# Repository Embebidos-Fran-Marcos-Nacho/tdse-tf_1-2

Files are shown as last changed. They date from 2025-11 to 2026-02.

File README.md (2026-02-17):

# Dimmer + Switch (Ventilador & Luces)  
Control de ventilador y luces de línea (220 V) desde pared y vía Bluetooth

<div align="center">



**UNIVERSIDAD DE BUENOS AIRES**  
**Facultad de Ingeniería**  
**TA134 – Sistemas Embebidos**  
Curso 1 – Grupo 2

</div>

## Autores
- Ignacio Ezequiel Cavicchioli — Legajo 109428  
- Francisco Javier Moya — Legajo 109899  

---

# 1. Selección del proyecto a implementar

## 1.1 Objetivo del proyecto y resultados esperados

Este proyecto implementa un módulo de control de **ventilador** y **luces de línea (220 V)** que permite operar:

- Desde la pared, por medio de un **botón físico** y un **potenciómetro**  
- Desde un dispositivo móvil mediante **Bluetooth (MIT App Inventor)**

Resultados esperados:

- Control de velocidad del ventilador.  
- Encendido/apagado de luces y ventilador.  
- Feedback mediante **LEDs** y **buzzer** para estados y alertas.  
- Permitir **deshabilitar o configurar el BT** mediante un DIP switch.  
- Guardado en memoria del último estado usado.  
- Funcionamiento seguro sobre cargas de 220 V.

---

## 1.2 Proyectos similares

Para establecer un punto de referencia, se identificaron dos soluciones comerciales que resuelven parcialmente el mismo problema que aborda este proyecto. Ambas están disponibles en el mercado, pero presentan diferencias significativas respecto al sistema que se busca implementar.

1. **Ventilador con control remoto IR/RF**  
   Existen en el mercado local ventiladores controlados por control remoto dedicado. 
   Este tipo de control funciona correctamente, pero presenta limitaciones importantes:
   - Solo tiene control remoto, no tiene control fijo. 
   - No ofrece conectividad con el celular.  
   - No guarda configuraciones ni estados previos del ventilador.  
   - Solo tiene 3 velocidades de ventilador. 

2. **Controladores disponibles internacionalmente (Amazon)**  
   En el mercado internacional existen productos más avanzados, capaces de integrar control de luces y ventilador, conectividad Wi-Fi, y aplicaciones móviles.  
   Sin embargo:
   - Tienen costos significativamente más altos o no cuentan con disponibilidad local inmediata. 
   - En general los que usan wi-fi no tienen tecla y representan una amenaza a la seguridad de la red doméstica del usuario.  

   Estos dispositivos representan lo más cercano al objetivo del proyecto, pero no resultan accesibles para implementarlos o utilizarlos en el contexto local.

En resumen, el proyecto actual se inspira en estas dos líneas de productos, combinando:
- la disponibilidad y simpleza de los controles remotos comerciales locales  
- con la funcionalidad avanzada de los módulos inteligentes que existen internacionalmente  

pero proponiendo una solución **propia, accesible y adaptada al entorno de trabajo de la materia.**

---

## 1.3 Selección de proyecto

La elección del proyecto se fundamenta en una combinación de requerimientos de la consigna, viabilidad técnica y practicidad.

En primer lugar, la cátedra establece como objetivo diseñar un sistema embebido con interacción física y comunicación inalámbrica. Dentro de las alternativas disponibles, el uso de **Bluetooth** se alineó naturalmente con el entorno de desarrollo provisto (MIT App Inventor Companion), permitiendo crear una aplicación funcional sin complejidades de red o protocolos avanzados.

### Razones para no usar Wi-Fi
- Presenta mayor complejidad en configuración, seguridad y mantenimiento de la conexión.  
- Requiere infraestructura adicional (router, red doméstica).  
- Demanda más recursos del microcontrolador.  
- Implica un ciclo de desarrollo más largo, poco compatible con los tiempos del proyecto académico.
- Un dispositivo mal diseñado podría volverse una vulnerabilidad en la red. 

Por ello, Bluetooth resultó ser la opción más equilibrada entre simplicidad, robustez y disponibilidad de herramientas.

### Comparación frente a otras alternativas
- **Control manual únicamente:** No cumple con los requisitos de conectividad inalámbrica definidos por la materia.  
- **Controles RF dedicados:** Los módulos de control remoto comercialmente disponibles para plataformas como Arduino son convenientes para el usuario final, pero no ofrecen un entorno de desarrollo ni la flexibilidad pedagógica necesaria.  
- **Soluciones comerciales completas:** No permiten aprendizaje, programación ni adaptación; además, suelen tener costos elevados o disponibilidad limitada.

### Consideración personal / diseño ideal
En un escenario de producto comercial real, probablemente sería más cómodo utilizar un control **RF dedicado**, especialmente para el uso nocturno (por ejemplo, tener un control en la mesa de luz).  
Sin embargo, dadas las restricciones del proyecto académico y los objetivos de aprendizaje, la elección de Bluetooth y una aplicación móvil resulta la opción más adecuada y formativa.

En conclusión, este proyecto se seleccionó porque:
- cumple con los requerimientos de la materia  
- permite un diseño flexible y completamente programable  
- evita la complejidad innecesaria del Wi-Fi  
- se inspira en productos reales tanto locales como internacionales  
- y aporta una solución integrada para luz + ventilador, que no se encuentra fácilmente en el mercado argentino

---

### 1.3.1 Diagrama en bloques

<div align="center">
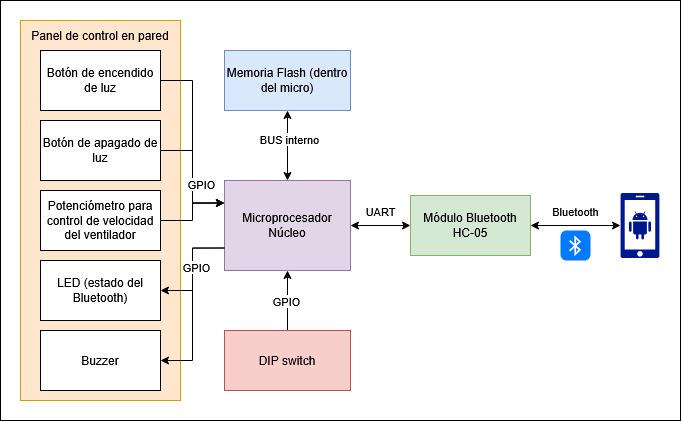
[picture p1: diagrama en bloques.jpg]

</div>

---

# 2. Elicitación de requisitos y casos de uso

## 2.1 Requisitos del proyecto

A continuación se presenta una tabla de requisitos:

### Tabla de requisitos

| Grupo | ID | Descripción |
|---|-----|---|
| Control | 1.1 | El sistema permitirá encender y apagar las **luces** mediante un botón físico. |
|  | 1.2 | El sistema permitirá ajustar la **velocidad del ventilador** mediante un potenciómetro. |
|  | 1.3 | El sistema permitirá controlar el ventilador y las luces vía **Bluetooth**. |
| Bluetooth | 2.1 | El sistema contará con un DIP switch para habilitar o deshabilitar el Bluetooth. |
|  | 2.2 | El DIP switch permitirá seleccionar diferentes **configuraciones o canales** del módulo BT. |
| Indicadores | 3.1 | El sistema contará con **LEDs** que indiquen el estado de conexión del Bluetooth. |
|  | 3.2 | El sistema contará con un **buzzer** para señalizar eventos del Bluetooth. |
| Memoria | 4.1 | El sistema deberá guardar en **memoria flash interna** el último valor de PWM utilizado. |
|  | 4.2 | El sistema deberá restaurar automáticamente el último valor guardado al encender. |
| Seguridad | 5.1 | El sistema deberá operar de forma segura sobre cargas de **220 V**. |
| Aplicación | 6.1 | La aplicación móvil deberá permitir realizar todas las acciones disponibles desde los controles físicos (encendido/apagado de luces y ajuste de velocidad del ventilador). |
|  | 6.2 | El sistema deberá garantizar que el control físico y el control desde la aplicación sean intercambiables: cuando se utilice uno, el otro deberá quedar temporalmente inhabilitado para evitar conflictos de comando. |
---
<!-- |  | 5.2 | El sistema deberá contar con mecanismos de protección ante **sobretemperatura**. | -->

## 2.2 Casos de uso

A continuación se presentan los casos de uso siguiendo el formato del archivo ejemplo.

### Caso de uso 1: Control manual desde la pared

| Elemento | Definición |
|---|---|
| **Disparador** | El usuario presiona el botón físico o ajusta el potenciómetro. |
| **Precondiciones** | El sistema está correctamente alimentado y los módulos están inicializados. |
| **Flujo principal** | El usuario presiona el botón para encender/apagar las luces o gira el potenciómetro para controlar el ventilador. |
---

### Caso de uso 2: Control remoto desde el celular vía Bluetooth

| Elemento | Definición |
|---|---|
| **Disparador** | El usuario abre la aplicación móvil y se conecta al dispositivo mediante Bluetooth. |
| **Precondiciones** | El DIP switch debe habilitar el Bluetooth. El sistema debe estar energizado y en estado operativo. |
| **Flujo principal** | El usuario enciende o apaga las luces y ajusta la velocidad del ventilador desde la aplicación. El sistema recibe los comandos, actualiza el estado interno y modifica las salidas correspondientes. Los indicadores visuales y acústicos reflejan los cambios realizados. |
| **Flujos alternativos** | a) Si el sistema recibe un comando Bluetooth con un **formato inválido**, incompleto o con una estructura distinta a la esperada, el comando se **descarta** y el sistema mantiene el **último estado validado recibido por Bluetooth**.  <br> b) Si durante el funcionamiento se **pierde la conexión Bluetooth**, el sistema conserva el **último estado válido recibido** antes de la desconexión, sin restaurar el modo manual ni cambiar de fuente de control. <br> c) Si el Bluetooth está apagado por DIP switch al intentar conectar, la aplicación no podrá interactuar con el dispositivo. |

### Caso de uso 3: Restauración del último estado guardado

| Elemento | Definición |
|---|---|
| **Disparador** | El sistema se energiza o se reinicia. |
| **Precondiciones** | Debe existir al menos un valor previo guardado en memoria. |
| **Flujo principal** | El sistema lee la memoria flash interna y restaura el último valor de PWM utilizado antes del apagado. El ventilador y/o las luces vuelven al estado correspondiente a ese valor. La aplicación móvil, si se conecta, puede consultar o sincronizar este estado restaurado. |
| **Flujos alternativos** | a) Si la memoria está **vacía**, contiene un valor **inválido**, o los datos resultan **corruptos**, el sistema descarta la lectura y utiliza un **preset de seguridad** en el que tanto las luces como el ventilador permanecen **apagados**. <br> b) Si la memoria resulta **inaccesible** por falla interna, el sistema también entra en el estado seguro con todo apagado, operando únicamente bajo comandos manuales o Bluetooth posteriores. |

---

# 3. Descripción general del sistema

## 3.1 Funcionalidades principales

- Control manual mediante botón y potenciómetro.  
- Control remoto vía Bluetooth.  
- Indicadores LED y buzzer para estados del sistema y del Bluetooth.  
- Memoria interna para restaurar el estado previo.  
- DIP Switch para configurar o deshabilitar el Bluetooth.  
- Operación segura sobre línea de 220 V.

---

# 4. Uso del sistema

## 4.1 Uso manual desde la pared

- Botón físico → encendido/apagado de luces.  
- Potenciómetro → ajuste de velocidad del ventilador.  
- LEDs indican estado del Bluetooth.  

## 4.2 Control desde la app

- Conectarse vía Bluetooth.  
- Encender/apagar luces y ventilador.  
- Ajustar nivel PWM.  
- La app puede mostrar el último valor de PWM restaurado automáticamente.

## 4.3 Telemetría Bluetooth (STM32 -> App)

- El firmware envía un frame binario fijo de **2 bytes** por USART1 (HC-06).
- Formato del frame:
  - Byte 0: `adc_percent` (valor `0..100`).
  - Byte 1: `light_enabled` (`0` = luz apagada, `1` = luz encendida).
- Los bytes se envían en ese orden, sin JSON y sin separadores de texto.
- Para MIT App Inventor, se recomienda leer exactamente 2 bytes por muestra y parsearlos como enteros sin signo de 8 bits.

---

# 5. Configuración (DIP switch)

- **DIP1:** Habilitar o deshabilitar Bluetooth.  
- **DIP2–DIP4:** Configuración del canal o modo del módulo BT.

---

# 6. Cronograma estimado

No se prevé la terminación del TP para diciembre.  
El primer avance se presentará entre enero y febrero de 2026.

---

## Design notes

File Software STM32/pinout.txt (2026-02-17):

PA0   -> Potenciómetro (ADC)

PC0   -> DIP switch 1
PC1   -> DIP switch 2
PB0   -> DIP switch 3
PA4   -> DIP switch 4

PC12  -> Botón 1
PC9   -> Botón 2

PC2   -> ZCS – cruce por cero (EXTI2)

PB3 -> TRIAC 1 (GPIO Output)
PB4 -> TRIAC 2 (GPIO Output)

PA9   -> USART1_TX  → conectar al RX del Bluetooth
PA10  -> USART1_RX  → conectar al TX del Bluetooth

PB13  -> LED

PA8   -> Buzzer (TIM1_CH1, salida por timer)

PC8   -> Señal de prueba/debug 100 Hz (solo modo test)

potenciómetro usa 3.3V
GW040 VCC  -> +5V
GW040 GND  -> GND

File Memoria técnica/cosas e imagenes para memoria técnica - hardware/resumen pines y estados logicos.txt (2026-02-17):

RESUMEN DE PINES Y ESTADOS LOGICOS (STM32F103RB)
=================================================

Entradas DIP
------------
PC0 (DIP1) - Habilitacion Bluetooth
- 0: Bluetooth deshabilitado
- 1: Bluetooth habilitado

PC1 (DIP2) - Habilitacion Buzzer
- 0: buzzer deshabilitado
- 1: buzzer habilitado

PB0 (DIP3) - Habilitacion LED
- 0: LED deshabilitado (forzado apagado)
- 1: LED habilitado

PA4 (DIP4) - Reservado / prueba
- 0: normal
- 1: en APP_TEST_MODE fuerza entrada a estado FAULT

Entradas de usuario/sensores
----------------------------
PC12 (BOT1) - Boton principal (debounced)
- activo en 0 (presionado)
- suelto en 1
- accion: enciende la luz (ON)

PC9 (BUT2) - Boton auxiliar (debounced)
- activo en 0 (presionado)
- suelto en 1
- accion: apaga la luz (OFF)

PC2 (ZCD_INT) - Detector de cruce por cero (EXTI)
- flanco ascendente = evento de cruce por cero

PA0 (POTENTIOMETER) - ADC de potenciómetro
- 0..4095 (0 a 3.3V)

Salidas
-------
PB3 (TRIAC1) - Gate TRIAC (fan)
- 0: gate apagado
- 1: pulso de disparo

PB4 (TRIAC2) - Gate TRIAC (luz)
- 0: gate apagado
- 1: pulso de disparo

PB13 (LED)
- 0: apagado
- 1: encendido

PA8 (BUZZER / TIM1_CH1)
- PWM ~2 kHz en estado FAULT (si DIP2=1)
- 0% duty: sin sonido

Comunicacion
------------
PA9 (USART1_TX) / PA10 (USART1_RX) - Modulo Bluetooth HC-06
- UART de datos BT

PA2 (USART2_TX) / PA3 (USART2_RX) - ST-Link VCP (consola USB a PC)
- UART de logs / serial console

Pin de prueba
-------------
PC8 (TEST_WAVE_100HZ)
- APP_TEST_WAVE_100HZ_PIN=1: cuadrada de 100 Hz
- APP_TEST_WAVE_100HZ_PIN=0: nivel bajo fijo

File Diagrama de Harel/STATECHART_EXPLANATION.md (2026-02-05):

# Documentación Técnica: Statechart de Control (Luz/Ventilador)

## Resumen

Este documento detalla la implementación de la lógica de control para el módulo de **Dimmer + Switch (TA134)**. El sistema está modelado en Itemis CREATE (YAKINDU) utilizando un enfoque estrictamente orientado a eventos (`@EventDriven`) para minimizar el consumo de CPU y latencia.

La arquitectura desacopla la lógica de negocio (máquina de estados) de los drivers de hardware (C/C++) mediante una interfaz abstracta de eventos y operaciones.

---

## 1. Configuración del Modelo de Ejecución

Para reproducir el comportamiento en el target, el statechart utiliza las siguientes directivas:

- **`@EventDriven`**: La máquina reacciona asincrónicamente a interrupciones y eventos de hardware.
- **`@SuperSteps(no)`**: Se deshabilita la semántica de "run-to-completion" infinita para evitar bucles de ejecución bloqueantes.
- **Gestión de Tiempo**: Se utilizan timers internos (`after 1s`) para timeouts de seguridad (Watchdog lógico).

---

## 2. Arquitectura de Estados (Top-Level)

El sistema se orquesta en un único estado raíz "**Blink**" que contiene tres sub-máquinas exclusivas.

### 2.1. Secuencia de Boot (Init_ST)

Estado compuesto secuencial. Actúa como un Self-Test de encendido. Bloquea la operación normal hasta que todos los periféricos reporten estado OK. Los periféricos incluyen los estados iniciales de la memoria flash, el bluetooth, el PWM, etc.  

#### Flujo de Validación:

El sistema espera eventos de confirmación (true) de las siguientes banderas para transicionar:

| Paso | Estado | Señal Esperada (Input) | Acción en Falla |
|---|---|---|---|
| 1 | ST_READ_FLASH | `init_flash_ok` | Salto a Fault_ST |
| 2 | ST_READ_DIP | `init_dip_ok` | Salto a Fault_ST |
| 3 | ST_CHECK_SENSORS | `init_sensors_ok` | Salto a Fault_ST |
| 4 | ST_RESTORE_PWM | `init_pwm_ok` | Salto a Fault_ST |
| 5 | ST_CONFG_BT | `init_bt_ok` | Salto a Normal_ST |

**Nota para Simulación:** Debes forzar estas variables a `true` secuencialmente para salir del boot.

---

### 2.2. Modo Seguro (Fault_ST)

Estado de error recuperable.

**Safety First:** Al entrar (entry), se ejecuta `cut_off_voltage = true` para desenergizar triacs y relés inmediatamente.

**Feedback:** Loop infinito de 1Hz (500ms ON / 500ms OFF) activando LED y Buzzer.

**Watchdog Lógico:** Tras 10 segundos (`after 10s`) sin intervención, el sistema intenta un Soft Reset volviendo a Init_ST.

---

### 2.3. Runtime (Normal_ST)

Aquí reside la lógica principal. Se implementa mediante **Regiones Ortogonales (Paralelismo)** para separar el debounce del control lógico.

#### Región A: Lógica de Control (Main Loop)

Estado simple `ST_IDLE_MANUAL`. Implementa el patrón **Local-First con Notificación**:

- El sistema siempre prioriza la entrada física.
- El Bluetooth es pasivo: solo recibe notificaciones de cambio de estado.

**Transiciones (Self-Transitions):**

1. **Toggle Luz:** Al recibir `EV_SYS_PRESSED` (evento limpio), invierte el estado y dispara `EV_SEND_BT_UPDATE`.
2. **Ajuste PWM:** Al recibir `EV_POTE_CHANGED` (evento de cambio en ADC), actualiza el valor y dispara `EV_SEND_BT_UPDATE`.

#### Región B: Driver de Botón (Software Debounce)

Máquina de estados dedicada para filtrar ruido mecánico.

**Algoritmo:** Contador de histéresis (`tick`).

- **Input:** Eventos crudos `EV_BTN_PRESSED` (interrupción pin change).
- **Output:** Evento limpio `EV_SYS_PRESSED` (solo se dispara cuando `tick` llega a 0).

**Ventaja:** Permite ajustar la sensibilidad del botón sin tocar la lógica de control de la luz.

---

## 3. Definición de Interfaz (API)

Esta es la referencia para el mapeo con el código C (`main.c` / `hardware.c`).

### Inputs (Hardware → Statechart)

| Evento/Variable | Tipo | Descripción |
|---|---|---|
| `ST_INIT_*_OK` | event | Flags de resultado positivo de inicialización de periféricos. |
| `ST_INIT_*_NOT_OK` | event | Flags de resultado negativo de inicialización de periféricos. |
| `EV_BTN_PRESSED` | event | Interrupción de flanco (ruidosa). |
| `EV_POTE_CHANGED` | event | Notificación del ADC (cambio > umbral de histéresis). |
| `EV_BT_CONNECTED` | event | Status del módulo HC-05 (actualmente solo informativo). |

### Outputs (Statechart → Hardware)

| Evento/Operación | Tipo | Acción Requerida en C |
|---|---|---|
| `EV_SYS_PRESSED` | event | Evento interno (generalmente no requiere acción externa salvo debug). |
| `EV_SEND_BT_UPDATE` | out event | Trigger para enviar trama por UART. |
| `cut_off_voltage` | var | Si es `true`, poner pines de potencia en LOW. |
| `toggle_light` | var | Mapear al GPIO del Relé. |
| `pwm_val` | var | Mapear al registro OCR del Timer (PWM). |

---

## 4. Workflow de Simulación (How-To)

Para validar la lógica sin hardware, sigue estos pasos en Itemis:

### Paso 1: Iniciar la Simulación

1. **Run:** Click derecho en el canvas → **Run As** → **Statechart Simulation**.
2. Se verá el estado atrapado en `Init_ST`.

### Paso 2: Secuencia de Boot

1. En la vista **Simulation** (derecha), buscar los eventos:
   - `ST_INIT_*_OK`
   - `ST_INIT_*_NOT_OK`

2. Presionar `ST_INIT_*_OK` una por una y se transicionará por los estados hasta llegar a `Normal_ST`.

### Paso 3: Prueba de Botón (Debounce)

1. En Simulation, hacer clic repetidamente en `EV_BTN_PRESSED`.
2. Observar la región `ST_BTN`: se verá el estado pasar a `FALLING` y el contador `tick` decrementarse.
3. Se necestia de varios clics (simulando ruido/tiempo) para que se dispare finalmente `EV_SYS_PRESSED` y ver cambiar la variable `toggle_light` en la región superior.

### Paso 4: Prueba de Falla

1. Reiniciar la simulación.
2. En medio del init, presionar un `ST_INIT_*_NOT_OK`.
3. Verificar que entre a `Fault_ST` y que las variables `led_on` / `buzzer_on` oscilen.

---

## 5. Diagrama de Flujo de Estados

```
┌─────────────┐
│   ENTRADA   │
└──────┬──────┘
       │
       ▼
┌──────────────────────────────────────┐
│         Init_ST (Secuencial)         │
│  ┌────────────────────────────────┐  │
│  │ Flash → DIP → Sensores →       │  │
│  │ PWM → BT (validaciones)        │  │
│  └────────────────────────────────┘  │
└──────┬───────────────┬────────────────┘
       │ Todo OK       │ Cualquier Fallo
       │               │
       ▼               ▼
┌─────────────┐  ┌─────────────────────┐
│ Normal_ST   │  │  Fault_ST           │
│ ┌─────────┐ │  │  ┌───────────────┐  │
│ │ Control ├─┼──┼──┤ Bucle Alerta  │  │
│ │ & Botón │ │  │  │ (1Hz toggle)  │  │
│ └─────────┘ │  │  └───────────────┘  │
└─────────────┘  │                      │
                 │ (10s timeout)       │
                 └──────────┬───────────┘
                            │
                            └─→ Init_ST (reintentar)
```

---
## Referencias

- **YAKINDU Statechart Tools:** https://www.itemis.com/en/yakindu/statechart-tools/
- **Itemis CREATE:** Entorno integrado para modelado y generación de código.
- **SCT Code Generator:** Convierte modelos a C/C++/Java.

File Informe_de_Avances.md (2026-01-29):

# Dimmer + Switch (Ventilador & Luces)  
Control de ventilador y luces de línea (220 V) desde pared y vía Bluetooth

<div align="center">

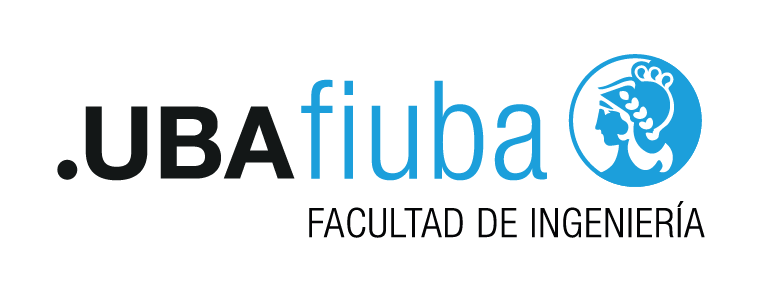
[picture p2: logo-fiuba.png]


**UNIVERSIDAD DE BUENOS AIRES**  
**Facultad de Ingeniería**  
**TA134 – Sistemas Embebidos**  
Curso 1 – Grupo 2

</div>

## Autores
- Ignacio Ezequiel Cavicchioli — Legajo 109428  
- Francisco Javier Moya — Legajo 109899  

**Fecha:** 25/01/2026  
**Cuatrimestre de cursada:** 2do cuatrimestre 2025  

---

## 1. Introducción

El presente documento corresponde al **informe de avance** del proyecto *Dimmer + Switch (Ventilador & Luces)*, desarrollado en el marco de la materia **TALLER DE SISTEMAS EMBEBIDOS (TA134)**.

El objetivo de este informe es detallar el **estado actual de implementación** del sistema respecto a los **requisitos definidos en el README del proyecto**, identificando qué funcionalidades se encuentran implementadas, cuáles están en desarrollo y cuáles no de podrán abordar o deberán ser cambiadas por restricciones de tiempo.

---

## 2. Convenciones de estado

A continuación se detallan las convenciones utilizadas para indicar el estado de cada requisito:

| Estado | Descripción |
|---|---|
| 🟢 | Implementado |
| 🟡 | En proceso de implementación |
| 🔴 | No implementado / descartado |

Comentarios:
Se consideran "En proceso de implementación" aquellas _features_ que estén en el Diagrama de Harel. 

---

## 3. Avance por grupo de requisitos

### 3.1 Control

| ID | Descripción | Estado de implementación - Hardware | Estado de implementación - Software |
|---|---|---|---|
| 1.1 | El sistema permitirá encender y apagar las luces mediante un botón físico. | 🟢 | 🟡 |
| 1.2 | El sistema permitirá ajustar la velocidad del ventilador mediante un potenciómetro. | 🟢 | 🟡 |
| 1.3 | El sistema permitirá controlar el ventilador y las luces vía Bluetooth. | 🟢 | 🔴 |

#### Comentarios:
Por un lado, los ítems 1.1 y 1.2 se encuentran en proceso de desarrollo, y ya están implementados en el Hardware del proyecto. Por otro lado, por limitaciones de tiempo, el ítem 1.3 se deberá cambiar a lo siguiente: 
- 1.3: "El sistema permitirá ver el estado del ventilador y las luces vía Bluetooth."

Se espera que este cambio reduzca la dificultad/tiempo de la implementación de una aplicación en MIT App Inventor. 

---

### 3.2 Bluetooth

| ID | Descripción | Estado de implementación - Hardware | Estado de implementación - Software |
|---|---|---|---|
| 2.1 | El sistema contará con un DIP switch para habilitar o deshabilitar el Bluetooth. | 🟢 | 🟡 |
| 2.2 | El DIP switch permitirá seleccionar configuraciones o canales del módulo Bluetooth. | 🟢 | 🟡 |

#### Comentarios:
Se prevé el uso del dip switch como fue planteado inicialmente. 

---

### 3.3 Indicadores

| ID | Descripción | Estado de implementación - Hardware | Estado de implementación - Software |
|---|---|---|---|
| 3.1 | El sistema contará con LEDs que indiquen el estado del Bluetooth. | 🟢 | 🟡 |
| 3.2 | El sistema contará con un buzzer para señalizar eventos del sistema. | 🟢 |🟡 |

#### Comentarios:
No se prevén cambios en esta sección. 

---

### 3.4 Memoria

| ID | Descripción | Estado de implementación - Hardware | Estado de implementación - Software |
|---|---|---|---|
| 4.1 | El sistema deberá guardar en memoria flash el último valor de PWM utilizado. | 🟢 | 🟡 |
| 4.2 | El sistema deberá restaurar automáticamente el último valor guardado al encender. | 🟢 | 🟡 |

#### Comentarios:
El microprocesador ya dispone de su propia memoria flash, por lo que solo resta completar la implementación en software. 

---

### 3.5 Seguridad eléctrica

| ID | Descripción | Estado de implementación - Hardware | Estado de implementación - Software |
|---|---|---|---|
| 5.1 | El sistema deberá operar de forma segura sobre cargas de 220 VAC. | 🟡 | N/A |

#### Comentarios:
Este ítem está en proceso de evaluación. 

---

### 3.6 Aplicación móvil

| ID | Descripción | Estado de implementación - Hardware | Estado de implementación - Software |
|---|---|---|---|
| 6.1 | La aplicación permitirá realizar todas las acciones disponibles desde los controles físicos.| N/A | 🔴 |
| 6.2 | El sistema deberá evitar conflictos entre control físico y control Bluetooth.| N/A | 🔴 |

#### Comentarios:

Dados los cambios realizados sobre el ítem 1.3, se proponen las siguientes modificaciones:
- 6.1: "La aplicación dará información sobre los estados disponibles, que incluyen la velocidad del ventilador, estado de luces, etc.".
- 6.2: "El sistema deberá evitar conflictos entre el control físico y la comunicación Bluetooth.". Esto abarca conflictos de _timings_. 

---

## 4. Resumen

A la fecha de este informe, el proyecto se encuentra en una **etapa intermedia de desarrollo**, con los siguientes avances generales:

- Definición completa del alcance y requisitos del sistema.  
- Selección de arquitectura general y módulos principales.  
- Hardware en proceso de evaluación. Esto incluye 2 placas, una de controles y otra de triacs (220 VAC).  

Actualmente se están terminando de diagramar los Diagramas de Harel. Una vez terminados y aprobados por el cuerpo docente, se procedería a desarrollar el Software propiamente dicho. 

---

## 5. Observaciones importantes

Ambos estudiantes, Francisco e Ignacio, nos encontramos realizando pasantías desde el cuatrimestre pasado, las cuales insumen una porción significativa del tiempo semanal y requieren un margen razonable de descanso, especialmente considerando que el año previo fue dedicado íntegramente al estudio y trabajo.

A ello se suma el inicio del período de evaluaciones de febrero/marzo, durante el cual debemos rendir finales de otras asignaturas y cumplir con la entrega de trabajos pendientes. En particular, Francisco debe rendir dos exámenes finales, mientras que Ignacio debe presentar una monografía y desarrollar el trabajo práctico profesional, aprovechando el receso del período lectivo.

Nos encontramos avanzando de manera sostenida con el trabajo; sin embargo, dadas las circunstancias mencionadas, no es posible sostener una dedicación intensiva de forma continua, considerando que ya venimos trabajando a un ritmo elevado desde el cuatrimestre anterior. En este contexto, resulta además irregular que la materia no cuente con el período de 15 fechas de finales que sí poseen el resto de las asignaturas (y que han tenido alumnos de esta misma materia cuatrimestres pasados), lo cual comprime aún más los tiempos disponibles y limita la posibilidad de una planificación equilibrada del esfuerzo.

Queremos aclarar que nos resulta incómodo tener que plantear esta situación, y que lo hacemos con el mayor respeto hacia el cuerpo docente y hacia el trabajo que realizan. Sin embargo, consideramos importante acercar esta observación de manera constructiva, ya que entendemos que la organización actual impacta de forma significativa en nuestros tiempos y podría resultar también injusta para futuros alumnos de la materia. Nuestro objetivo es únicamente poner en conocimiento esta dificultad, con la intención de que pueda ser tenida en cuenta en instancias posteriores.

---

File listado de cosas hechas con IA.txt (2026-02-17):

Ignacio: 
1. Le pasamos una memoria técnica de las de ejemplo y le pedimos que extraiga el esqueleto de secciones y subsecciones para poder empezar a completar nuestro documento.
2. Lo ya discutido sobre el readMe
3. En el hardware se usó como asesor de buenas prácticas y para elección de componentes, siendo el uso de triacs algo nuevo. No ayudó demaasiaado con los snubbers, todavía le cuesta eso 
4. Informe de avances genérico en base a los de ejemplo, luego se ajustó a nuestros avances y proyecto.

Francisco:
1. Se utilizó Gemini 3.0 como soporte técnico para el manejo de Itemis Create y para optimizar la eficiencia de los flujos del diagrama.
2. Se empleó Claude para generar la estructura base del archivo STATECHART_EXPLANATION.md, la cual fue revisada y corregida manualmente por nosotros.
4. Informe de avences genérico en base a los de ejemplo, luego se ajustó a nuestros avances y proyecto. 

Común:
1. Memoria técnica - usandoe l modo agente del repositorio se armó la memoria técnica que cumpla con todos los requerimientos. 
2. código del stm32
3. Se armó con IA (Codex) la descripción del Pull Request para mergear la branch actual con main.
4. Se usó IA para apoyar prácticamente toda la programación del software STM32 (estructura, módulos y ajustes finales), con validación y corrección manual del equipo.
5. Estimación de costo de IA para este trabajo: bajo (aprox. USD 0 a USD 10 en total, según plan/herramienta usada).

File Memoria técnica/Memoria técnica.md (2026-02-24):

<div align="center">



**UNIVERSIDAD DE BUENOS AIRES**  
**Facultad de Ingeniería**  
**TA134 – Sistemas Embebidos**  
Curso 1 – Grupo 2

# Dimmer + Switch (Ventilador & Luces)  
Control de ventilador y luces de línea (220 V) desde pared y vía Bluetooth

## Autores
Ignacio Ezequiel Cavicchioli — Legajo 109428  
Francisco Javier Moya — Legajo 109899  

**Fecha:** 25/01/2026  
**Cuatrimestre de cursada:** 2do cuatrimestre 2025  

*Trabajo realizado entre diciembre 2025 y febrero 2026.*
</div>

---

## Resumen

Se desarrolló un sistema embebido para control de luz y ventilador de red (220 VAC), con:
- Control local por pulsadores y potenciómetro.
- Telemetría por Bluetooth con módulo HC-06.
- Sincronización por cruce por cero.
- Almacenamiento persistente en flash interna del STM32.

El hardware se implementó en dos placas (shield de control y placa de potencia/dimmer), evitando protoboard y cableado Dupont para la integración final. La única excepción es el uso de leds en paralelo con los bulbos de luz requeridos en las pruebas de potencia; la tensión no es suficiente como para encenderlos, por lo que se usaron leds en paralelo como indicadores. 
El firmware se implementó en una NUCLEO-F103RB con arquitectura modular de tareas y máquina de estados para modos de inicialización, operación normal y falla segura.

Esta memoria documenta los requisitos, el diseño de hardware y firmware, los ensayos realizados y el estado final de cumplimiento. 

---

## Registro de versiones

*Historial de revisiones del documento.*

La Tabla 0.1 resume el historial de revisiones y entregas de esta memoria.

| Revisión | Cambios realizados | Fecha |
| :---: | --- | :---: |
| 1.0 | Reescritura integral de la memoria, alineada a pautas de entrega final | 17/02/2026 |
| 1.1 | Completar con mediciones de consumo, WCET y factor de uso CPU | 17/02/2026 |
| 1.2 | Completar con permalinks definitivos de imágenes y link de video | 17/02/2026 |
| 1.2 | Entrega N°1 | 17/02/2026 |
| 1.3 | Correcciones según devolución de primer entrega| 19/02/2026 |
| 1.4 | Entrega N°2 | 19/02/2026 |
| 1.5 | Correcciones según devolución de segunda entrega | 20/02/2026 |

<em>Tabla 0.1 — Registro de versiones del documento.</em><br><br>

---

# Índice General

- [Capítulo 1: Introducción general](#capítulo-1-introducción-general)
  - [1.1 Análisis de necesidad y objetivo](#11-análisis-de-necesidad-y-objetivo)
  - [1.2 Productos comparables](#12-productos-comparables)
  - [1.3 Justificación del enfoque técnico](#13-justificación-del-enfoque-técnico)
  - [1.4 Alcance y limitaciones](#14-alcance-y-limitaciones)
- [Capítulo 2: Introducción específica](#capítulo-2-introducción-específica)
  - [2.1 Requisitos](#21-requisitos)
  - [2.2 Casos de uso](#22-casos-de-uso)
    - [2.2.1 Control local de luz](#221-control-local-de-luz)
    - [2.2.2 Ajuste local de ventilador](#222-ajuste-local-de-ventilador)
    - [2.2.3 Telemetría Bluetooth hacia app](#223-telemetría-bluetooth-hacia-app)
    - [2.2.4 Recuperación tras falla](#224-recuperación-tras-falla)
  - [2.3 Descripción de módulos principales](#23-descripción-de-módulos-principales)
    - [2.3.1 Módulo de control (NUCLEO-F103RB)](#231-módulo-de-control-nucleo-f103rb)
    - [2.3.2 Módulo de potencia (dimmer)](#232-módulo-de-potencia-dimmer)
    - [2.3.3 Módulo de detección de cruce por cero (ZCD)](#233-módulo-de-detección-de-cruce-por-cero-zcd)
    - [2.3.4 Módulo Bluetooth (HC-06)](#234-módulo-bluetooth-hc-06)
    - [2.3.5 Aplicación móvil (MIT App Inventor)](#235-aplicación-móvil-mit-app-inventor)
- [Capítulo 3: Diseño e implementación](#capítulo-3-diseño-e-implementación)
  - [3.1 Arquitectura general](#31-arquitectura-general)
  - [3.2 Diseño de hardware](#32-diseño-de-hardware)
    - [3.2.1 Criterio de interconexión y montaje](#321-criterio-de-interconexión-y-montaje)
    - [3.2.2 Etapa de conversión de niveles](#322-etapa-de-conversión-de-niveles)
    - [3.2.3 Etapa de TRIACs](#323-etapa-de-triacs)
    - [3.2.4 Etapa ZCD (detección de cruce por cero)](#324-etapa-zcd-detección-de-cruce-por-cero)
    - [3.2.5 Etapa de potencia y protecciones](#325-etapa-de-potencia-y-protecciones)
    - [3.2.6 Fabricación de placas](#326-fabricación-de-placas)
    - [3.2.7 Pinout del sistema (STM32F103RB)](#327-pinout-del-sistema-stm32f103rb)
    - [3.2.8 Cableado e imágenes del montaje](#328-cableado-e-imágenes-del-montaje)
  - [3.3 Diseño de firmware](#33-diseño-de-firmware)
    - [3.3.1 Arquitectura de ejecución](#331-arquitectura-de-ejecución)
    - [3.3.2 Máquina de estados del sistema](#332-máquina-de-estados-del-sistema)
    - [3.3.3 Entradas y acondicionamiento lógico](#333-entradas-y-acondicionamiento-lógico)
    - [3.3.4 Control de TRIAC y sincronización AC](#334-control-de-triac-y-sincronización-ac)
    - [3.3.5 Persistencia en flash](#335-persistencia-en-flash)
    - [3.3.6 Bluetooth HC-06](#336-bluetooth-hc-06)
    - [3.3.7 Aplicación móvil](#337-aplicación-móvil)
- [Capítulo 4: Ensayos y resultados](#capítulo-4-ensayos-y-resultados)
  - [4.1 Pruebas funcionales de hardware](#41-pruebas-funcionales-de-hardware)
  - [4.2 Pruebas funcionales de firmware](#42-pruebas-funcionales-de-firmware)
  - [4.3 Pruebas de integración](#43-pruebas-de-integración)
  - [4.4 Medición y análisis de consumo](#44-medición-y-análisis-de-consumo)
  - [4.5 Console and Build Analyzer](#45-console-and-build-analyzer)
  - [4.6 Medición y análisis de WCET por tarea](#46-medición-y-análisis-de-wcet-por-tarea)
  - [4.7 Cálculo del factor de uso de CPU (U)](#47-cálculo-del-factor-de-uso-de-cpu-u)
  - [4.8 Gestión de bajo consumo y justificación](#48-gestión-de-bajo-consumo-y-justificación)
  - [4.9 Cumplimiento de requisitos](#49-cumplimiento-de-requisitos)
  - [4.10 Comparación con sistemas similares](#410-comparación-con-sistemas-similares)
  - [4.11 Documentación del desarrollo realizado](#411-documentación-del-desarrollo-realizado)
- [Capítulo 5: Conclusiones](#capítulo-5-conclusiones)
  - [5.1 Resultados obtenidos](#51-resultados-obtenidos)
  - [5.2 Lecciones aprendidas](#52-lecciones-aprendidas)
  - [5.3 Próximos pasos](#53-próximos-pasos)
- [Capítulo 6: Uso de herramientas de IA](#capítulo-6-uso-de-herramientas-de-ia)
  - [6.1 Uso individual y conjunto](#61-uso-individual-y-conjunto)
- [Capítulo 7: Bibliografía y referencias](#capítulo-7-bibliografía-y-referencias)

---

# Capítulo 1: Introducción general

## 1.1 Análisis de necesidad y objetivo

El proyecto busca resolver una necesidad concreta de control de cargas de 220 VAC (luz y ventilador) desde una interfaz de pared, agregando telemetría inalámbrica sin depender de la red Wi-Fi doméstica.

Objetivos principales:
- Implementar un prototipo funcional y seguro de control de luz/ventilador.
- Usar una arquitectura modular en STM32.
- Tener persistencia de estado en la memoria flash.

## 1.2 Productos comparables

Se analizaron dos tipos de soluciones comerciales disponibles en la Argentina:

1. **Ventilador con control remoto IR/RF**  
   Existen en el mercado local ventiladores controlados por control remoto dedicado. 
   Este tipo de control funciona correctamente, pero presenta limitaciones importantes:
   - Solo tiene control remoto, no tiene control fijo. 
   - No ofrece conectividad con el celular.  
   - No guarda configuraciones ni estados previos del ventilador.  
   - El producto encontrado solo tiene 3 velocidades de ventilador (low, med, high). 

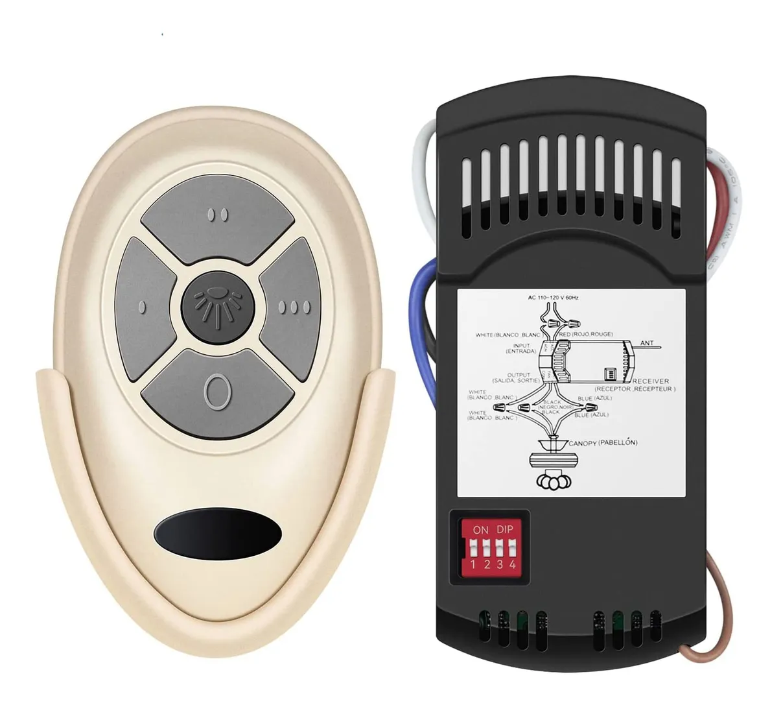
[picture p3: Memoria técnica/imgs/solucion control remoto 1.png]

<em>Figura 1.1 — Ventilador con control remoto IR/RF (referencia comercial).</em><br><br>

En la Figura 1.1 se observa el kit típico: un control remoto dedicado con soporte de pared y un módulo receptor que se instala en la caja de techo. Esta solución (encontrada en [Kit Corebay Fan-3 – Mercado Libre](https://www.mercadolibre.com.ar/kit-de-control-remoto-para-ventilador-de-techo-corebay-fan-3/p/MLA2061924708)) resuelve el control a distancia, pero no integra telemetría hacia el celular ni una interfaz fija de pared. Si se pierde el control remoto, o se olvida  en otro ambiente, el usuario tiene que buscarlo para poder controlar el ventilador y luz. 

2. **Controladores disponibles internacionalmente
)**  
   En el mercado internacional existen productos más avanzados, capaces de integrar control de luces y ventilador, conectividad Wi-Fi, y aplicaciones móviles.  
   Sin embargo:
   - Tienen costos significativamente más altos o no cuentan con disponibilidad local inmediata. 
   - En general los que usan Wi-Fi no tienen tecla y representan una amenaza a la seguridad de la red doméstica del usuario (si no está bien configurada).  

La Figura 1.2 muestra un producto más completo: combina control local (teclas de pared) con control remoto y/o aplicación móvil, normalmente mediante conectividad Wi‑Fi. Si bien aporta más funciones, su integración típica depende de la red Wi-Fi doméstica, excepto en el caso del control remoto, que nos parece el mejor. El producto se puede encontrar en: [Kit universal – Amazon](https://www.amazon.com/-/es/Control-universal-ventilador-interruptor-atenuador/dp/B0D95Y3Z11).<br>

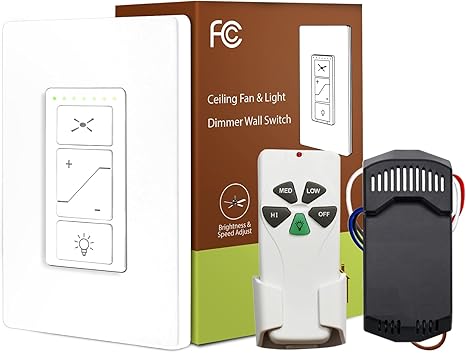
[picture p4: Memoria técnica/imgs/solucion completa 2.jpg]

<em>Figura 1.2 — Controlador integrado con teclas de pared y conectividad (referencia internacional).</em><br><br>

Para este proyecto se optó por utilizar una interfaz local combinada con un módulo Bluetooth clásico HC-06. Esta solución híbrida prioriza la simplicidad de integración, combinando la comodidad del control de pared con la telemetría inalámbrica por medio de bluetooth. La siguiente sección brinda más detalles sobre estas decisiones de diseño. 

## 1.3 Justificación del enfoque técnico

Se eligió Bluetooth clásico (HC-06) por:
- Menor complejidad de despliegue que Wi-Fi.
- Facilidad de integración con la app realizada en MIT App Inventor.
- Disponibilidad de herramientas de depuración por UART.

Se mantuvo un alcance acotado para cumplir entrega:
- La app móvil recibe telemetría binaria de 2 bytes.
- El control principal de actuadores se mantiene en interfaz local.

En una futura versión, el producto debería permitir el control por medio de la conexión inalámbrica, equiparandolo a la solución comercial mostrada más completa. 

## 1.4 Alcance y limitaciones

Alcance implementado:
- Encendido/apagado de luz por botones físicos.
- Ajuste de velocidad del ventilador por potenciómetro.
- Envío de telemetría por HC-06.
- Estado de falla segura y persistencia básica en flash.

Fuera de alcance actual:
- Control remoto completo de actuadores desde app. 
- Las pruebas de integración de potencia se realizaron con 24 VAC (banco), no con 220 VAC.
- La validación final sobre red de 220 VAC queda planificada como etapa posterior a la aprobación académica del trabajo, para reducir el riesgo durante la entrega.

Este tema se vuelve a detallar en la sección "4.9 Cumplimiento de requisitos", en la que se explica cada ítem y la razón de no haberse implementado, si corresponde. 

---

# Capítulo 2: Introducción específica

Esta sección contiene los requisitos originales y los modificados en el informe de avances, además de los casos de uso. 

## 2.1 Requisitos
En la Tabla 2.1 se listan los requisitos originalmente definidos al inicio del proyecto (versión base, incluida también en el [documento principal del repositorio](https://github.com/Embebidos-Fran-Marcos-Nacho/tdse-tf_1-2/blob/4b6e89fc72c10d777ce4164eac52042739fd6bfa/README.md)). Durante la elaboración del informe de avances (primera semana de febrero de 2026), el alcance se ajustó para asegurar una integración completa a tiempo para la entrega; dichos cambios se pueden ver en la Tabla 2.2, y se resumen a cambios en el control local y telemetría, reduciendo el alcance de funciones no críticas para la entrega. Particularmente, los requisitos alcanzados por las modificaciones son los 1.3, 6.1 y 6.2. 

Más adelante, en la sección "4.9 Cumplimiento de requisitos", se detalla si se cumplieron o no, y se da la razón en caso de no haberse implementado.

| Grupo | ID | Descripción |
|---|-----|---|
| Control | 1.1 | El sistema permitirá encender y apagar las luces mediante un botón físico. |
|  | 1.2 | El sistema permitirá ajustar la velocidad del ventilador mediante un potenciómetro. |
|  | 1.3 | El sistema permitirá controlar el ventilador y las luces vía Bluetooth. |
| Bluetooth | 2.1 | El sistema contará con un DIP switch para habilitar o deshabilitar el Bluetooth. |
|  | 2.2 | El DIP switch permitirá seleccionar diferentes configuraciones o canales del módulo BT. |
| Indicadores | 3.1 | El sistema contará con LEDs que indiquen el estado de conexión del Bluetooth. |
|  | 3.2 | El sistema contará con un buzzer para señalizar eventos del Bluetooth. |
| Memoria | 4.1 | El sistema deberá guardar en memoria flash interna el último valor de PWM utilizado. |
|  | 4.2 | El sistema deberá restaurar automáticamente el último valor guardado al encender. |
| Seguridad | 5.1 | El sistema deberá operar de forma segura sobre cargas de 220 V |
| Aplicación | 6.1 | La aplicación móvil deberá permitir realizar todas las acciones disponibles desde los controles físicos (encendido/apagado de luces y ajuste de velocidad del ventilador). |
|  | 6.2 | El sistema deberá garantizar que el control físico y el control desde la aplicación sean intercambiables: cuando se utilice uno, el otro deberá quedar temporalmente inhabilitado para evitar conflictos de comando. |

<em>Tabla 2.1 — Requisitos iniciales del proyecto (versión original).</em><br><br>

| Grupo | ID | Descripción |
| --- | --- | --- |
| Control | 1.1 | El sistema permitirá encender y apagar las luces mediante un botón físico. |
|  | 1.2 | El sistema permitirá ajustar la velocidad del ventilador mediante un potenciómetro. |
|  | 1.3 | El sistema permitirá ver el estado del ventilador y las luces vía Bluetooth. |
| Bluetooth | 2.1 | El sistema contará con un DIP switch para habilitar o deshabilitar el Bluetooth. |
|  | 2.2 | El DIP switch permitirá seleccionar configuraciones o canales del módulo Bluetooth. |
| Indicadores | 3.1 | El sistema contará con LEDs que indiquen el estado del Bluetooth. |
|  | 3.2 | El sistema contará con un buzzer para señalizar eventos del sistema. |
| Memoria | 4.1 | El sistema deberá guardar en memoria flash el último valor de PWM utilizado. |
|  | 4.2 | El sistema deberá restaurar automáticamente el último valor guardado al encender. |
| Seguridad eléctrica | 5.1 | El sistema deberá operar de forma segura sobre cargas de 220 VAC. |
| Aplicación móvil | 6.1 | La aplicación dará información sobre los estados disponibles, que incluyen la velocidad del ventilador y el estado de luces. |
|  | 6.2 | El sistema deberá evitar conflictos entre el control físico y la comunicación Bluetooth, incluyendo conflictos de timings. |

<em>Tabla 2.2 — Requisitos ajustados en el informe de avances (alcance reducido por tiempos).</em><br><br>

## 2.2 Casos de uso

Esta sección detalla los varios casos de uso previstos para el sistema creado. 

### 2.2.1 Control local de luz

La Tabla 2.3 describe el caso de uso de control local de la luz mediante botones físicos.

| Elemento | Definición |
| --- | --- |
| Disparador | Pulsación de botón ON (`PC12`) o OFF (`PC9`). |
| Precondiciones | Sistema en modo normal, hardware operativo. |
| Flujo básico | Debounce de botón -> evento -> actualización de estado de luz -> actualización de salida TRIAC -> solicitud de guardado en flash -> telemetría BT de cambio. |
| Alternativas | Si falla persistencia y modo estricto activo: transición a `FAULT`. |

<em>Tabla 2.3 — Caso de uso: control local de luz.</em><br><br>

### 2.2.2 Ajuste local de ventilador

La Tabla 2.4 describe el caso de uso de ajuste local del ventilador mediante el potenciómetro.

| Elemento | Definición |
| --- | --- |
| Disparador | Cambio en potenciómetro (`PA0`). |
| Precondiciones | ADC operativo, sistema en modo normal. |
| Flujo básico | Muestreo ADC -> mapeo a porcentaje -> cálculo de `fan_delay_us` -> actualización de temporización de disparo TRIAC. |
| Alternativas | Si potenciómetro fuera de rango calibrado: saturación a límites definidos. |

<em>Tabla 2.4 — Caso de uso: ajuste local de ventilador.</em><br><br>

### 2.2.3 Telemetría Bluetooth hacia app

La Tabla 2.5 detallada a continuación describe el caso de uso de telemetría Bluetooth, utilizada para informar estado hacia la aplicación móvil.

| Elemento | Definición |
| --- | --- |
| Disparador | Cambio de estado de luz o de porcentaje del potenciómetro. |
| Precondiciones | BT habilitado por DIP1, módulo HC-06 conectado. |
| Flujo básico | Firmware arma trama binaria de 2 bytes y transmite por USART1 para que la app informe el estado del sistema. |
| Alternativas | Si BT deshabilitado, no se transmite. |

<em>Tabla 2.5 — Caso de uso: telemetría Bluetooth hacia app.</em><br><br>

### 2.2.4 Recuperación tras falla

La Tabla 2.6 de abajo describe el caso de uso de recuperación ante falla, incluyendo el modo `FAULT` y su salida controlada.

| Elemento | Definición |
| --- | --- |
| Disparador | Error de inicialización o forzado de `FAULT` por DIP4 (`PA4`). |
| Precondiciones | Sistema energizado. |
| Flujo básico | Corte de salidas de potencia, alarma visual/sonora según DIP, reintento de inicialización luego de timeout. |
| Alternativas | Si DIP4 vuelve a 0, salida de `FAULT` y retorno a `NORMAL`. |

<em>Tabla 2.6 — Caso de uso: recuperación tras falla.</em><br><br>

Nota de trazabilidad de alcance:
Los casos de uso y la app se modificaron respecto de los del "README" ([link al documento](https://github.com/Embebidos-Fran-Marcos-Nacho/tdse-tf_1-2/blob/4b6e89fc72c10d777ce4164eac52042739fd6bfa/README.md) en base a los alcances/requisitos alterados en el informe de avances.

## 2.3 Descripción de módulos principales

En las siguientes subsecciones se detallan los múltiples módulos del sistema. 

### 2.3.1 Módulo de control (NUCLEO-F103RB)
- Ejecuta scheduler cooperativo con tick de 1 ms.
- Corre tres tareas: `task_adc`, `task_system`, `task_pwm`.

### 2.3.2 Módulo de potencia (dimmer)
- Dos canales de disparo TRIAC (luz y ventilador).
- Optoacople de disparo y red de protección.

### 2.3.3 Módulo de detección de cruce por cero (ZCD)
- Entrada AC aislada y acondicionada a señal digital.
- Entrada de interrupción por `PC2` (EXTI).

### 2.3.4 Módulo Bluetooth (HC-06)
- Interfaz UART transparente en `PA9/PA10`.
- Configuración AT realizada con interfaz auxiliar USB-UART (Arduino).

### 2.3.5 Aplicación móvil (MIT App Inventor)
- Lectura de trama binaria de 2 bytes.
- Visualización del porcentaje y estado de luz.

---

# Capítulo 3: Diseño e implementación

## 3.1 Arquitectura general

El sistema se organiza en dos dominios:
- Dominio lógico de 3,3 V (STM32 + entradas + comunicaciones).
- Dominio de potencia AC (TRIAC + ZCD + protecciones).

En la Figura 3.1 se presenta el diagrama en bloques general, donde se identifica la separación entre el dominio de baja tensión (3,3 V) y el dominio de potencia en AC, junto con los principales enlaces de interconexión (ZCD, drivers de TRIAC y comunicación Bluetooth).


<em>Figura 3.1 — Diagrama en bloques general.</em><br><br>

## 3.2 Diseño de hardware

Esta sección detalla la solución de Hardware diseñada en sus varias facetas, desde los esquemáticos hasta la verificación por mediciones. 

### 3.2.1 Criterio de interconexión y montaje

Se trabajó con placas y conexiones soldadas para la integración funcional final (sin protoboard ni cables Dupont en el montaje objetivo), en línea con las pautas de entrega.

Se usaron dos placas:
- Placa shield para interfaz y conexión con NUCLEO.
- Placa dimmer para potencia, ZCD y protecciones.

### 3.2.2 Etapa de Conversión de niveles

La Figura 3.2 muestra el conversor de niveles utilizado para adaptar señales entre la NUCLEO-F103RB (3,3 V) y la placa diseñada (5 V), evitando sobrevoltajes en entradas digitales. La imagen fue tomada del esquemático de la placa.

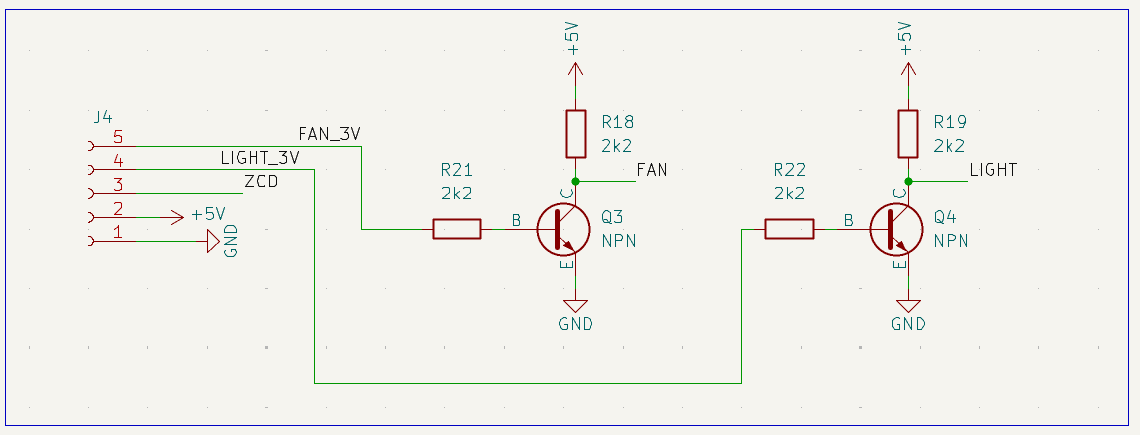
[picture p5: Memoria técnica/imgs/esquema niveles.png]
 
<em>Figura 3.2 — Esquemático del conversor de niveles.</em><br><br>

### 3.2.3 Etapa de TRIACs

La Figura 3.3 presenta el driver de disparo de TRIAC basado en un TRIAC optoacoplado MOC3023, elegido para aislar el dominio lógico y permitir el control de cargas de 220 VAC con disparos sincronizados. El diseño fue tomado de las notas de aplicación que se encuentran en este mismo repositorio en la sección de hardware.  La imagen fue tomada del esquemático de la placa.

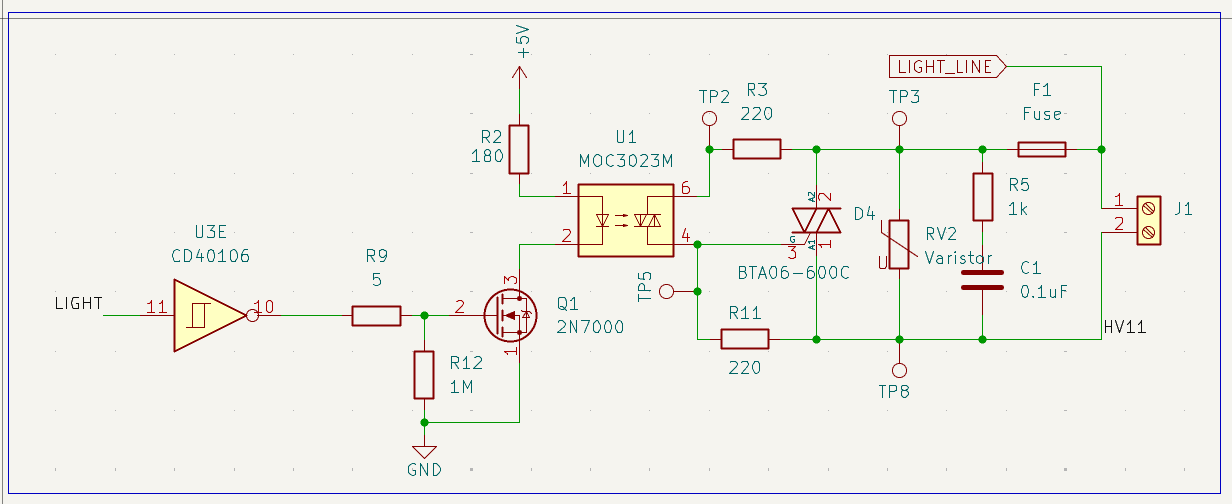
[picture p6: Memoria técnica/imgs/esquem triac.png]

<em>Figura 3.3 — Esquemático de driver de TRIAC.</em><br><br>

### 3.2.4 Etapa ZCD (detección de cruce por cero)

La sección de ZCD fue validada progresivamente en banco antes de integrar potencia. Se observó que:
- La salida detectada requiere compensación temporal aproximada de 500 $\mu s$ para ubicar el cruce real.
- Las simulaciones resultaron consistentes con la tendencia medida.

En la Figura 3.4 se observa el circuito del detector de cruce por cero (ZCD), cuya salida se utiliza como referencia temporal para disparar los TRIACs con un retardo controlado. La foto fue tomada del esquemático de la placa.

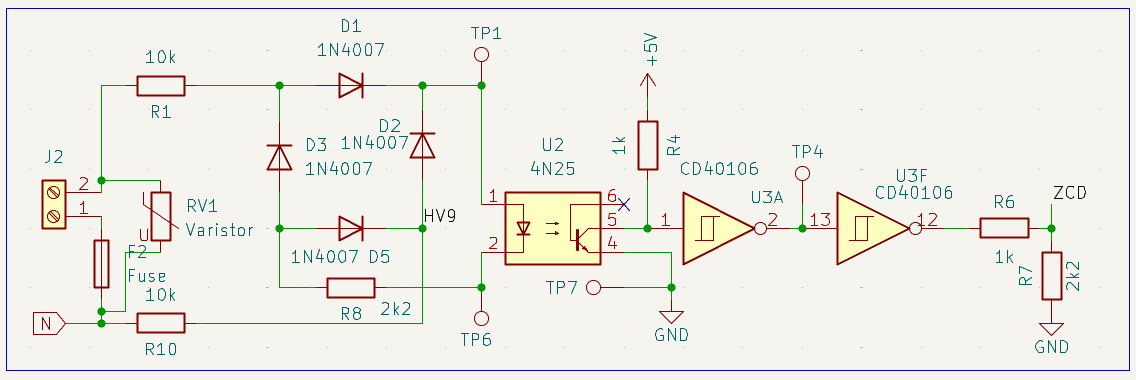
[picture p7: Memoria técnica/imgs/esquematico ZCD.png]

<em>Figura 3.4 — Esquemático del ZCD.</em><br><br>

La Figura 3.5 documenta el banco de pruebas inicial del ZCD, usado para validar el acondicionamiento y la forma de onda antes de integrar la etapa de potencia.

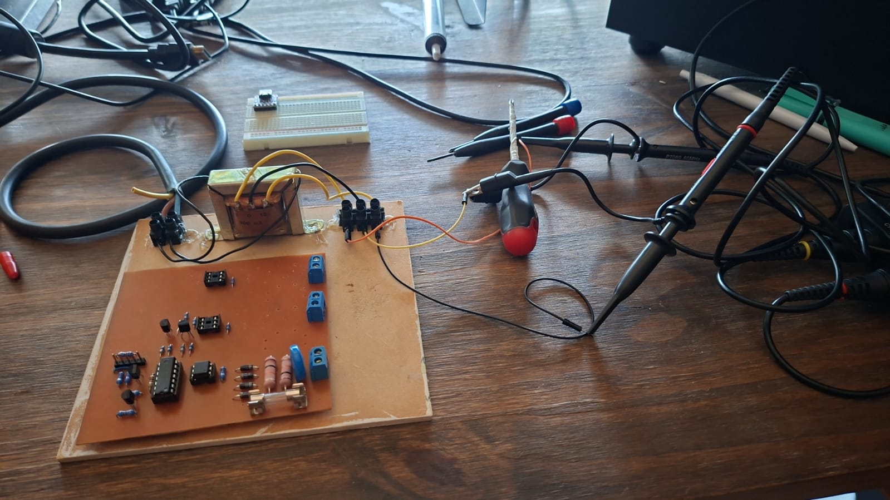
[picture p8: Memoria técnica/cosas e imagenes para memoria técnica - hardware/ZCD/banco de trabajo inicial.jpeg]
 
<em>Figura 3.5 — Banco inicial de pruebas ZCD.</em><br><br>

La Figura 3.6 muestra la señal de salida del ZCD medida con osciloscopio; se verifica que se genera un pulso por cada cruce por cero, resultando en una frecuencia de 100 Hz para red de 50 Hz. También se aprecia el espaciamiento entre pulsos medido con cursores del osciloscopio, que permite estimar la estabilidad temporal del detector.

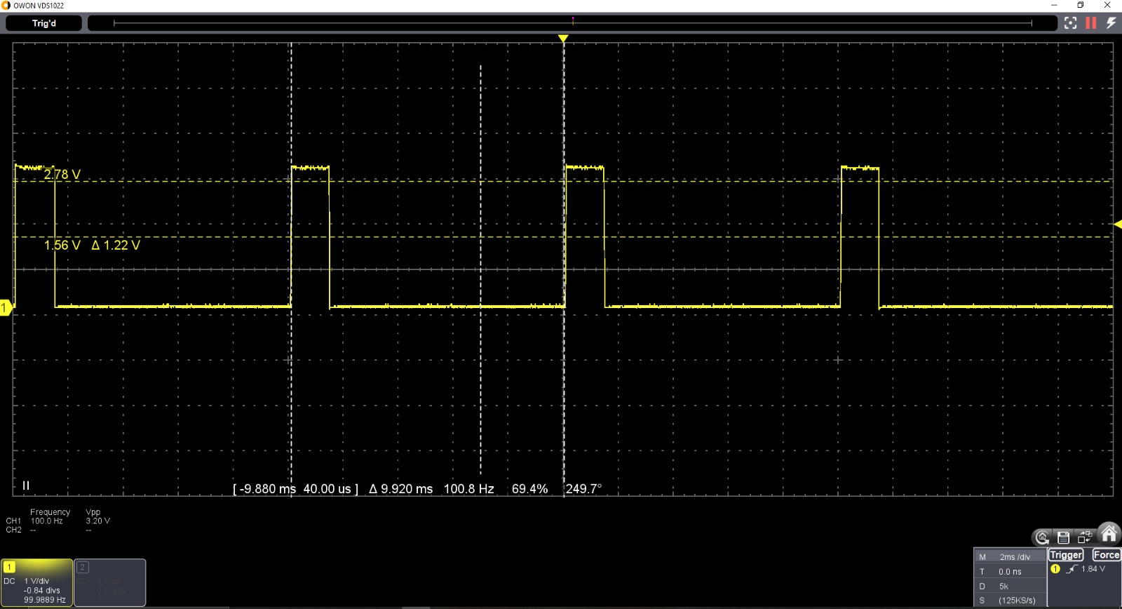
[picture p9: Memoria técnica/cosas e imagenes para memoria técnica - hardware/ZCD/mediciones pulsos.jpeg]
 
<em>Figura 3.6 — Mediciones de pulsos ZCD (osciloscopio).</em><br><br>

En la Figura 3.7 se mide el ancho de pulso del ZCD, que sirve para hacerse una idea de la simetría del disparo entre cruces por cero consecutivos. En este caso se observa buena simetría entre pulsos, 

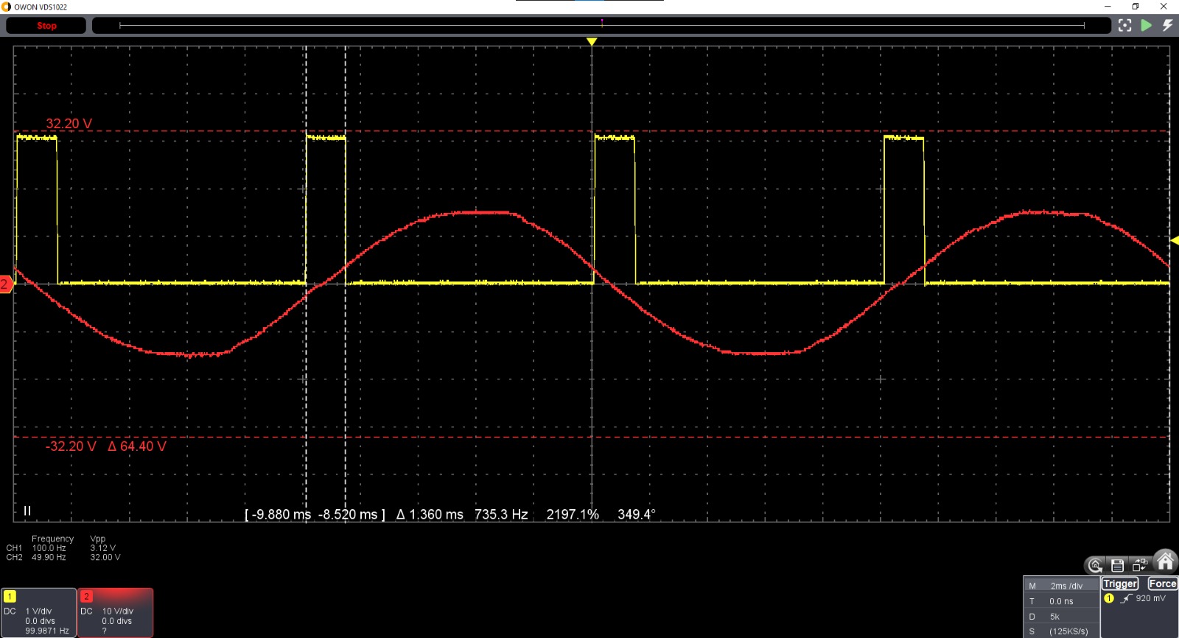
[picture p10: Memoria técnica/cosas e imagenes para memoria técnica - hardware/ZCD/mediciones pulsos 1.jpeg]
 
<em>Figura 3.7 — Medición de ancho de pulso del ZCD.</em><br><br>

La Figura 3.8 evidencia el adelantamiento del pulso respecto del cruce por cero real para la semionda negativa, permitiendo estimar el retardo fijo de compensación.

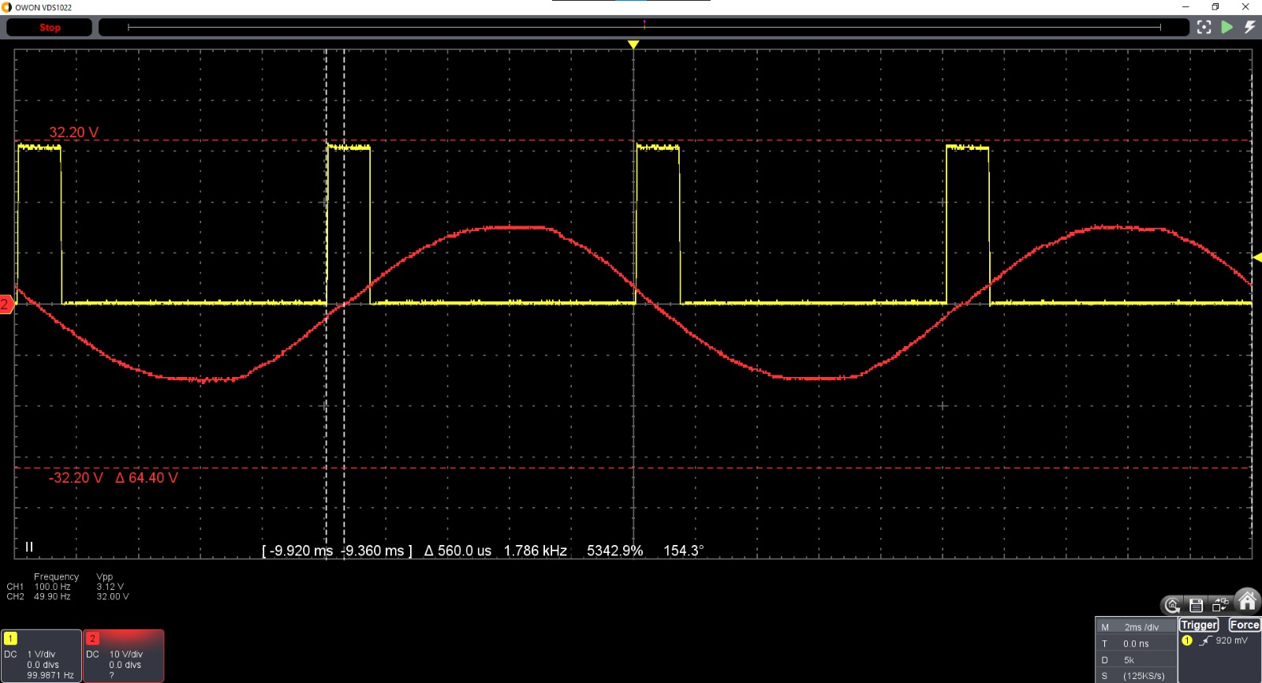
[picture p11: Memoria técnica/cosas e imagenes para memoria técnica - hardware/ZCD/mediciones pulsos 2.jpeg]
 
<em>Figura 3.8 — Disparo previo al cruce real (senoidal negativa).</em><br><br>

La Figura 3.9 muestra el mismo fenómeno que la imagen 3.8 pero para la semionda positiva; ambas mediciones se utilizaron para fijar una compensación temporal conservadora para el disparo de los Triacs. En el código esto se ve reflejado en un tiempo invariante que siempre debe esperar antes de disparar. 

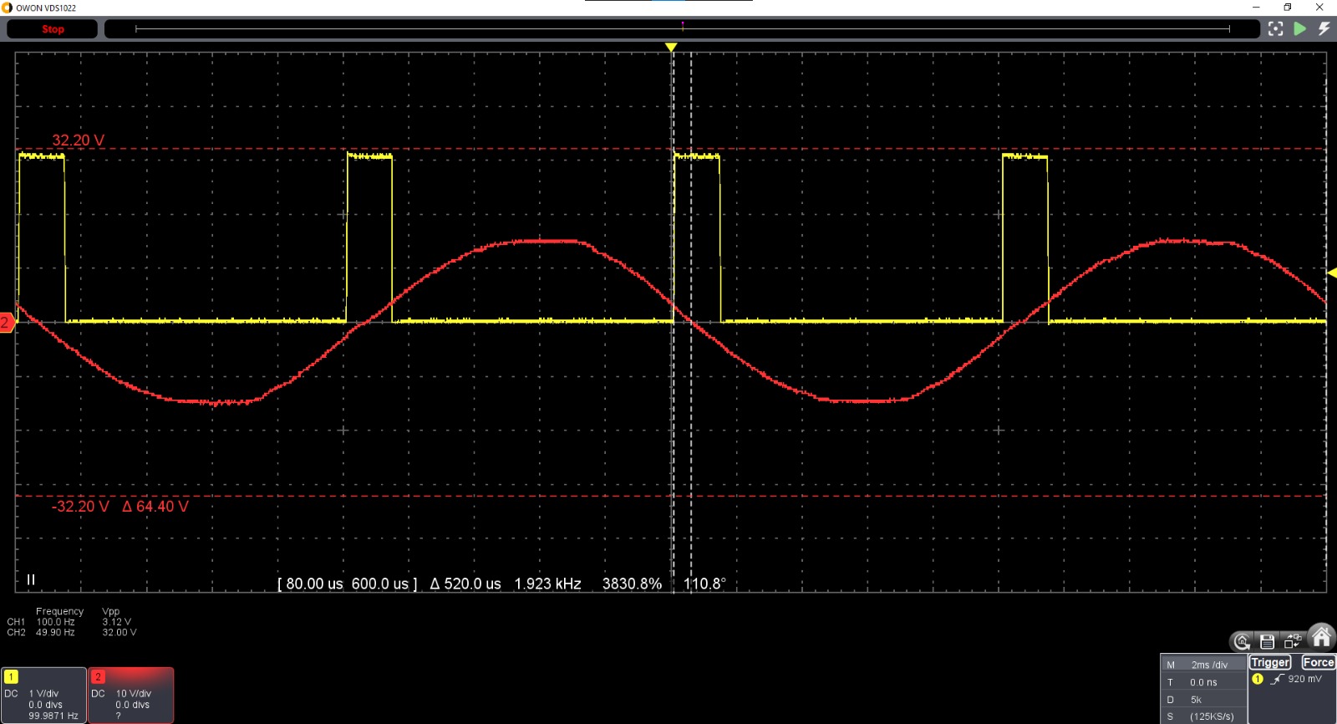
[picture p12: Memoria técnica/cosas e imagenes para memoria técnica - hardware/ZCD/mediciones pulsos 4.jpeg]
 
<em>Figura 3.9 — Disparo previo al cruce real (senoidal positiva).</em><br><br>

### 3.2.5 Etapa de potencia y protecciones

El esquemático principal (Hardware/placa dimmer/dimmer.kicad_sch) muestra los componentes que realizan el manejo de la potencia y su interconexión, además de incluir los elementos de protección básicos, como fusibles, varistores y snubbers RC. Cada uno de los 2 canales de potencia de la placa incluye:

- Un TRIAC de potencia (`BTA06-600C`) elegido por su corriente de disparo y corriente de canal máxima muy superior a 1 A. 
- Optoacoplador de disparo (`MOC3023M`), que aisla galvánicamente la lógica de 5 V de la parte de potencia.
- Elementos de protección (varistor, fusible, red RC/snubber opcional - puede no soldarse).

Ambos canales tienen la capacidad de hacer _dimming_ de su respectiva carga, aunque en este caso solo se usó para una. 

Notas de fabricación:
- Las pruebas se hicieron en 24 VAC. Esto conllevó una ligera y reversible modificación del circuito de ZCD. 

La Figura 3.10 muestra la señal a la salida del 4N25 (emisor común/negador) durante ensayo, confirmando niveles y forma de onda compatibles con el acondicionamiento digital.

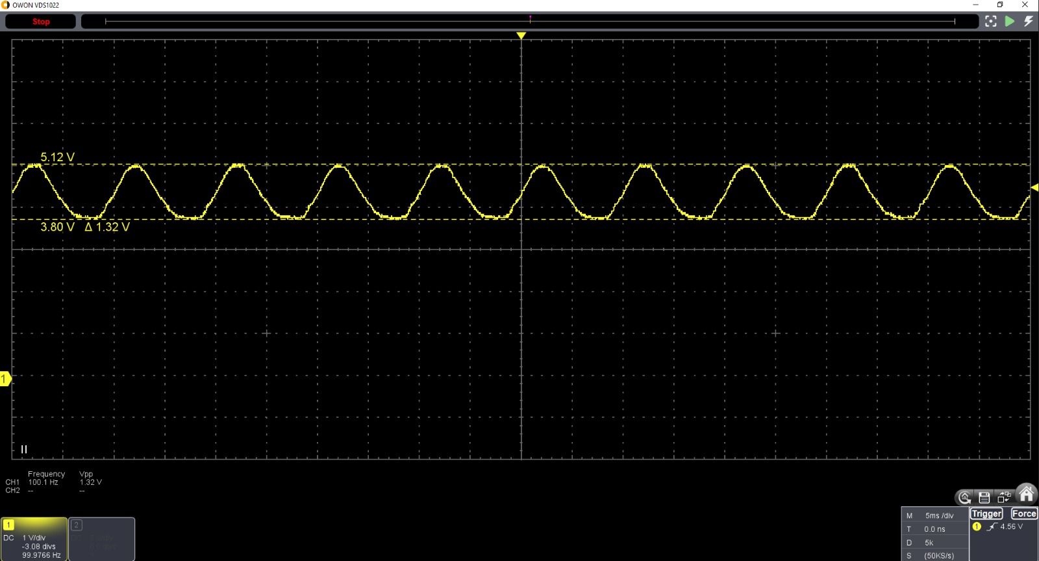
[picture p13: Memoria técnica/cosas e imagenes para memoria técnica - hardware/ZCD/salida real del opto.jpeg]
 
<em>Figura 3.10 — Ensayo de salida de optoacoplador.</em><br><br>

La Figura 3.11 presenta la simulación de la entrada/salida del ZCD y la etapa de opto, utilizada como referencia para contrastar con las mediciones. En este caso las simulaciones son acordes a fenómenos medidos en las figuras 3.7 a 3.9. 

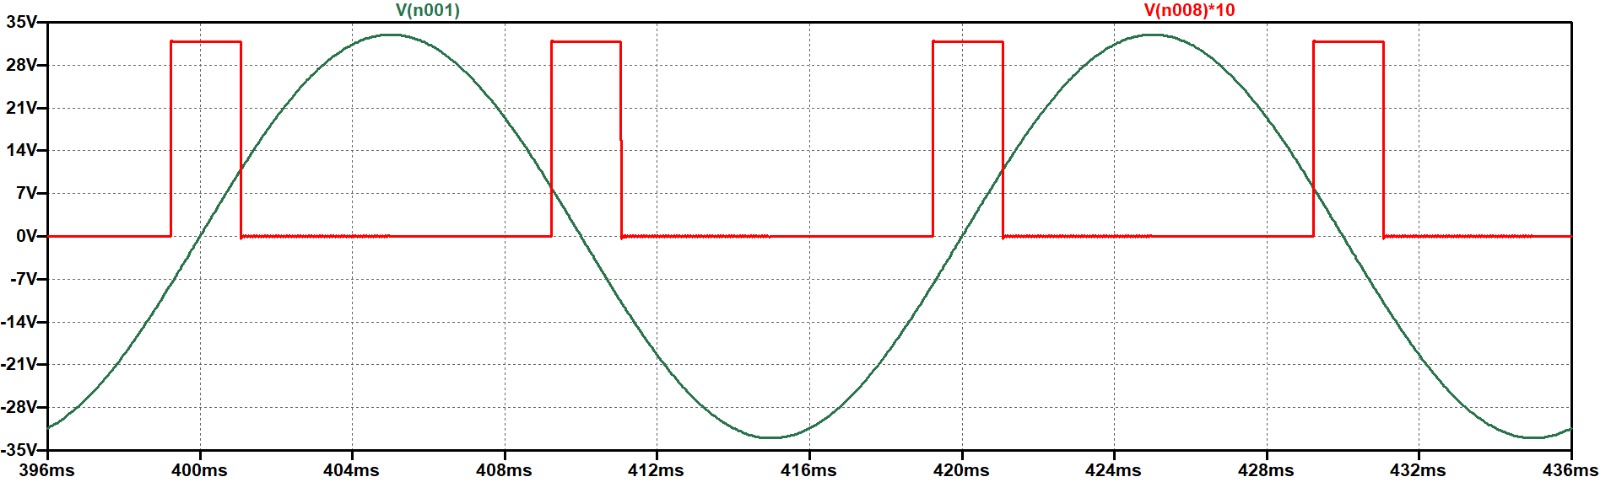
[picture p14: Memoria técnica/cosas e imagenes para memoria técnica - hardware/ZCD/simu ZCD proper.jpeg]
 
<em>Figura 3.11 — Simulación de ZCD y salida de opto.</em><br><br>

En la Figura 3.12 se observa la salida simulada del 4N25. Aunque difiere de la señal real, alcanza los umbrales de funcionamiento por el clico de histéresis de los Schmitt triggers, y el diseño resultó funcional.

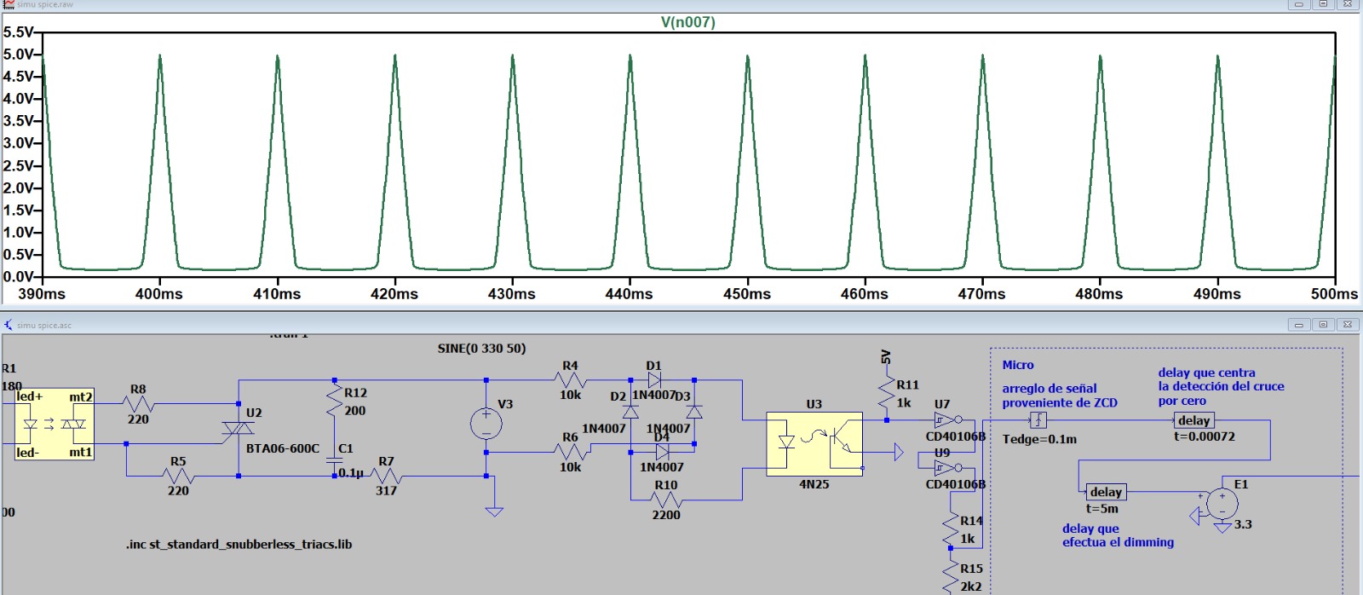
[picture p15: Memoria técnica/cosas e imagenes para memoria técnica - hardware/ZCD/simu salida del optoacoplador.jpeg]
 
<em>Figura 3.12 — Salida simulada del 4N25.</em><br><br>

### 3.2.6 Fabricación de placas

Se documentó el proceso de fabricación con transferencia y ataque químico:
1. Primero se imprimió el diseño sobre un papel PnP Blue.
2. Luego se transfirió por medio de calor. 
3. Se hicieron las correcciones manuales de transferencia.
4. Por último, se realizó un control de continuidad previo a energizar. Esto permite evitar un cortocircuito o arreglar una pista faltante. 

Lecciones aprendidas para la próxima iteración:
- Revisar diámetros de agujeros para componentes de potencia (varistores y componentes grandes): los componentes de _leads_ de mayor diámetro quedaron con _pads_ demasiado chicos. Esto no es un problema en un prototipo, donde el agujero se agranda con un torno de mano, pero es inaceptable en un producto final. 
- Simplificar topología de ZCD: se puede cambiar por un detector de 1 solo diodo, que actúe cada ciclo y no por semiciclo. El segundo disparo se puede resover por software estimando el período de la señal con un filtro de media móvil (o complementario). 
- Evaluar integración de control de dimming en una etapa dedicada: en un futuro la idea es que la solución comercial tenga su propio microcontrolador en la placa, y que solo requiera 220 VAC para funcionar.<br><br>

La Figura 3.13 muestra el papel de transferencia PnP Blue con el diseño impreso, paso previo al copiado del patrón a la placa cobreada.

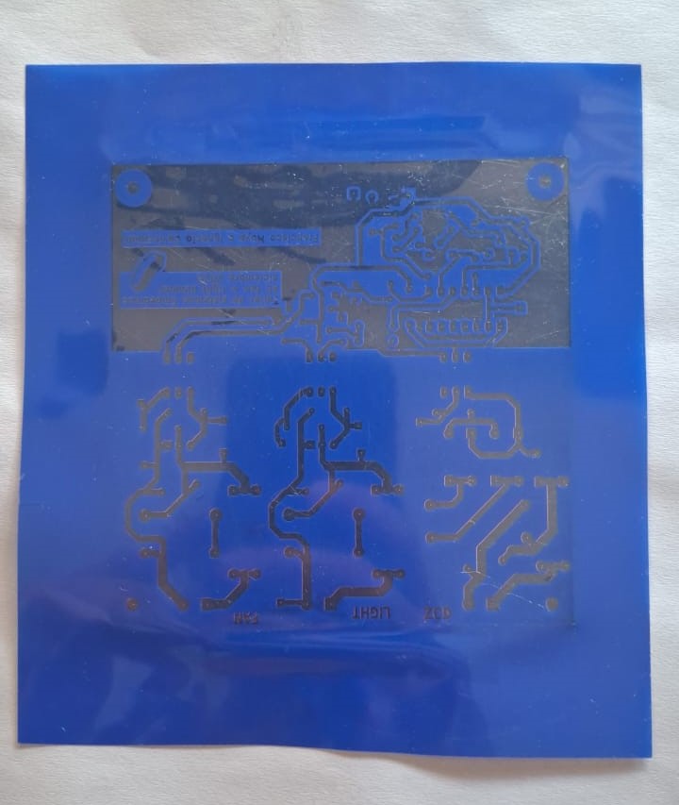
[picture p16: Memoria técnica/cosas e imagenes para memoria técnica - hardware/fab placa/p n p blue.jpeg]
 
<em>Figura 3.13 — Papel de transferencia con diseño impreso.</em><br><br>

La Figura 3.14 registra la primera transferencia sobre cobre, donde se identificaron defectos a corregir antes del ataque químico.

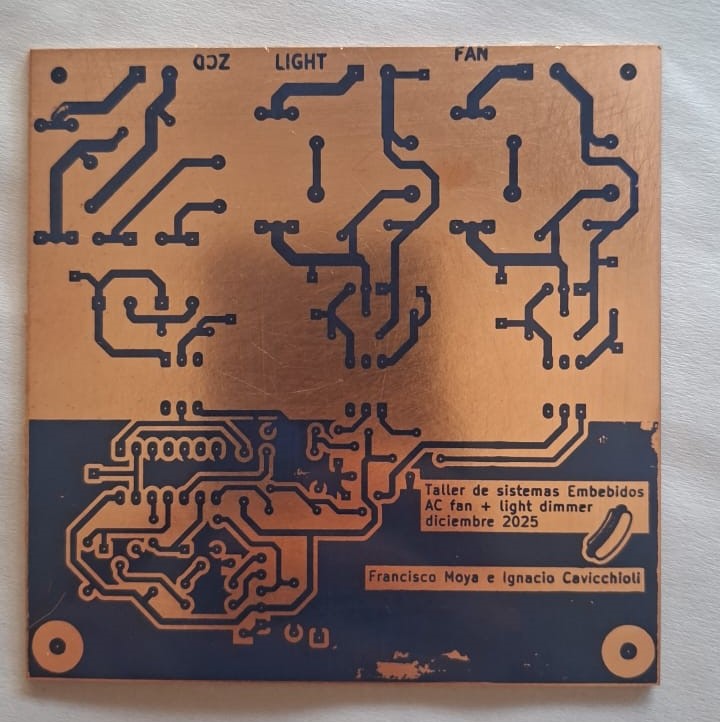
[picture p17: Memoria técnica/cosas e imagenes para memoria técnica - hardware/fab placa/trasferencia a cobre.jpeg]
 
<em>Figura 3.14 — Transferencia previa a correcciones.</em><br><br>

La Figura 3.15 muestra la transferencia luego de correcciones manuales, mejorando continuidad y separación de pistas.

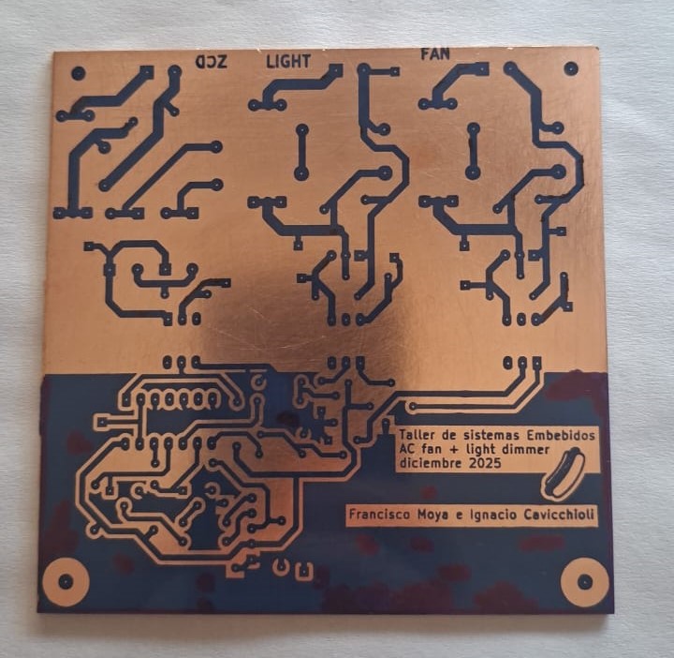
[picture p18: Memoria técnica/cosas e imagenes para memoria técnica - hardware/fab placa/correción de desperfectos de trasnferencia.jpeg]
 
<em>Figura 3.15 — Transferencia corregida.</em><br><br>

La Figura 3.16 presenta la placa fabricada tras el ataque y limpieza, lista para perforado, soldado y pruebas de continuidad.

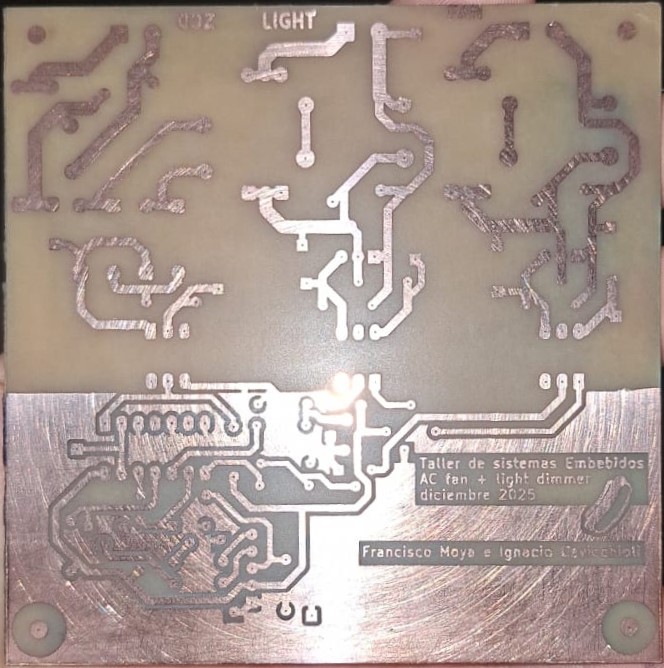
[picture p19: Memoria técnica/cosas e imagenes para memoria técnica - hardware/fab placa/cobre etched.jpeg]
 
<em>Figura 3.16 — Placa fabricada.</em><br><br>

El soldado de la placa se dió en etapas, lo que permitió asegurarse de que cada etapa funcione previo a soldar la siguiente. En nuestro caso todo funcionó a la primera, excepto por una resistencia mal soldada que se corregió fácilmente. La solución final se alimentó con un transformador de 220 VAC a 24 VAC de 48 Watts. 

### 3.2.7 Pinout del sistema (STM32F103RB)

La Tabla 3.1 lista el pinout relevante del sistema para entradas, salidas, DIP switches y comunicaciones. El _shield_ fabricado para este proyecto respeta todas estas conexiones, y además están reflejadas en el el header del main del firmware. 

| Pin | Función |
| --- | --- |
| `PA0` | Potenciómetro (ADC) |
| `PC0` | DIP1: habilitación Bluetooth |
| `PC1` | DIP2: habilitación buzzer |
| `PB0` | DIP3: habilitación LED |
| `PA4` | DIP4: forzado de estado `FAULT` |
| `PC12` | Botón ON de luz |
| `PC9` | Botón OFF de luz |
| `PC2` | ZCD (a circuito de detección de cruces por cero) (EXTI) |
| `PB3` | TRIAC canal ventilador |
| `PB4` | TRIAC canal luz |
| `PB13` | LED |
| `PA8` | Buzzer (`TIM1_CH1`) |
| `PA9/PA10` | USART1 (HC-06) |
| `PA2/PA3` | USART2 (consola ST-Link VCP) |
| `PC8` | Onda de prueba 100 Hz (modo test) |

<em>Tabla 3.1 — Pinout relevante del sistema (STM32F103RB).</em><br><br>

### 3.2.8 Cableado e imágenes del montaje

En esta parte del documento se detalla el montaje y conexionado de las placas. 

La Figura 3.17 muestra el cableado final del prototipo en banco; se destaca el uso de conexiones soldadas y el montaje sin protoboard en la integración objetivo. La excepción es el uso de LEDs como indicadores luminosos, conectados en paralelo a las lámparas. 

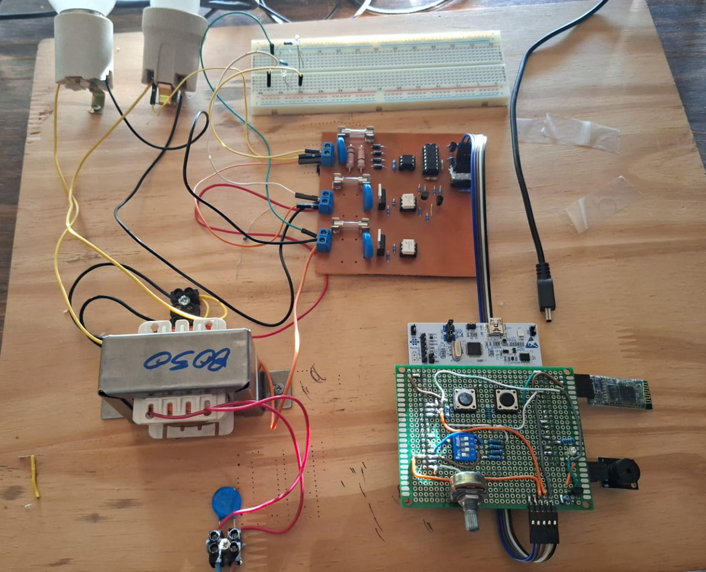
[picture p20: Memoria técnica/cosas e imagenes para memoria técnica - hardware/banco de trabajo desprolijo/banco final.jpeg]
 
<em>Figura 3.17 — Cableado final del prototipo.</em><br><br>

La Figura 3.18 resume el conexionado simplificado entre placas, útil como referencia de integración (señales de control, alimentación y retornos).

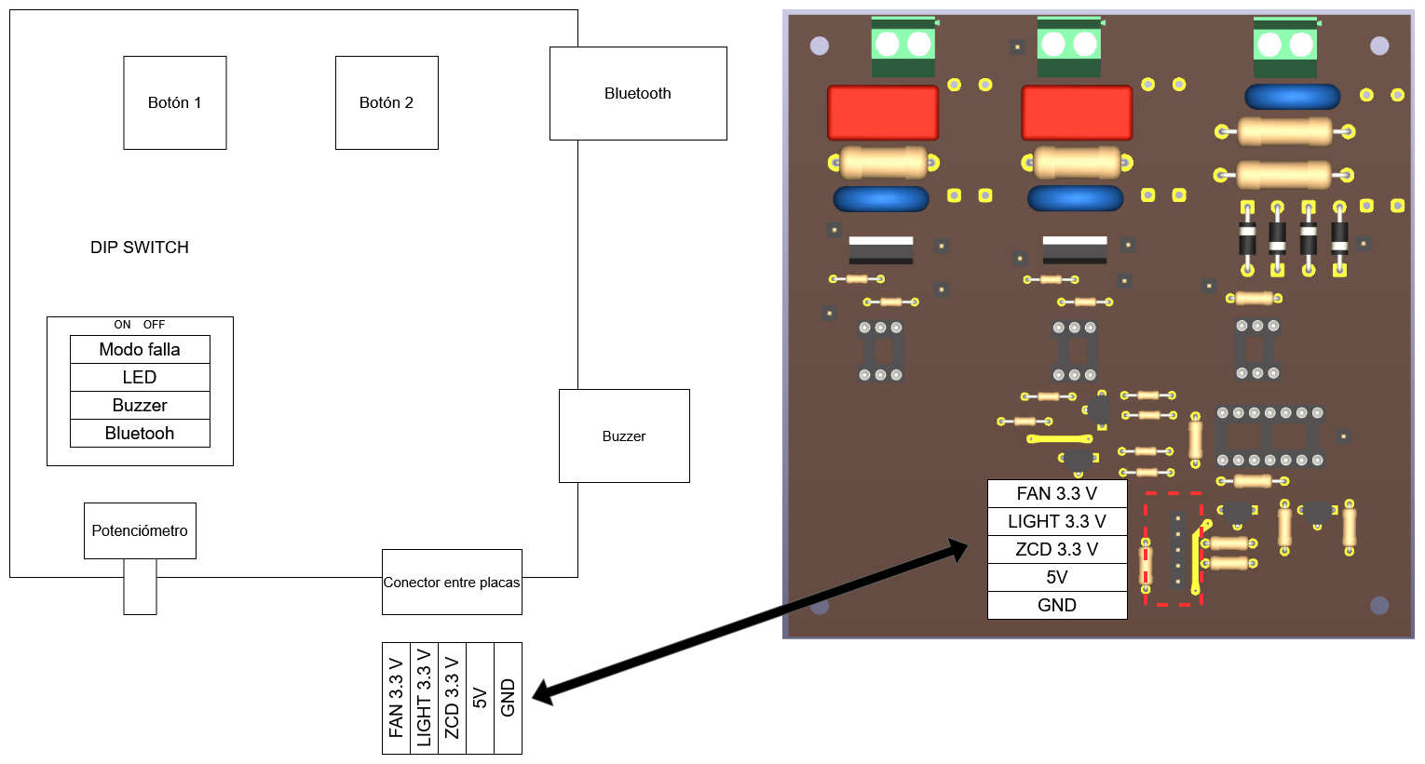
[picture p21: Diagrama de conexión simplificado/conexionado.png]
 
<em>Figura 3.18 — Diagrama de conexión entre placas simplificado.</em><br><br>

En la Figura 3.19 se observa el shield del NUCLEO-F103RB y su conexionado, donde se distinguen entradas (DIP, botones, ADC) y salidas hacia potencia.

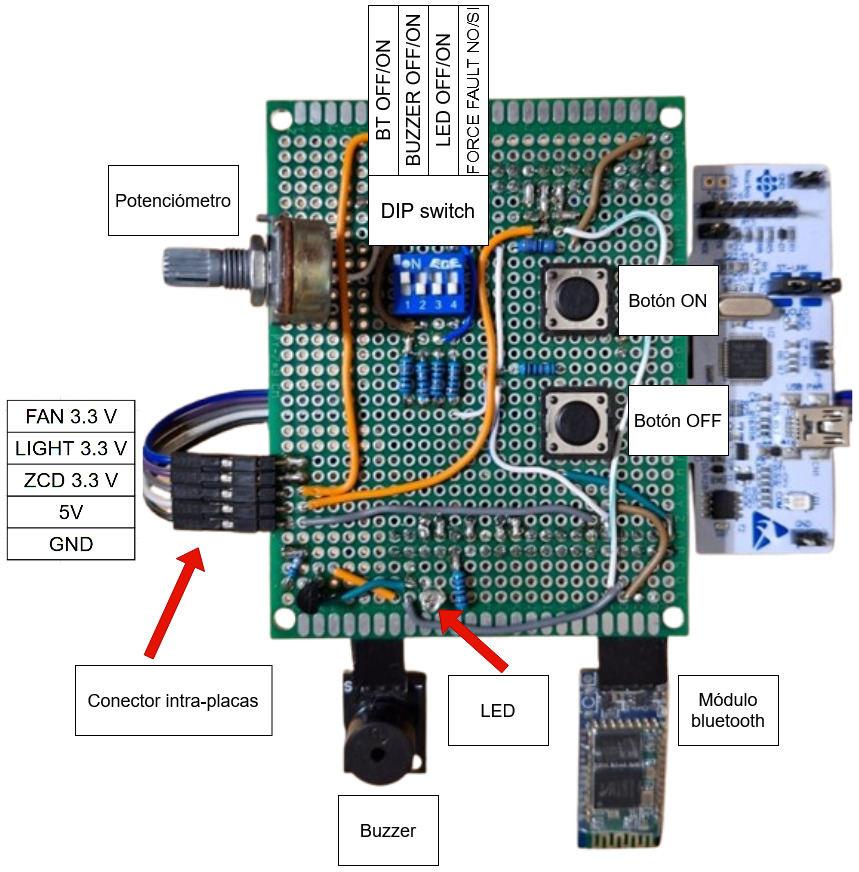
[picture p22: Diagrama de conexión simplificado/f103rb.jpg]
 
<em>Figura 3.19 — Overview de placa shield y conexionado.</em><br><br>

La Figura 3.20 muestra el conexionado de la placa de TRIACs y las cargas, con especial atención a la separación entre el dominio de 220 VAC y el de control.

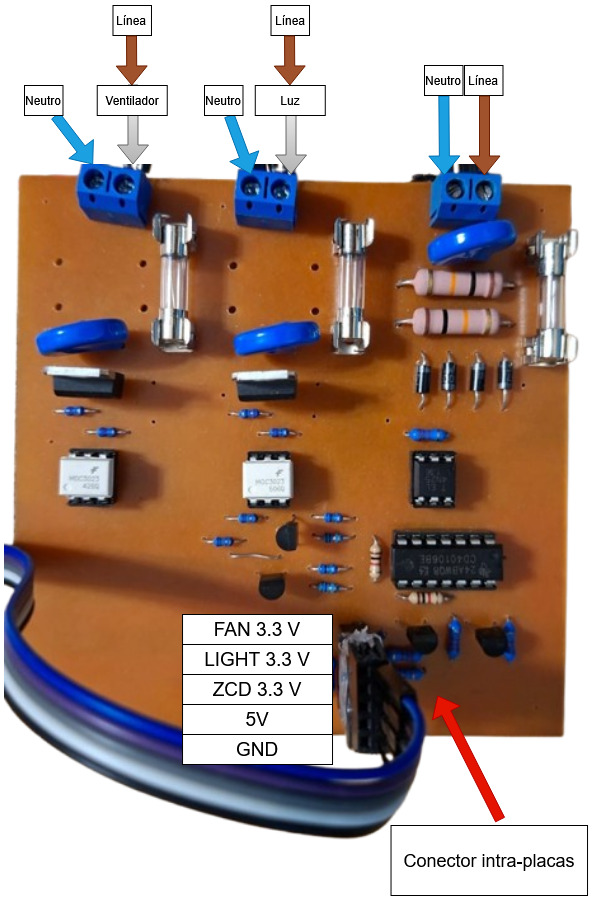
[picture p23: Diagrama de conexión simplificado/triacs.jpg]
 
<em>Figura 3.20 — Conexionado de placa de TRIACs.</em><br><br>

## 3.3 Diseño de firmware

### 3.3.1 Arquitectura de ejecución

El firmware implementa un esquema *bare-metal* con super-loop y tick de 1 ms (`HAL_SYSTICK_Callback`), recorriendo en orden fijo:
1. `task_adc_update`
2. `task_system_update`
3. `task_pwm_update`

Cada tarea se ejecuta en cada tick y su tiempo se mide con contador de ciclos (`DWT->CYCCNT`) para cálculo de WCET.

### 3.3.2 Máquina de estados del sistema

`task_system.c` implementa la máquina de estado global:
- `ST_INIT_READ_FLASH`
- `ST_INIT_READ_DIP`
- `ST_INIT_CHECK_SENSORS`
- `ST_INIT_RESTORE_PWM`
- `ST_INIT_CONFIG_BT`
- `ST_NORMAL`
- `ST_FAULT`

En `FAULT`:
- se corta potencia (`cut_off_voltage=true`).
- se activa patrón de alarma.
- se reintenta inicialización por timeout.

La Figura 3.21 presenta el statechart general del sistema; define el flujo de inicialización, operación normal y transición a falla segura.

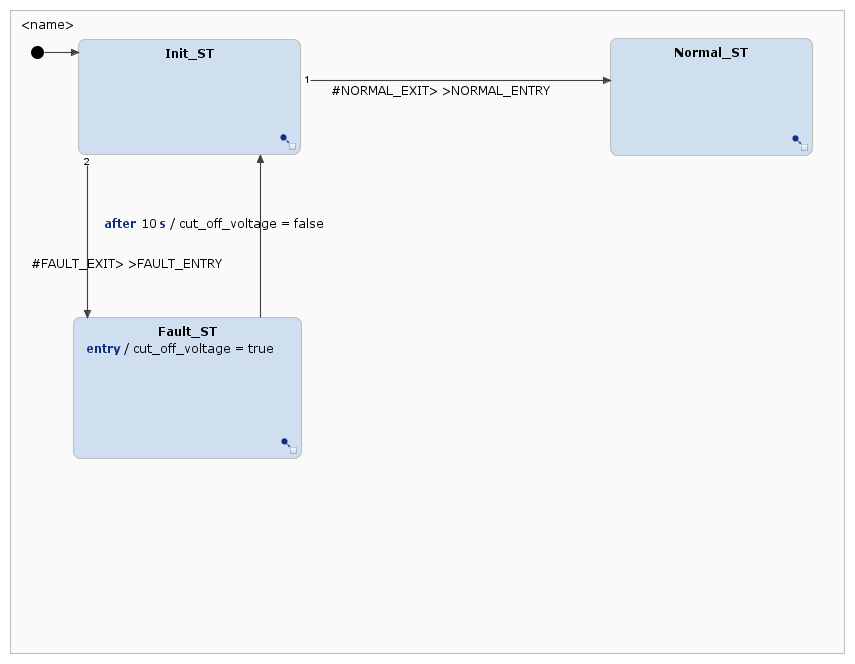
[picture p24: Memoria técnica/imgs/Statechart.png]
 

<em>Figura 3.21 — Statechart general (Harel/Itemis).</em><br><br>

En la Figura 3.22 se detallan los subestados de inicialización, donde se leen DIP, se verifican condiciones y se restaura configuración persistida.
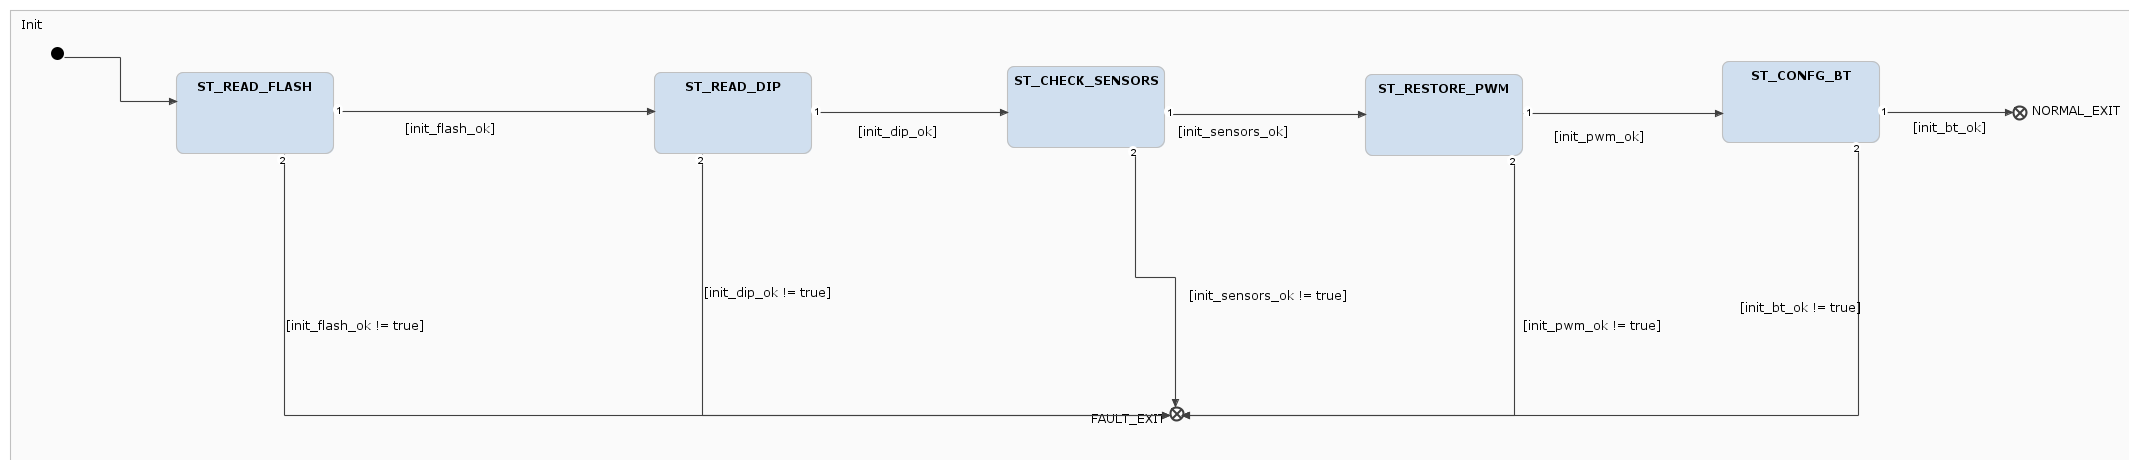
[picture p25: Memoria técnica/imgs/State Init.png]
> 
<em>Figura 3.22 — Subestados de inicialización.</em><br><br>

La Figura 3.23 muestra el estado normal, responsable de atender eventos de usuario, control de TRIAC y telemetría BT.
> 
<em>Figura 3.23 — Estado normal.</em><br><br>

La Figura 3.24 describe el estado de falla, en el que se corta potencia y se señaliza la condición mientras se gestiona recuperación.
> 
<em>Figura 3.24 — Estado de falla.</em><br><br>

La Figura 3.25 muestra la FSM de debounce utilizada para los botones, evitando rebotes y generando eventos limpios hacia la lógica del sistema.
> 
<em>Figura 3.25 — FSM de debounce de botón.</em><br><br>

### 3.3.3 Entradas y acondicionamiento lógico

- Debounce por máquina de estados para botones ON/OFF.
- Muestreo ADC periódico (`ADC_PERIOD_MS = 50 ms`).
- Escalado del potenciómetro usando límites de calibración manual:
  - mínimo: 696 cuentas.
  - máximo: 3194 cuentas.
- Filtro por deadband para evento de potenciómetro (`APP_ADC_PERCENT_EVENT_DEADBAND = 2%`) para evitar oscilaciones por ruido (ej. 99% <-> 100%).
Esto último asegura una excursión correcta que considera las caidas de tensión en la placa de control. 

### 3.3.4 Control de TRIAC y sincronización AC

`task_pwm.c` usa `TIM2` para programar ventanas ON/OFF por semiciclo:
- retardo fijo de referencia: `APP_TRIAC_FIXED_WAIT_US = 700 $\mu s$`.
- ancho de pulso de gate: `APP_TRIAC_PULSE_US = 1000 $\mu s$`.
- retardo variable del ventilador por porcentaje (`fan_delay_us`).

El evento de cruce por cero llega por EXTI en `PC2`.

### 3.3.5 Persistencia en flash

Se utiliza una página dedicada de flash interna (`0x0801FC00`) para:
- palabra mágica.
- versión de layout.
- estado de luz.
- calibración ADC min/max.

Si el guardado crítico falla (según configuración estricta), la FSM puede entrar en `FAULT`.

### 3.3.6 Bluetooth HC-06

Configuración:
- nombre: `Dimmer_BL`.
- PIN: `1111`.
- comandos AT enviados sin CR/LF y con retardos adecuados (desde un Arduino, previo a armado).

Funcionamiento en firmware:
- UART por `USART1`.
- telemetría binaria (sin JSON).
- 2 bytes por frame:
  - byte 0: `adc_percent` (0..100).
  - byte 1: `light_enabled` (0/1).
- Envío periódico por tiempo (no por cambio), configurable con `APP_BT_TELEMETRY_PERIOD_MS` (actualmente `50 ms`). Esto ayudó mucho a mejorar los WCET debido a que el uso de la consola parece tomar mucho tiempo.

### 3.3.7 Aplicación móvil

La app fue desarrollada en MIT App Inventor. Se documentan interfaz y bloques de procesamiento de bytes.

La Figura 3.26 muestra la pantalla principal de la app, donde se visualiza la velocidad del ventilador en un formato de procentaje según el ADC, y el estado de luz recibido por telemetría.

> 
<em>Figura 3.26 — Pantalla principal app.</em><br><br>

La Figura 3.27 presenta los bloques de inicialización de la app, incluyendo configuración de Bluetooth y preparación de variables.

> 
<em>Figura 3.27 — Bloques MIT App Inventor (parte 1).</em><br><br>

La Figura 3.28 muestra la lógica de decodificación/actualización de los 2 bytes de telemetría y el refresco de UI.

> 
<em>Figura 3.28 — Bloques MIT App Inventor (parte 2).</em><br><br>

La Figura 3.29 detalla la lógica de selección del dispositivo Bluetooth, utilizada para vincularse al HC-06.

> 
<em>Figura 3.29 — Bloques MIT App Inventor (parte 3).</em><br><br>

---

# Capítulo 4: Ensayos y resultados

Esta sección presenta todos los ensayos requeridos como parte del proyecto, incluyendo el uso de CPU, WCET, etc. 

## 4.1 Pruebas funcionales de hardware

La Tabla 4.1 resume los ensayos funcionales de hardware realizados y su estado de validación.

| Ensayo | Resultado | Estado |
| --- | --- | :---: |
| Integridad de placas (continuidad) | Validación previa a energización | ✅ |
| ZCD en banco | Detección de eventos y correlación con simulación | ✅ |
| Integración con 24 VAC | Prueba inicial de etapa integrada | ✅ |
| Observar integridad de dimming en 24 VAC (osciloscopio) | Se verificó por medio de osciloscopio | ✅ |

<em>Tabla 4.1 — Ensayos funcionales de hardware.</em><br><br>

## 4.2 Pruebas funcionales de firmware

La Tabla 4.2 resume los ensayos funcionales de firmware realizados y su estado de validación.

| Ensayo | Resultado | Estado |
| --- | --- | :---: |
| Debounce botones ON/OFF | Eventos limpios sobre FSM | ✅ |
| Muestreo ADC + mapeo | Escalado operativo 0..100% | ✅ |
| FSM de sistema (`INIT/NORMAL/FAULT`) | Transiciones válidas en logs | ✅ |
| Persistencia flash | Lectura/escritura de estado y calibración | ✅ |
| Telemetría BT (2 bytes) | Trama enviada en forma periódica (`APP_BT_TELEMETRY_PERIOD_MS`) | ✅ |

<em>Tabla 4.2 — Ensayos funcionales de firmware.</em><br><br>

## 4.3 Pruebas de integración

Se validó la interacción completa:
- entradas físicas.
- control de potencia.
- telemetría hacia app.

**Video de integración en funcionamiento**  

[Link al video
](https://youtu.be/iv2bGrqrMtU)<br>

## 4.4 Medición y análisis de consumo

Metodología aplicada:
- Medición de consumo total en la entrada de `5 V` del sistema (NUCLEO + shield).
- Alimentación desde fuente externa conectada a pines `5 V` y `GND`.
- Medición de corriente con multímetro en serie sobre la línea de `5 V`.
- Medición de tensión en bornes de entrada para estimar potencia (`P = V * I`).

Procedimiento realizado:
1. Desconectar USB/ST-Link para evitar doble alimentación.
2. Conectar fuente externa a `5 V` y `GND`.
3. Ajustar la fuente para garantizar `5 V` en el pin `5 V` de la placa (compensando las caídas de tensión en los cables).
4. Intercalar amperímetro en serie en la línea de `5 V`.
5. Medir tensión de entrada en paralelo sobre `5 V-GND`.
6. Registrar datos en los modos:
   - normal sin módulo Bluetooth conectado.
   - normal con módulo Bluetooth conectado pero desactivado.
   - normal con Bluetooth activo enviando datos.
   - fault con alarma activa (buzzer + LED).
7. Debido a que el consumo oscila rápidamente en el tiempo, se tomó como referencia el valor pico observado en cada modo.

Alcance de la medición:
- Esta medición representa el consumo total a `5 V` del conjunto montado.
- El riel de `3,3 V` queda incluido indirectamente, ya que se genera desde `5 V` mediante el regulador de la placa. Además, registrar el consumo de 3,3 V solo no tiene sentido para un sistema que requiere de 5 V para funcionar normalmente. 

La Tabla 4.3 resume los valores pico de corriente y potencia medidos en distintos modos de operación del sistema.

| Modo | $I_{pico}$ @ 5 V [mA] | $P_{pico}$ @ 5 V [W] | Observaciones |
| --- | ---: | ---: | --- |
| Normal sin módulo BT (desconectado) | 64 | 0.320 | Escenario de menor consumo; representa una forma válida de uso sin telemetría Bluetooth. |
| Normal con módulo BT conectado y desactivado | 104 | 0.520 | Aumento de consumo por presencia/alimentación del módulo Bluetooth. |
| Normal con BT activo enviando datos | 107 | 0.535 | Incremento leve respecto al modo BT desactivado. |
| Fault (buzzer + LED activos) | 145 | 0.725 | Peor caso medido en operación. |

<em>Tabla 4.3 — Consumo total medido a 5 V (valores pico).</em><br><br>

Análisis:
- La potencia se calculó como `P = V * I`, usando `V = 5 V` y corriente pico medida en cada modo.
- El peor caso medido fue `145 mA` a `5 V`, equivalente a `0.725 W`.
- El sistema se mantiene por debajo de `1 W`, por lo que puede alimentarse sin inconvenientes con fuentes comerciales 220VAC->5 V de baja potencia (o incluso las integradas para PCBs).
- La diferencia entre el HC-06 desactivado y transmitiendo (`104 mA` -> `107 mA`) es baja, consistente con carga adicional moderada por comunicación. Suponemos que el consumo no es menor al no transmitir porque está haciendo broadcast de su existencia constantemente. 

## 4.5 Console and Build Analyzer

La Figura 4.1 muestra el reporte de uso de memoria del build; se observa un uso bajo de RAM y FLASH (≈10,31% y ≈16,11%), dejando margen para futuras extensiones.

> 
<em>Figura 4.1 — Console and Build Analyzer.</em><br><br>

## 4.6 Medición y análisis de WCET por tarea

El firmware instrumenta WCET por tarea en `app.c` usando `DWT->CYCCNT` y un modo de perfilado limpio (`[PROF]`) activado temporalmente durante ensayo:
- `WCETw` = WCET en ventana (steady-state, últimos 1000 ciclos)
- `WCETb` = WCET acumulado desde boot
- `Cavg` = tiempo promedio de ejecución

Metodología realizada:
1. Flashear build `Software STM32/main` en NUCLEO-F103RB.
2. Abrir consola serial (USART2, 115200 baud).
3. Ejecutar con trazas de test desactivadas (`APP_TEST_MODE = 0`) y perfil limpio activo durante la medición.
4. Dejar correr el sistema en estado idle (sin pulsaciones ni cambios ADC).
5. Registrar múltiples ventanas `[PROF]` (n~1010 por ventana).

Es decir, se usó el mismo programa pero con un modo de estimación del WCET. 

Formato de log utilizado y significado de parámetros:
- `n`: cantidad de ciclos de scheduler medidos en la ventana.
- `ov`: cantidad de overruns (ciclos cuyo runtime total supera 1 ms).
- `qmax`: máximo backlog observado en la cola de ticks (`g_app_tick_cnt`) durante la ventana.
- `Cavg={adc,sys,pwm}`: tiempo promedio por tarea en la ventana ($\mu s$).
- `WCETw={adc,sys,pwm}`: peor tiempo por tarea dentro de la ventana ($\mu s$).
- `CPU={avg,peak}`: utilización total promedio y pico del scheduler en la ventana (%).
- `U={avg,wcet}`: factor de uso promedio y por peor caso reportado para la ventana.

Criterio de consolidación de resultados:
- Se tomaron 15 líneas consecutivas `[PROF]`.
- Para `Cavg típico` se reportó el rango estable observado.
- Para `WCETw máx observado` se tomó el máximo absoluto entre las 15 ventanas.
- Para `U` se reportó rango observado por ventana y cota conservadora adicional.

Es muy importante destacar que el uso de la consola eleva masivamente los WCET, por lo que se minimizó en las evaluaciones. 

**Resultados medidos (estado idle/estable, 15 ventanas):**

La Tabla 4.4 resume los resultados consolidados de tiempo de ejecución por tarea (promedio y peor caso en ventana).

| Tarea | Período asumido [$\mu s$] | Cavg típico [$\mu s$] | WCETw máx observado [$\mu s$] |
| --- | ---: | ---: | ---: |
| `task_adc_update` | 1000 | 64..66 | 268 |
| `task_system_update` | 1000 | 26 | 125 |
| `task_pwm_update` | 1000 | 46..48 | 292 |

<em>Tabla 4.4 — Resultados de WCET por tarea (ventanas en idle/estable).</em><br><br>

**Observaciones:**
- No se observaron overruns (`ov=0`) en ninguna ventana.
- `qmax=10` se mantuvo estable en todas las ventanas registradas.
- Uso de CPU: `CPU avg` entre `13,6%` y `14,0%`; `CPU peak` entre `35,6%` y `38,0%`.

## 4.7 Cálculo del factor de uso de CPU (U)

Para evaluar la carga temporal del sistema se calculó el factor de utilización de CPU utilizando la expresión clásica de sistemas en tiempo real:

$$U = \sum_{i=1}^{n} \frac{C_i}{T_i}$$

donde (C_i) representa el WCET de la tarea (i), medido a partir de ventanas de ejecución en régimen estacionario, y (T_i) su período de activación.

La Tabla 4.5 resume los valores utilizados para el cálculo:

| Tarea | (C_i) (WCET) [µs] | (T_i) [µs] | (C_i/T_i) |
| --- | ---: | ---: | ---: |
| `task_adc_update` | 268 | 1000 | 0.268 |
| `task_system_update` | 125 | 1000 | 0.125 |
| `task_pwm_update` | 292 | 1000 | 0.292 |
| **Total (U) (WCET-based, conservador)** | – | – | **0,685** |

<em>Tabla 4.5 — Parámetros utilizados para el cálculo de U (cota conservadora).</em><br><br>

El valor total obtenido, ($U = 0.685$), corresponde a una cota conservadora, ya que se construyó combinando los máximos tiempos de ejecución observados para cada tarea en ventanas temporales distintas y no a partir de una ocurrencia simultánea real de dichos máximos.

En contraste, las mediciones experimentales mostraron valores de utilización sensiblemente menores: la utilización basada en ventanas ($U_{wcet}$) se mantuvo entre $46,5$ % y $66,1$ %, mientras que la utilización promedio ($U_{avg}$) se ubicó en torno al 14 % en régimen permanente. En el caso particular del STM32F103RB, estos resultados indican un comportamiento temporal estable, con un margen de CPU suficiente para absorber variaciones transitorias de ejecución sin comprometer el cumplimiento de los períodos de las tareas, validando así la factibilidad temporal del diseño.

## 4.8 Gestión de bajo consumo y justificación

En esta iteración del TP no se implementó una estrategia dedicada de bajo consumo a nivel firmware (por ejemplo, entrada explícita a modos `Sleep/Stop` ni escalado dinámico de frecuencia), ya que el objetivo principal fue priorizar robustez funcional, seguridad eléctrica y cierre de integración.

No obstante, se evaluó el impacto energético real del sistema y los resultados muestran que el consumo del conjunto está dominado principalmente por el hardware periférico y la plataforma de prototipado:
- El salto de consumo al conectar el módulo Bluetooth es significativo (`64 mA` -> `104 mA`), aun sin transmitir.
- La diferencia entre Bluetooth desactivado y transmitiendo es menor (`104 mA` -> `107 mA`).
- En falla, el mayor consumo se explica por actuadores/indicadores (`buzzer + LED`), no por carga computacional del CPU.

Esto es consistente con el factor de uso medido (`Uavg` alrededor de `14%` y cota conservadora `Uwcet = 0,685`): la carga temporal del microcontrolador no aparece como cuello de botella energético principal en el prototipo actual.

En una versión orientada a producto (placa dedicada, sin sobrecarga de NUCLEO y periféricos de laboratorio), sí corresponde aplicar optimización sistemática de consumo:

- Reducir frecuencia de reloj del MCU al mínimo compatible con temporización y control de TRIAC.
- Incorporar política de idle de bajo consumo (entrada a `Sleep` entre eventos periódicos/interrupts).
- Migrar de HC-06 (Bluetooth clásico) a BLE para telemetría de bajo consumo.
- Revisar arquitectura de hardware auxiliar (drivers, conversores, etapas de acondicionamiento y protecciones) para eliminar consumo no esencial.

Conclusión: para el alcance académico de esta entrega, el consumo observado está mayormente determinado por decisiones de hardware e instrumentación de prototipo. La optimización fina de bajo consumo queda planificada como mejora de próxima revisión de diseño.

## 4.9 Cumplimiento de requisitos

La Tabla 4.6 resume el cumplimiento final de los requisitos (versión ajustada del informe de avances), discriminando el aporte de hardware y firmware.

| ID | Requisito (versión final) | Hardware | Software | Estado final |
| --- | --- | :---: | :---: | :---: |
| 1.1 | El sistema permitirá encender y apagar las luces mediante un botón físico. | 🟢 | 🟢 | ✅ |
| 1.2 | El sistema permitirá ajustar la velocidad del ventilador mediante un potenciómetro. | 🟢 | 🟢 | ✅ |
| 1.3 | El sistema permitirá ver el estado del ventilador y las luces vía Bluetooth. | 🟢 | 🟢 | ✅ |
| 2.1 | El sistema contará con un DIP switch para habilitar o deshabilitar el Bluetooth. | 🟢 | 🟢 | ✅ |
| 2.2 | El DIP switch permitirá seleccionar configuraciones o canales del módulo Bluetooth. | 🟢 | 🔴 | 🔴 |
| 3.1 | El sistema contará con LEDs que indiquen el estado del Bluetooth. | 🟢 | 🟢 | ✅ |
| 3.2 | El sistema contará con un buzzer para señalizar eventos del sistema. | 🟢 | 🟢 | ✅ |
| 4.1 | El sistema deberá guardar en memoria flash el último valor de PWM utilizado. | 🟢 | 🟢 | ✅ |
| 4.2 | El sistema deberá restaurar automáticamente el último valor guardado al encender. | 🟢 | 🟢 | ✅ |
| 5.1 | El sistema deberá operar de forma segura sobre cargas de 220 VAC. | 🟡 | N/A | 🟡 |
| 6.1 | La aplicación dará información sobre los estados disponibles, que incluyen la velocidad del ventilador y el estado de luces. | N/A | 🟢 | ✅ |
| 6.2 | El sistema deberá evitar conflictos entre el control físico y la comunicación Bluetooth, incluyendo conflictos de timings. | N/A | 🟢 | ✅ |

<em>Tabla 4.6 — Cumplimiento final de requisitos (versión final).</em><br><br>

Leyenda:
- 🟢 implementado
- 🟡 parcialmente cumplido / con alcance acotado en prototipo
- 🔴 no implementado / descartado
- ✅ cumplido

Los requisitos cumplidos no requieren de mayor explicación, por lo que nos centramos en los que no se llegaron a cumplir:
- Requisito 2.2 (canales/configuración Bluetooth): En la implementación final no se desarrolló la selección de canales/configuraciones por DIP para Bluetooth. Se descartó por no ser necesario para el funcionamiento objetivo del sistema (telemetría de estado).

- Requisito 5.1 (220 VAC): La validación final sobre red de 220 VAC queda planificada para la etapa posterior a la aprobación académica del trabajo. Esta decisión se toma para reducir el riesgo de daño de la placa durante la instancia de entrega y evaluación.

## 4.10 Comparación con sistemas similares

La Tabla 4.7 presenta una comparación sintética de esta solución frente a alternativas típicas (control básico IR/RF y soluciones comerciales Wi‑Fi).

| Característica | Control IR/RF básico | Solución Wi-Fi comercial | Este proyecto |
| --- | :---: | :---: | :---: |
| Interfaz local de pared | No | Generalmente no | Sí |
| App móvil | No | Sí | Sí (telemetría) |
| Personalización firmware | No | No | Sí |
| Persistencia local | Variable | Sí | Sí |
| Costo de prototipo académico | N/A | Alto | Medio |

<em>Tabla 4.7 — Comparación con sistemas similares.</em><br><br>

## 4.11 Documentación del desarrollo realizado

Material técnico disponible en repositorio:
- Código fuente STM32 (`Software STM32/main`).
- Esquemáticos y PCB (`Hardware/placa dimmer`, `Hardware/placa shield`).
- Diagramas de estado (`Diagrama de Harel`).
- App móvil (`app celular`).
- Memoria técnica y contenido gráfico (`Memoria técnica`).

---

# Capítulo 5: Conclusiones

## 5.1 Resultados obtenidos

Se obtuvo un prototipo funcional que integra:
- Control local de luz y ventilador.
- Sincronización con cruce por cero para disparo de TRIAC.
- Telemetría por Bluetooth HC-06.
- Persistencia en flash y manejo de falla segura.

También se estableció una base sólida de documentación técnica para cierre de entrega final.

El proyecto permitió conocer los Triacs como componentes de control de potencia, además de permitir ahondar en lo que es el desarrollo de sistemas embebidos a pequeña escala. 

## 5.2 Lecciones aprendidas

- El circuito de ZCD actual funciona, pero resulta más complejo de lo necesario para una próxima iteración.
- La compensación temporal del cruce por cero (aprox. 500 $\mu s$) es crítica para estabilidad del dimming.
- La fabricación de PCB artesanal aceleró iteraciones, pero exige mayor cuidado mecánico en footprints de componentes de potencia.
- La telemetría binaria de 2 bytes simplificó integración y depuración con app móvil.

## 5.3 Próximos pasos

Los próximos pasos podrían ser:
- Evaluar una revisión de hardware con ZCD simplificado.
- Mejor mecánica de placa para componentes de potencia (los agujeros).
- Posible control de dimming en microcontrolador dedicado (tal vez un ESP32 o ESP8266) y fuente en la misma placa. 

---

# Capítulo 6: Uso de herramientas de IA

Se documenta el uso de IA según requerimiento docente y archivo `listado de cosas hechas con IA.txt`.

## 6.1 Uso individual y conjunto

- Ignacio:
  - asistencia para extraer estructura de memoria técnica.
  - apoyo en revisión de README y documentación.
  - apoyo en criterios de hardware y selección de componentes.

- Francisco:
  - soporte para flujo de Itemis Create y diagramas de estado.
  - generación de estructura inicial de documentación técnica de statechart (luego revisada manualmente).

- Uso común del equipo:
  - apoyo en redacción y ajuste de memoria técnica.
  - apoyo extensivo en programación STM32 (estructura, módulos y ajustes).
  - apoyo para redacción de descripciones de PR.
  - apoyo en la redacción y corrección de typos en la memoria técnica.

---

# Capítulo 7: Bibliografía y referencias

1. STMicroelectronics, *UM1724 - STM32 Nucleo-64 boards user manual*.  
2. STMicroelectronics, *MB1136 - Electrical Schematic - STM32 Nucleo-64 boards*.  
3. STMicroelectronics, *STM32F103RB Datasheet*.  
4. ON Semiconductor, *MOC3023M Datasheet*.  
5. STMicroelectronics, *BTA06-600C Datasheet / notas de aplicación TRIAC*.  
6. Repositorio del proyecto: `https://github.com/Embebidos-Fran-Marcos-Nacho/tdse-tf_1-2`.

Referencias internas del repositorio:
- `README.md`
- `Informe_de_Avances.md`
- `Seguimiento.md`
- `Diagrama de Harel/STATECHART_EXPLANATION.md`
- `Memoria técnica/cosas e imagenes para memoria técnica - hardware/*`
- `listado de cosas hechas con IA.txt`

---

**Fin de la Memoria Técnica**  
Autores: Ignacio Ezequiel Cavicchioli, Francisco Javier Moya  
Fecha de edición: 19 de febrero de 2026

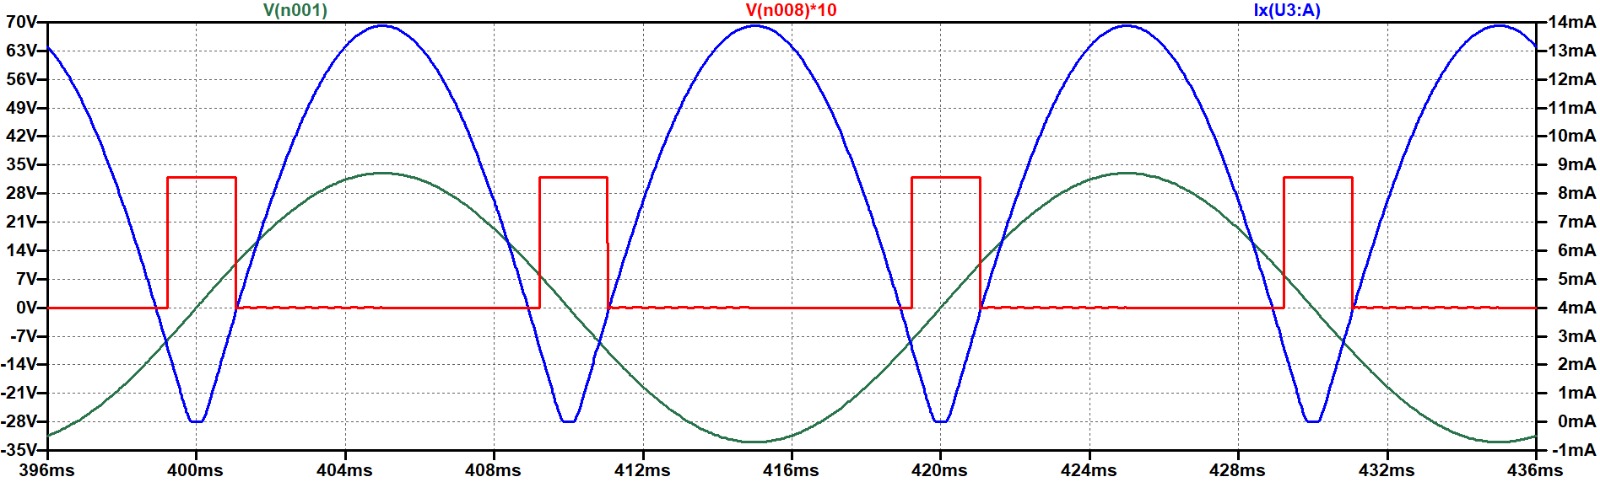
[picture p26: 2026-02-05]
Memoria técnica/cosas e imagenes para memoria técnica - hardware/ZCD/simu completa de salida, tension y correiente por diodo .jpeg

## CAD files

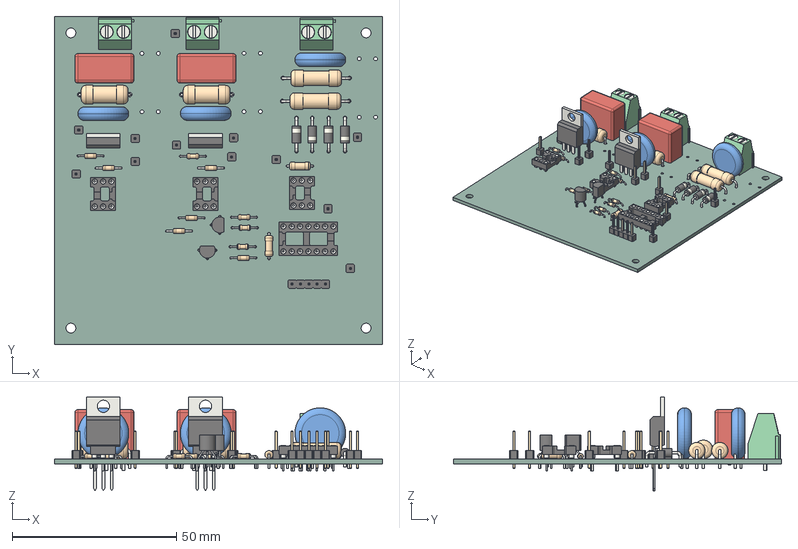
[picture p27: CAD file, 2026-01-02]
3D/assembly/placa alta tension.step
100.0 x 100.0 x 28.5 mm
RV_Disc_D15.5mm_W4.2mm_P7.5mm x 3
PinHeader_1x01_P2.54mm_Vertical x 12
R_Axial_DIN0204_L3.6mm_D1.6mm_P7.62mm_Horizontal x 10
PinHeader_1x05_P2.54mm_Vertical
TerminalBlock_Phoenix_MKDS-1,5-2-5.08_1x02_P5.08mm_Horizontal x 3
R_Axial_DIN0516_L15.5mm_D5.0mm_P20.32mm_Horizontal x 2
TO-220-3_Vertical x 2
TO-92_Wide x 2
R_Axial_DIN0207_L6.3mm_D2.5mm_P7.62mm_Horizontal x 2
DIP-6_W7.62mm_Socket x 3
D_DO-41_SOD81_P10.16mm_Horizontal x 4
R_Axial_DIN0614_L14.3mm_D5.7mm_P15.24mm_Horizontal x 2
C_Rect_L18.0mm_W9.0mm_P15.00mm_FKS3_FKP3 x 2
DIP-14_W7.62mm_Socket
placa alta tension_PCB

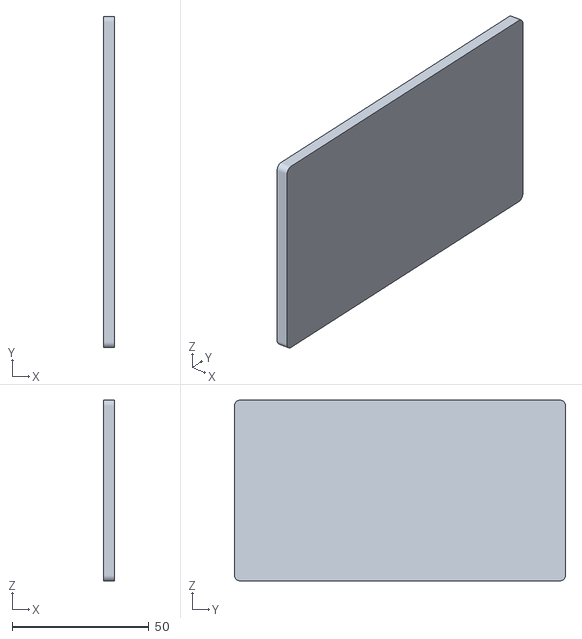
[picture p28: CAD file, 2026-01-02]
3D/back.stl
4.00 x 121.1 x 66.1

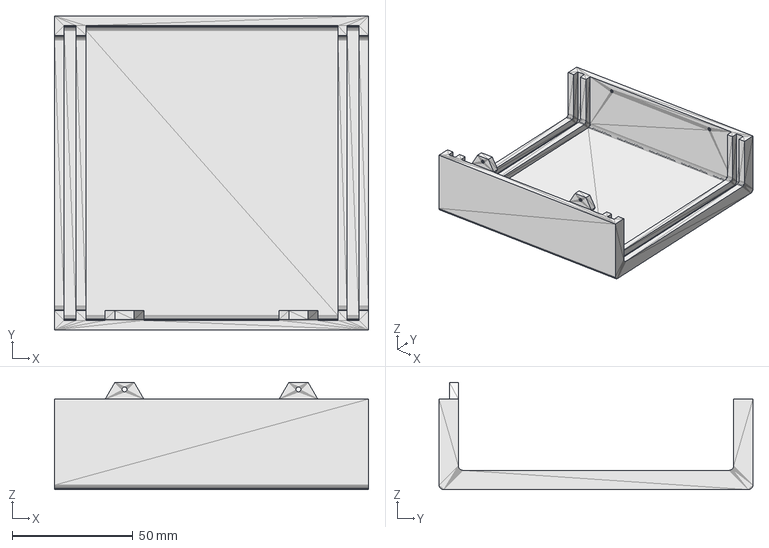
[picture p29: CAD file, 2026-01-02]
3D/assembly/top_bott.step
130.0 x 130.0 x 44.4 mm

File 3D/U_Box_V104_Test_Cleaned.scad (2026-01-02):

/*//////////////////////////////////////////////////////////////////
              -    FB Aka Heartman/Hearty 2016     -                   
              -   http://heartygfx.blogspot.com    -                  
              -       OpenScad Parametric Box      -                     
              -         CC BY-NC 3.0 License       -                      
////////////////////////////////////////////////////////////////////                                                                                                             
12/02/2016 - Fixed minor bug 
28/02/2016 - Added holes ventilation option                    
09/03/2016 - Added PCB feet support, fixed the shell artefact on export mode. 

*/////////////////////////// - Info - //////////////////////////////

// All coordinates are starting as integrated circuit pins.
// From the top view :

//   CoordD           <---       CoordC
//                                 ^
//                                 ^
//                                 ^
//   CoordA           --->       CoordB


////////////////////////////////////////////////////////////////////


////////// - Paramètres de la boite - Box parameters - /////////////

/* [Box dimensions] */
// - Longueur - Length  
  Length        = 130;       
// - Largeur - Width
  Width         = 130;                     
// - Hauteur - Height  
  Height        = 75;  
// - Epaisseur - Wall thickness  
  Thick         = 4;//[2:5]  
  
/* [Box options] */
// - Diamètre Coin arrondi - Filet diameter  
  Filet         = 2;//[0.1:12] 
// - lissage de l'arrondi - Filet smoothness  
  Resolution    = 50;//[1:100] 
// - Tolérance - Tolerance (Panel/rails gap)
  m             = 0.9;
// Pieds PCB - PCB feet (x4) 
  PCBFeet       = 0;// [0:No, 1:Yes]
// - Decorations to ventilation holes
  Vent          = 0;// [0:No, 1:Yes]
// - Decoration-Holes width (in mm)
  Vent_width    = 0;   


  
/* [PCB_Feet] */
//All dimensions are from the center foot axis

// - Coin bas gauche - Low left corner X position
PCBPosX         = 5;
// - Coin bas gauche - Low left corner Y position
PCBPosY         = 5;
// - Longueur PCB - PCB Length
PCBLength       = 100;
// - Largeur PCB - PCB Width
PCBWidth        = 100;
// - Heuteur pied - Feet height
FootHeight      = 10;
// - Diamètre pied - Foot diameter
FootDia         = 8;
// - Diamètre trou - Hole diameter
FootHole        = 3;  
  

/* [STL element to export] */
//Coque haut - Top shell
TShell          = 1;// [0:No, 1:Yes]
//Coque bas- Bottom shell
BShell          = 1;// [0:No, 1:Yes]
//Panneau avant - Front panel
FPanL           = 1;// [0:No, 1:Yes]
//Panneau arrière - Back panel  
BPanL           = 1;// [0:No, 1:Yes]


  
/* [Hidden] */
// - Couleur coque - Shell color  
Couleur1        = "Orange";       
// - Couleur panneaux - Panels color    
Couleur2        = "OrangeRed";    
// Thick X 2 - making decorations thicker if it is a vent to make sure they go through shell
Dec_Thick       = Vent ? Thick*2 : Thick; 
// - Depth decoration
Dec_size        = Vent ? Thick*2 : 0.8;





/////////// - Boitier générique bord arrondis - Generic rounded box - //////////

module RoundBox($a=Length, $b=Width, $c=Height){// Cube bords arrondis
                    $fn=Resolution;            
                    translate([0,Filet,Filet]){  
                    minkowski (){                                              
                        cube ([$a-(Length/2),$b-(2*Filet),$c-(2*Filet)], center = false);
                        rotate([0,90,0]){    
                        cylinder(r=Filet,h=Length/2, center = false);
                            } 
                        }
                    }
                }// End of RoundBox Module

      
////////////////////////////////// - Module Coque/Shell - //////////////////////////////////         

module Coque(){//Coque - Shell  
    Thick = Thick*2;  
    difference(){    
        difference(){//sides decoration
            union(){    
                     difference() {//soustraction de la forme centrale - Substraction Fileted box
                      
                        difference(){//soustraction cube median - Median cube slicer
                            union() {//union               
                            difference(){//Coque    
                                RoundBox();
                                translate([Thick/2,Thick/2,Thick/2]){     
                                        RoundBox($a=Length-Thick, $b=Width-Thick, $c=Height-Thick);
                                        }
                                        }//Fin diff Coque                            
                                difference(){//largeur Rails        
                                     translate([Thick+m,Thick/2,Thick/2]){// Rails
                                          RoundBox($a=Length-((2*Thick)+(2*m)), $b=Width-Thick, $c=Height-(Thick*2));
                                                          }//fin Rails
                                     translate([((Thick+m/2)*1.55),Thick/2,Thick/2+0.1]){ // +0.1 added to avoid the artefact
                                          RoundBox($a=Length-((Thick*3)+2*m), $b=Width-Thick, $c=Height-Thick);
                                                    }           
                                                }//Fin largeur Rails
                                    }//Fin union                                   
                               translate([-Thick,-Thick,Height/2]){// Cube à soustraire
                                    cube ([Length+100, Width+100, Height], center=false);
                                            }                                            
                                      }//fin soustraction cube median - End Median cube slicer
                               translate([-Thick/2,Thick,Thick]){// Forme de soustraction centrale 
                                    RoundBox($a=Length+Thick, $b=Width-Thick*2, $c=Height-Thick);       
                                    }                          
                                }                                          


                difference(){// wall fixation box legs
                    union(){
                        translate([3*Thick +5,Thick,Height/2]){
                            rotate([90,0,0]){
                                    $fn=6;
                                    cylinder(d=16,Thick/2);
                                    }   
                            }
                            
                       translate([Length-((3*Thick)+5),Thick,Height/2]){
                            rotate([90,0,0]){
                                    $fn=6;
                                    cylinder(d=16,Thick/2);
                                    }   
                            }

                        }
                            translate([4,Thick+Filet,Height/2-57]){   
                             rotate([45,0,0]){
                                   cube([Length,40,40]);    
                                  }
                           }
                           translate([0,-(Thick*1.46),Height/2]){
                                cube([Length,Thick*2,10]);
                           }
                    } //Fin fixation box legs
            }

        union(){// outbox sides decorations
            
            for(i=[0:Thick:Length/4]){

                // Ventilation holes part code submitted by Ettie - Thanks ;) 
                    translate([10+i,-Dec_Thick+Dec_size,1]){
                    cube([Vent_width,Dec_Thick,Height/4]);
                    }
                    translate([(Length-10) - i,-Dec_Thick+Dec_size,1]){
                    cube([Vent_width,Dec_Thick,Height/4]);
                    }
                    translate([(Length-10) - i,Width-Dec_size,1]){
                    cube([Vent_width,Dec_Thick,Height/4]);
                    }
                    translate([10+i,Width-Dec_size,1]){
                    cube([Vent_width,Dec_Thick,Height/4]);
                    }
  
                
                    }// fin de for
               // }
                }//fin union decoration
            }//fin difference decoration
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

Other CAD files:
3D/bottom.stl
3D/assembly/back.step
3D - deprecated/assembly/back.step
3D - deprecated/bottom.stl
3D - deprecated/assembly/OldVersions/back.0004.ipt
3D - deprecated/assembly/OldVersions/bott.0004.ipt
3D - deprecated/assembly/OldVersions/topt.0008.ipt
3D - deprecated/assembly/back.ipt
3D - deprecated/assembly/bott.ipt
3D - deprecated/assembly/front.ipt
3D - deprecated/assembly/top_bott.ipt
3D - deprecated/assembly/topt.ipt
3D/assembly/back.ipt
3D/assembly/bott.ipt
3D/assembly/front.ipt
3D/assembly/top_bott.ipt
3D/assembly/topt.ipt

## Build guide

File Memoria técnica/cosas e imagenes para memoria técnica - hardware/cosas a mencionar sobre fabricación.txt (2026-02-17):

- para fabricar se usó el pnp blue que está bueno, con cloruro férrico de acido. 
- el circuito de ZCD es más complejo de lo necesario. con un rectificador normal podes hacer la estadística de la frecuencia para triggear siempre bien en el 2do semiciclo (que no lo recibis como interrupción)
- si lo haces como está ahora la macana es que tenes que tener una idea del timing para ver realmente cuando está el zero. 
- en nuestro caso tenemos que esperar 500us desde el flanco ascendente para estar sobre el verdadero cruce por cero.
- las simulaciones dieron muy parecidas
- como se usó 24 VAC las resistencais de 10K se cortocirtuitaron por debajo de la placa con unas resistencias de 0 ohms. 
- 1ero se probó el ZCD, luego se soldadron los de triacs y se probó todo con 24VAC
- proxima versión podría tener el usb C uart module removible (solo los pines) con un micro tipo attiny en la misma placa para directamente hacer todo dimming ahí, luego solo se habla con la placa con una tensión analógica o algo así
- proxima versión debe tener los agujeros de diametro correcto para los varistores y componentes más grades, todo mal excepto para las resistencias chicas de 1/4 o 1/2 de watt. 
- prox versión solo 1 triac y 1 zcd o por separado, algo más económico, seguramente 1 optoacomplador mas simple que de triac y el triac de potencia, se debe investigar. 
- tuve que configurar el modulo bluetooth con comandos at desde consola
- la placa se probo que no haya cortos a manopla con continuidad de tester.

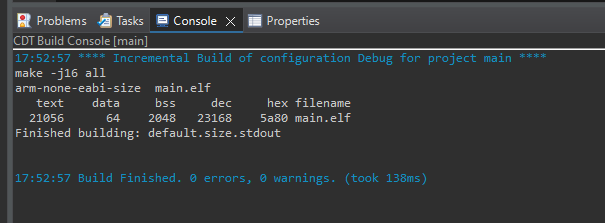
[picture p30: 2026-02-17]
Memoria técnica/imgs/build console.png

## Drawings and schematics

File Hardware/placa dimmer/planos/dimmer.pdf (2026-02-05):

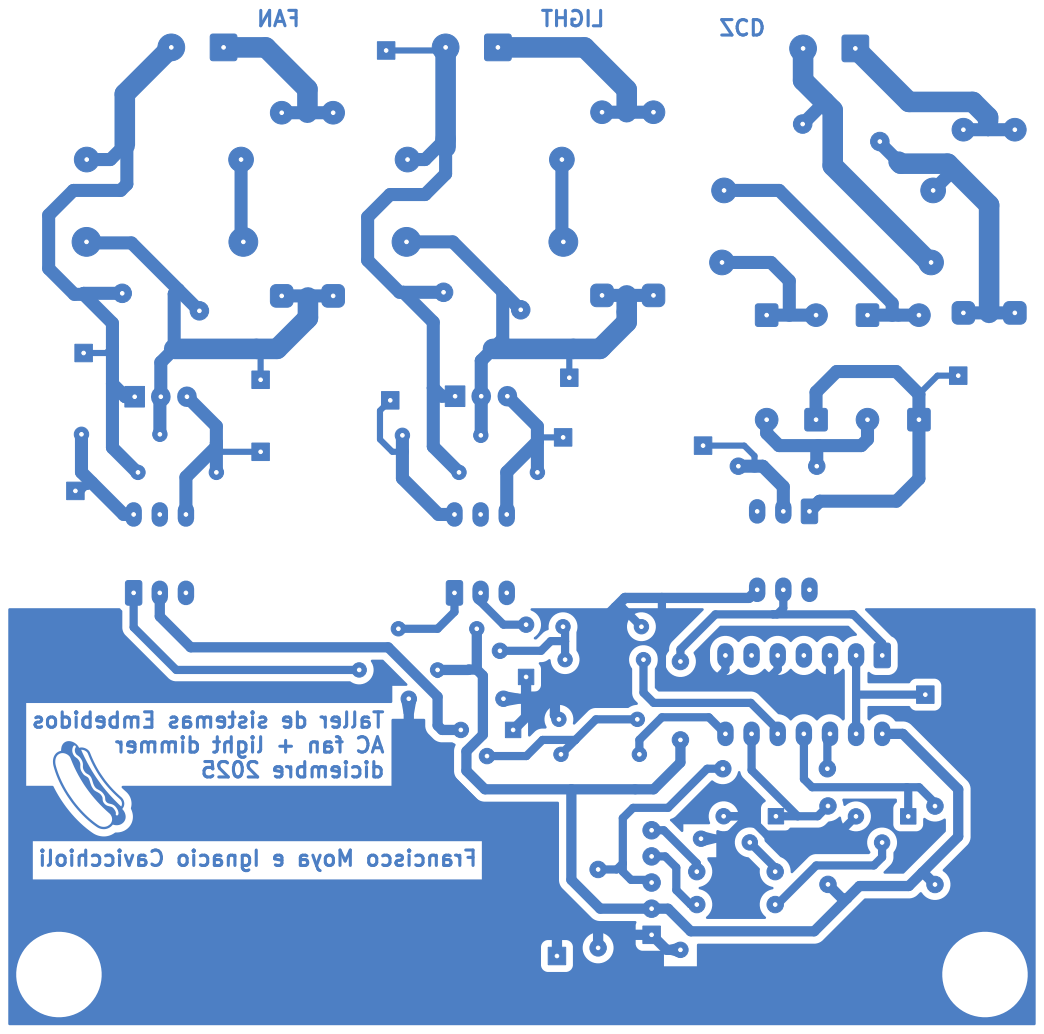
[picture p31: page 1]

Embebidos sistemas de Taller dimmer light + fan AC

Cavicchioli Ignacio e Moya Francisco

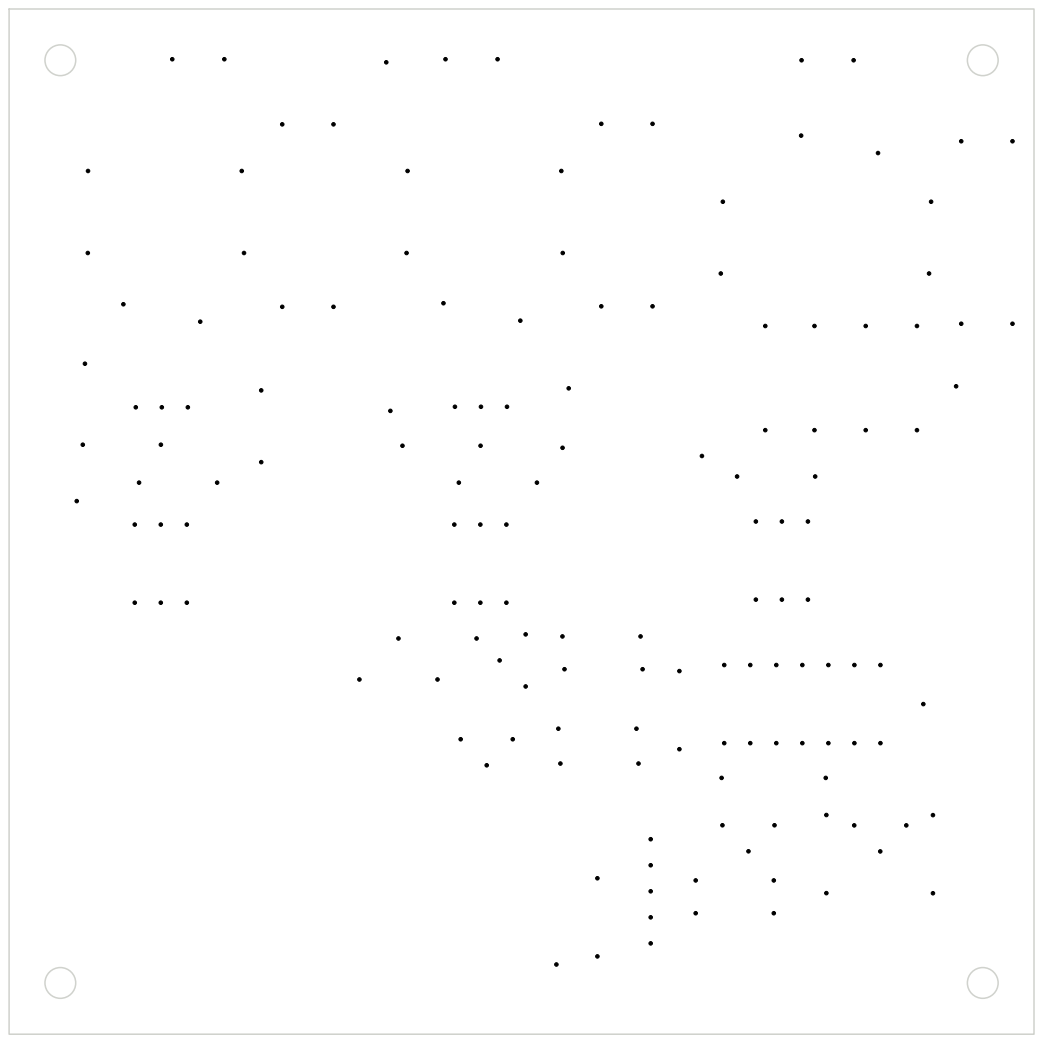
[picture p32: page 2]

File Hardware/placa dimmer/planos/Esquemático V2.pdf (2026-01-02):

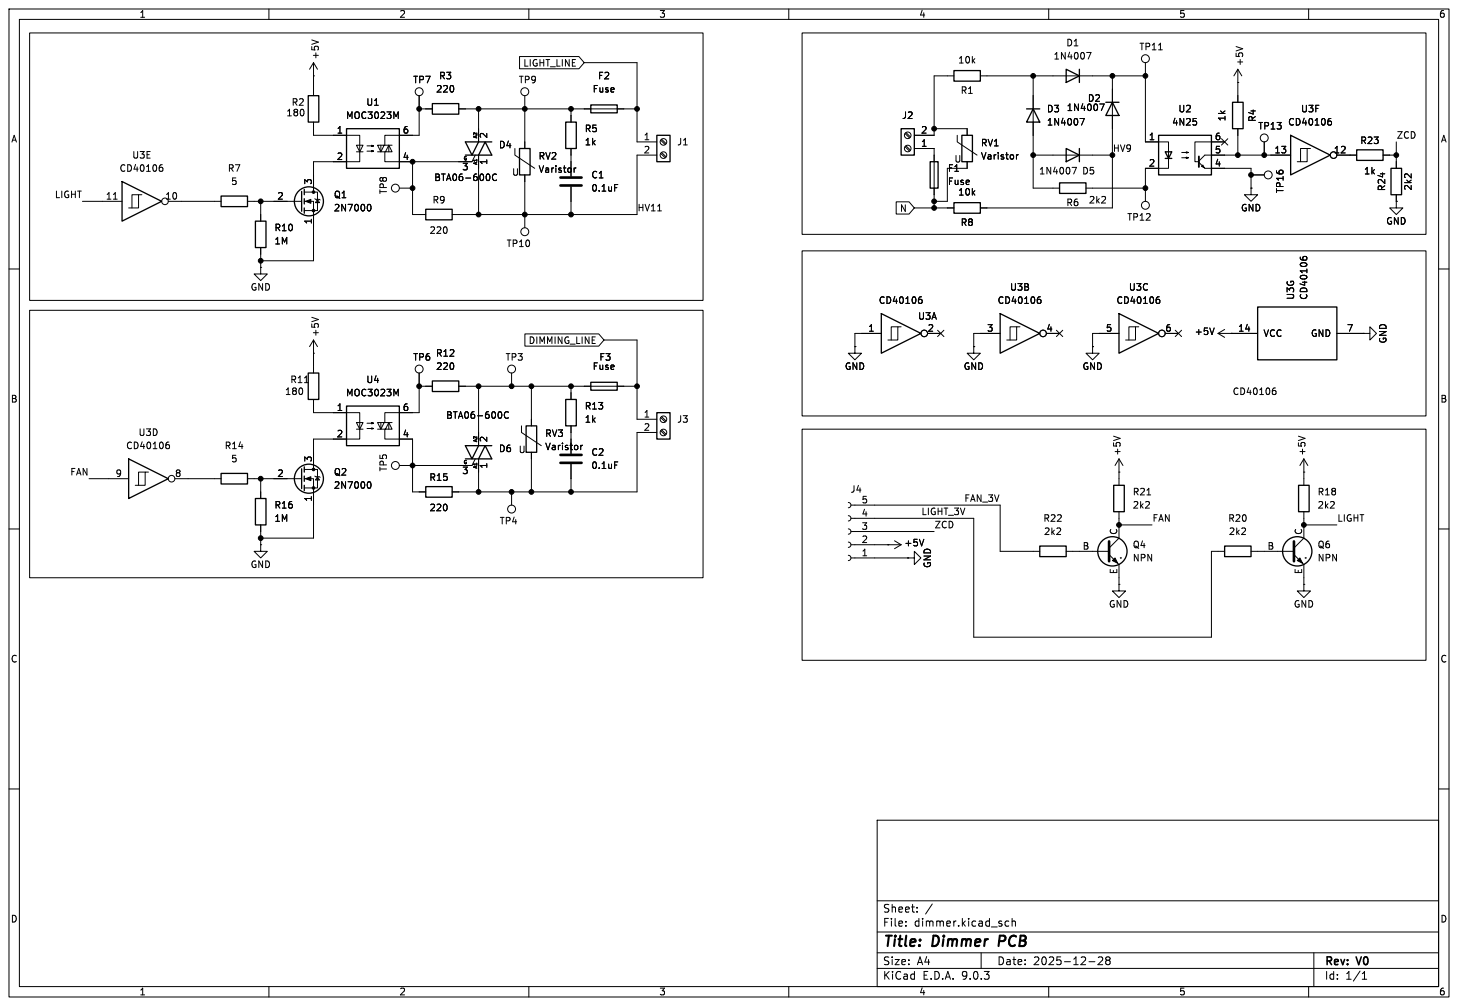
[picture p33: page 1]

File: dimmer.kicad_sch Sheet: /
Id: 1/1 Title: Dimmer PCB

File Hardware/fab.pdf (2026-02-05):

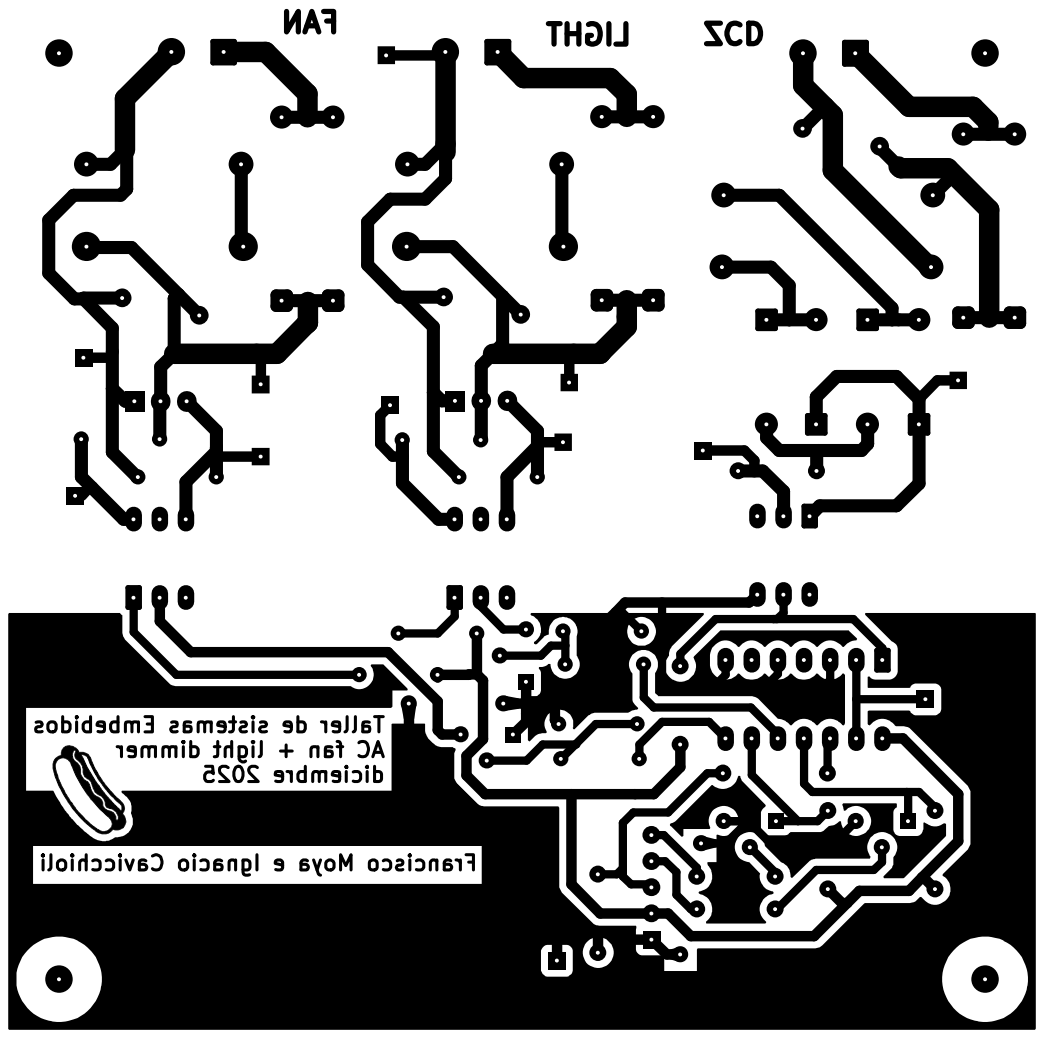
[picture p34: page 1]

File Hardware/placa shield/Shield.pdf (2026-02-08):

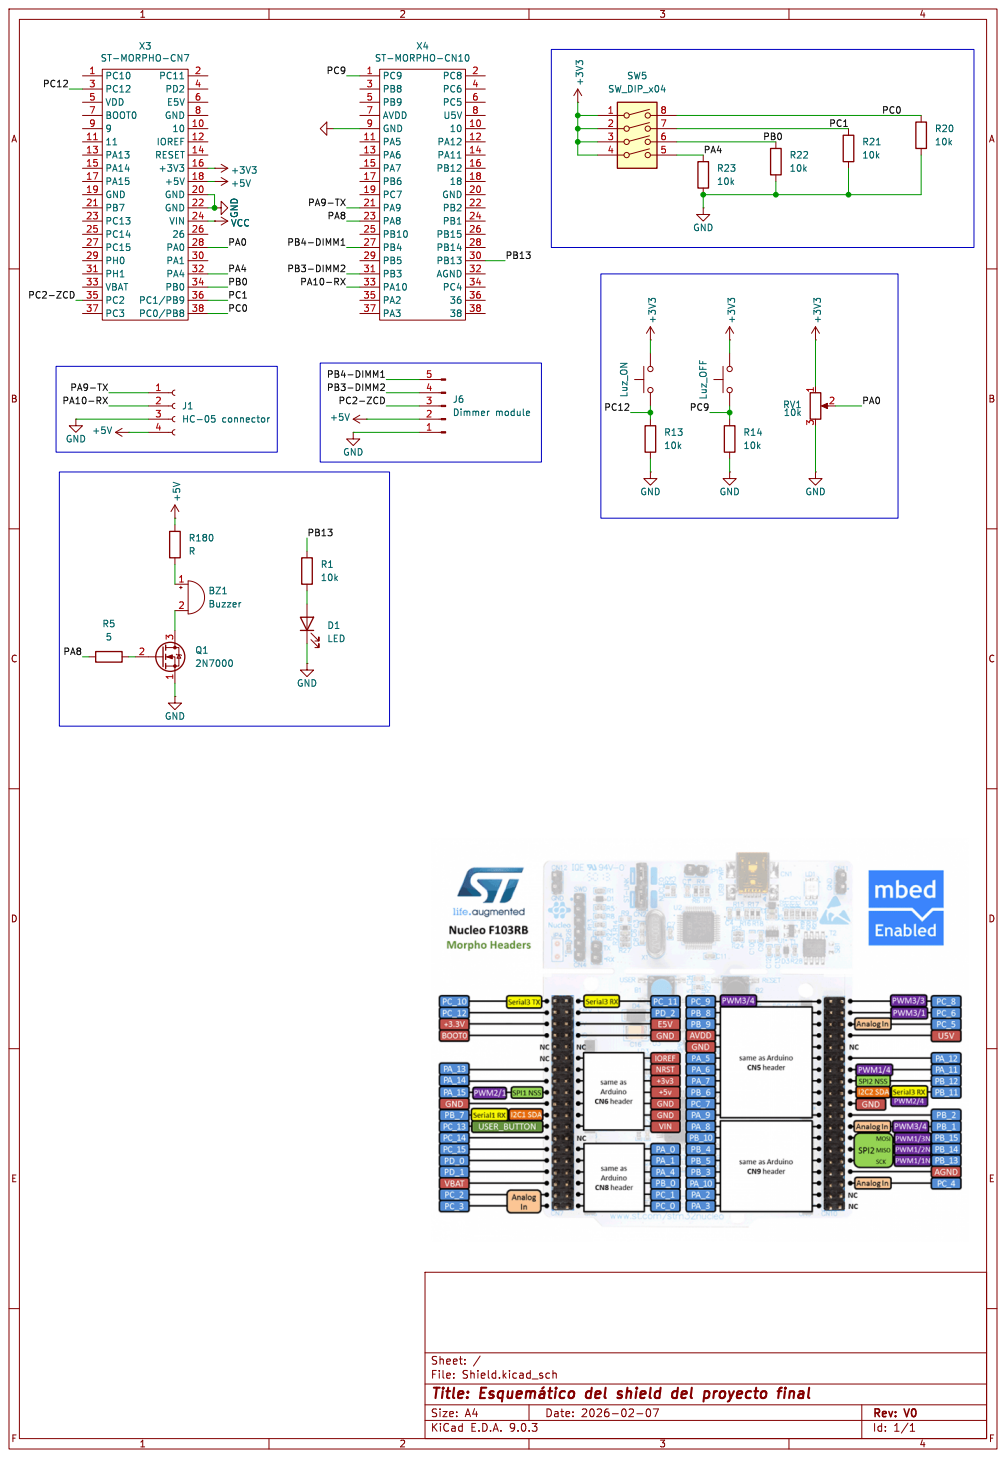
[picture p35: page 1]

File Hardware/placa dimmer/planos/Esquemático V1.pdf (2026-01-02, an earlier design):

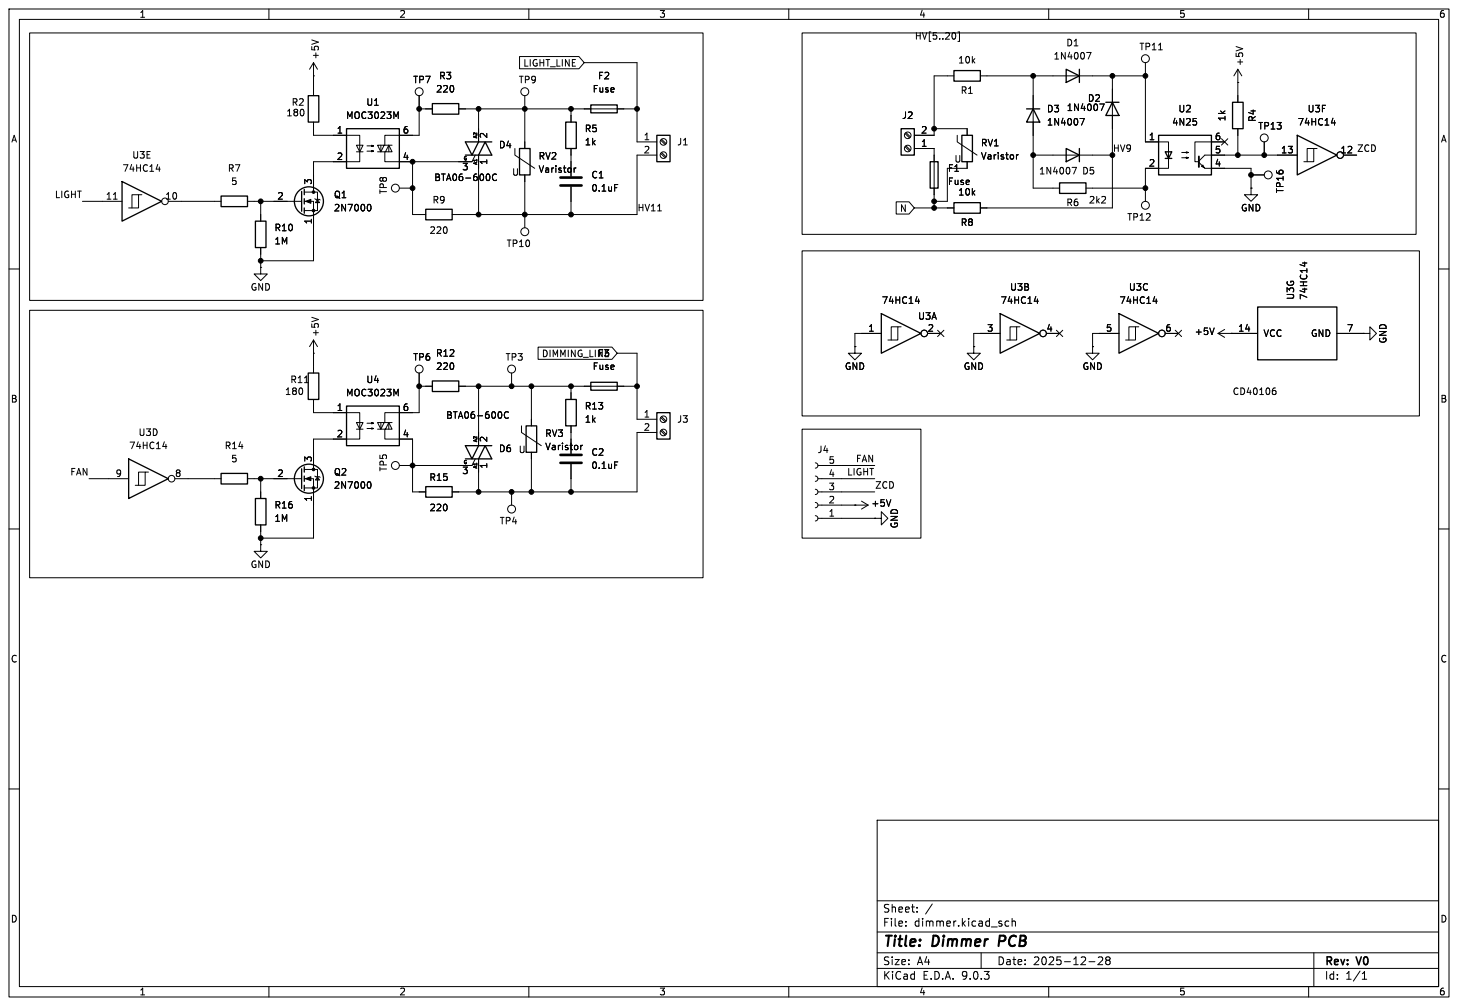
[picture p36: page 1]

File: dimmer.kicad_sch Sheet: /
Id: 1/1 Title: Dimmer PCB

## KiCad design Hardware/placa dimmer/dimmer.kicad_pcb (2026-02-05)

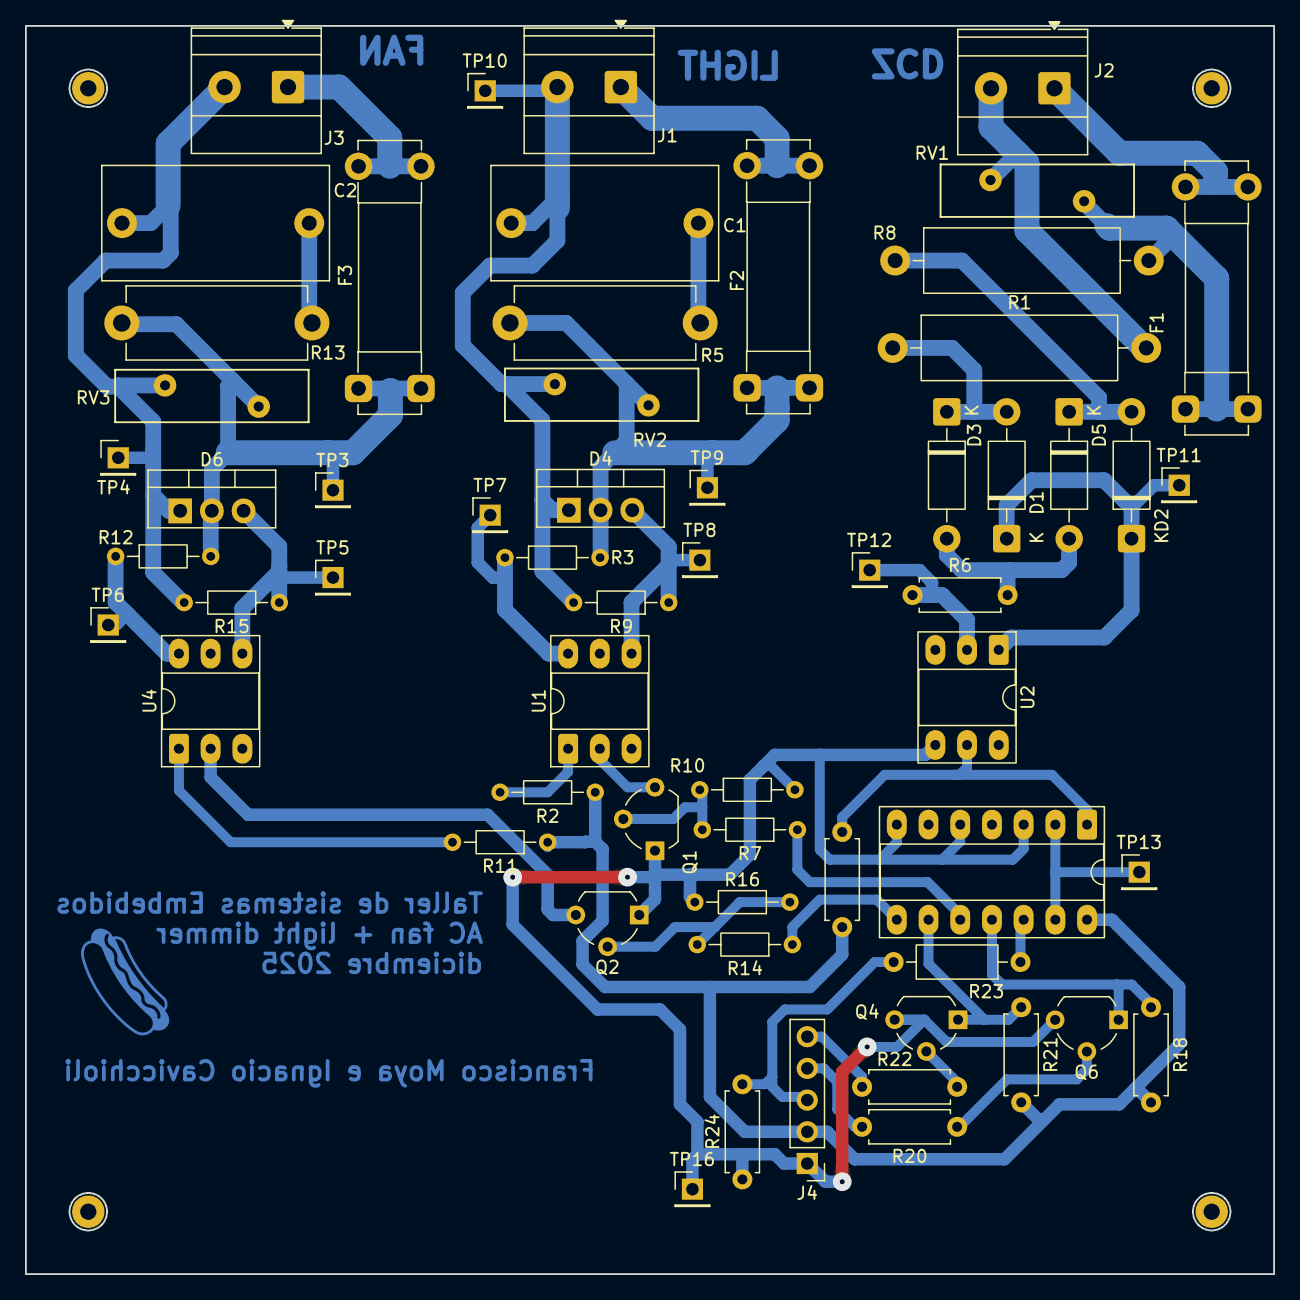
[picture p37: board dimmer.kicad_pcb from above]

Board: 2 copper layers, 100.0 x 100.0 mm, 60 parts (0 on the bottom side), 40 nets.

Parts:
C1, C2: 0.1uF; C_Rect_L18.0mm_W9.0mm_P15.00mm_FKS3_FKP3
D1, D2, D3, D5: 1N4007; D_DO-41_SOD81_P10.16mm_Horizontal
D4, D6: BTA06-600C; TO-220-3_Vertical
F1, F2, F3: Fuse; Fuseholder_Clip-5x20mm_Bel_FC-203-22_Lateral_P17.80x5.00mm_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
J1, J2, J3: Screw_Terminal_01x02; TerminalBlock_Phoenix_MKDS-1,5-2-5.08_1x02_P5.08mm_Horizont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
J4: Conn_01x05_Socket; PinHeader_1x05_P2.54mm_Vertical
Q1, Q2: 2N7000; TO-92_Wide
Q4, Q6: NPN; TO-92_Wide
R1, R8: 10k; R_Axial_DIN0516_L15.5mm_D5.0mm_P20.32mm_Horizontal
R2, R11: 180; R_Axial_DIN0204_L3.6mm_D1.6mm_P7.62mm_Horizontal
R3, R9, R12, R15: 220; R_Axial_DIN0204_L3.6mm_D1.6mm_P7.62mm_Horizontal
R4: 1k; R_Axial_DIN0207_L6.3mm_D2.5mm_P7.62mm_Horizontal
R5, R13: 1k; R_Axial_DIN0614_L14.3mm_D5.7mm_P15.24mm_Horizontal
R6, R18, R20, R21, R22, R24: 2k2; R_Axial_DIN0207_L6.3mm_D2.5mm_P7.62mm_Horizontal
R7, R14: 5; R_Axial_DIN0204_L3.6mm_D1.6mm_P7.62mm_Horizontal
R10, R16: 1M; R_Axial_DIN0204_L3.6mm_D1.6mm_P7.62mm_Horizontal
R23: 1k; R_Axial_DIN0207_L6.3mm_D2.5mm_P10.16mm_Horizontal
RV1, RV2, RV3: Varistor; RV_Disc_D15.5mm_W4.2mm_P7.5mm
TP3, TP4, TP5, TP6, TP7, TP8, TP9, TP10, TP11, TP12, TP13, TP16: TestPoint; PinHeader_1x01_P2.54mm_Vertical
U1, U4: MOC3023M; DIP-6_W7.62mm_Socket_LongPads
U2: 4N25; DIP-6_W7.62mm_Socket_LongPads
U3: CD40106; DIP-14_W7.62mm_Socket_LongPads

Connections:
+5V: J4.2, R2.1, R4.1, R11.1, R18.2, R21.2, U3.14 (VCC)
/FAN: Q4.1 (C), R21.1, U3.9
/FAN_3V: J4.5, R22.2
/HV9: D2.2 (A), D5.1 (K), R8.1
/HV11: C1.2, D4.1 (A1), J1.2, R9.2, RV2.2, TP10.1
/LIGHT: Q6.1 (C), R18.1, U3.11
/LIGHT_3V: J4.4, R20.2
/ZCD: J4.3, R23.2, R24.2
DIMMING_LINE: F3.2, J3.1
GND: J4.1, Q1.1 (S), Q2.1 (S), Q4.3 (E), Q6.3 (E), R10.2, R16.2, R24.1, TP16.1, U2.4, U3.3, U3.5, U3.7 (GND)
LIGHT_LINE: F2.2, J1.1
N: F1.1, R8.2, RV1.2
unnamed: C1.1, R5.1
unnamed: C2.1, R13.1
unnamed: D1.2 (A), D3.1 (K), R1.1
unnamed: D1.1 (K), D2.1 (K), TP11.1, U2.1
unnamed: D3.2 (A), D5.2 (A), R6.2
unnamed: D4.2 (A2), F2.1, R3.2, R5.2, RV2.1, TP9.1
unnamed: D4.3 (G), R9.1, TP8.1, U1.4
unnamed: C2.2, D6.1 (A1), J3.2, R15.2, RV3.2, TP4.1
unnamed: D6.2 (A2), F3.1, R12.2, R13.2, RV3.1, TP3.1
unnamed: D6.3 (G), R15.1, TP5.1, U4.4
unnamed: F1.2, J2.1
unnamed: J2.2, R1.2, RV1.1
unnamed: Q1.3 (D), U1.2
unnamed: Q1.2 (G), R7.2, R10.1
unnamed: Q2.3 (D), U4.2
unnamed: Q2.2 (G), R14.2, R16.1
unnamed: Q4.2 (B), R22.1
unnamed: Q6.2 (B), R20.1
unnamed: R2.2, U1.1
unnamed: R3.1, TP7.1, U1.6
unnamed: R4.2, U2.5, U3.1
unnamed: R6.1, TP12.1, U2.2
unnamed: R7.1, U3.10
unnamed: R11.2, U4.1
unnamed: R12.1, TP6.1, U4.6
unnamed: R14.1, U3.8
unnamed: R23.1, U3.12
unnamed: TP13.1, U3.2, U3.13

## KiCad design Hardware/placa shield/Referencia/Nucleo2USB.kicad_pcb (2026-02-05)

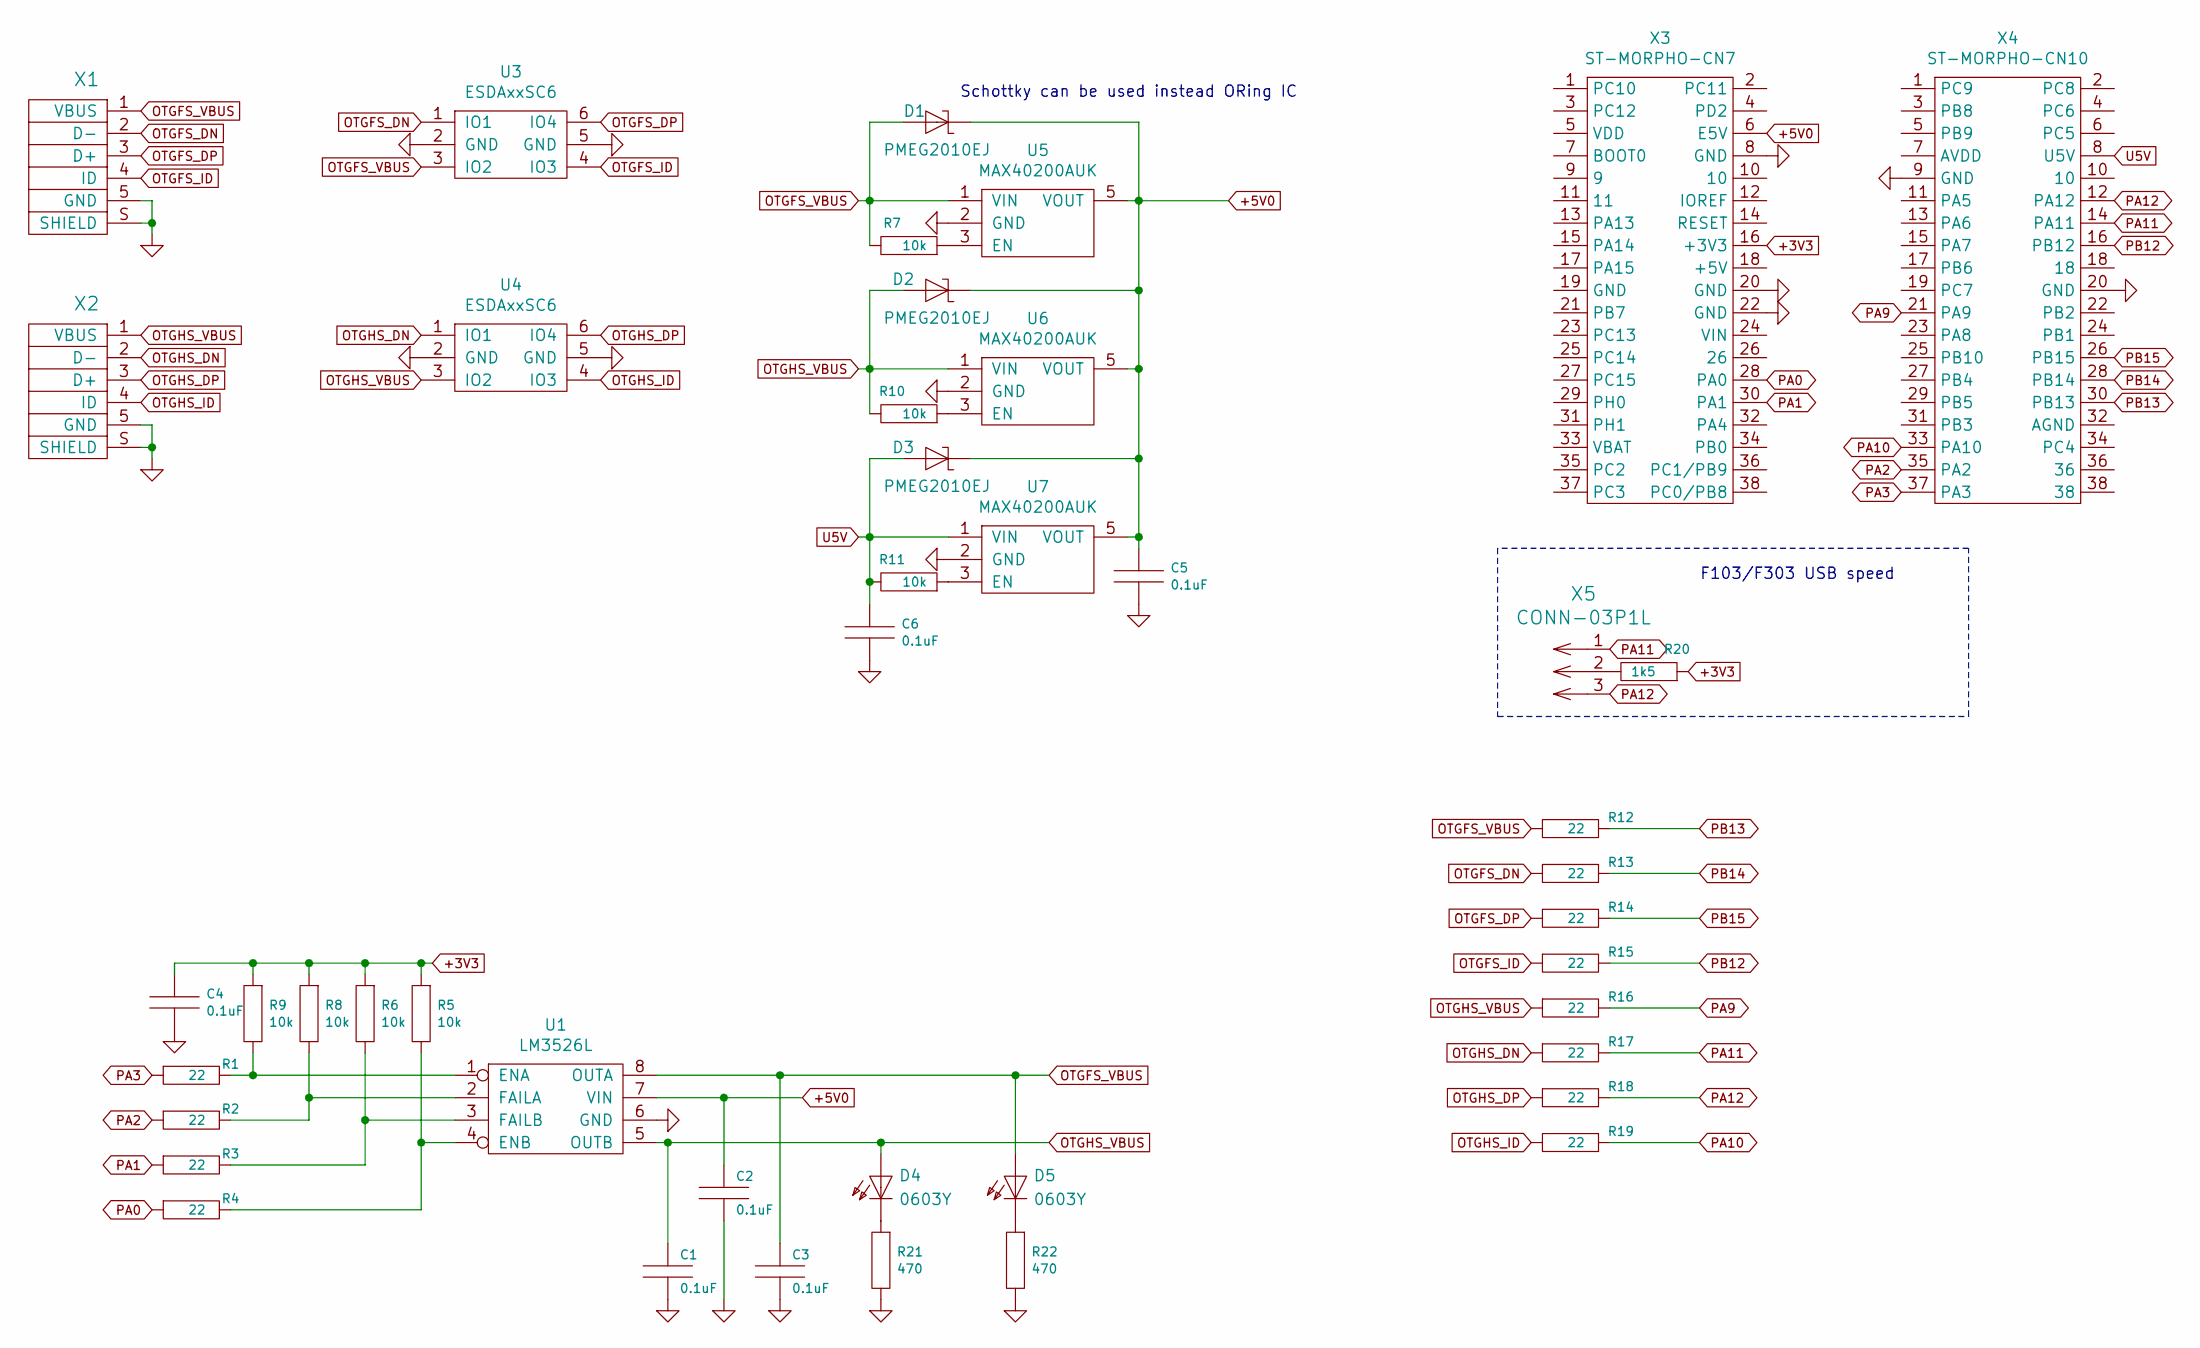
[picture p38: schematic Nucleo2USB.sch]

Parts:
C1, C2, C3, C4, C5, C6: 0.1uF; SMD-0603C
D1, D2, D3: PMEG2010EJ; SOD-123F
D4, D5: 0603Y; LED-0603
R1, R2, R3, R4, R12, R13, R14, R15, R16, R17, R18, R19: 22; SMD-0603R
R5, R6, R7, R8, R9, R10, R11: 10k; SMD-0603R
R20: 1k5; SMD-0603R
R21, R22: 470; SMD-0603R
U1: LM3526L; SO65P030X044-8
U3, U4: ESDAxxSC6; SOT-23-6
U5, U6, U7: MAX40200AUK; SOT-23-5
X1, X2: USB-OTG; AMP10118194-0001LF
X3: ST-MORPHO-CN7; DS1023-04-2X19A11
X4: ST-MORPHO-CN10; DS1023-04-2X19A11
X5: CONN-03P1L; DS1021-1X03S61

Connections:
+3V3: C4.1 (C1), R5.1 (R1), R6.1 (R1), R8.1 (R1), R9.1 (R1), R20.1 (R1), X3.16 (+3V3)
+5V0: C2.1 (C1), C5.1 (C1), D1.1 (K), D2.1 (K), D3.1 (K), U1.7 (VIN), U5.5 (VOUT), U6.5 (VOUT), U7.5 (VOUT), X3.6 (E5V)
AGND: C1.2 (C2), C2.2 (C2), C3.2 (C2), C4.2 (C2), C5.2 (C2), C6.2 (C2), R21.2 (R2), R22.2 (R2), U1.6 (GND), U3.2 (GND), U3.5 (GND), U4.2 (GND), U4.5 (GND), U5.2 (GND), U6.2 (GND), U7.2 (GND), X1.5 (GND), X1.S (SHIELD), X2.5 (GND), X2.S (SHIELD), X3.8 (GND), X3.20 (GND), X3.22 (GND), X4.9 (GND), X4.20 (GND)
unnamed: D4.K, R21.1 (R1)
unnamed: D5.K, R22.1 (R1)
unnamed: R1.2 (R2), R9.2 (R2), U1.1 (ENA)
unnamed: R2.2 (R2), R8.2 (R2), U1.2 (FAILA)
unnamed: R3.2 (R2), R6.2 (R2), U1.3 (FAILB)
unnamed: R4.2 (R2), R5.2 (R2), U1.4 (ENB)
unnamed: R7.1 (R1), U5.3 (EN)
unnamed: R10.1 (R1), U6.3 (EN)
unnamed: R11.1 (R1), U7.3 (EN)
unnamed: R20.2 (R2), X5.2
OTGFS_DN: R13.1 (R1), U3.1 (IO1), X1.2 (D-)
OTGFS_DP: R14.1 (R1), U3.6 (IO4), X1.3 (D+)
OTGFS_ID: R15.1 (R1), U3.4 (IO3), X1.4 (ID)
OTGFS_VBUS: C3.1 (C1), D1.2 (A), D5.A, R7.2 (R2), R12.1 (R1), U1.8 (OUTA), U3.3 (IO2), U5.1 (VIN), X1.1 (VBUS)
OTGHS_DN: R17.1 (R1), U4.1 (IO1), X2.2 (D-)
OTGHS_DP: R18.1 (R1), U4.6 (IO4), X2.3 (D+)
OTGHS_ID: R19.1 (R1), U4.4 (IO3), X2.4 (ID)
OTGHS_VBUS: C1.1 (C1), D2.2 (A), D4.A, R10.2 (R2), R16.1 (R1), U1.5 (OUTB), U4.3 (IO2), U6.1 (VIN), X2.1 (VBUS)
PA0: R4.1 (R1), X3.28 (PA0)
PA1: R3.1 (R1), X3.30 (PA1)
PA2: R2.1 (R1), X4.35 (PA2)
PA3: R1.1 (R1), X4.37 (PA3)
PA9: R16.2 (R2), X4.21 (PA9)
PA10: R19.2 (R2), X4.33 (PA10)
PA11: R17.2 (R2), X4.14 (PA11), X5.1
PA12: R18.2 (R2), X4.12 (PA12), X5.3
PB12: R15.2 (R2), X4.16 (PB12)
PB13: R12.2 (R2), X4.30 (PB13)
PB14: R13.2 (R2), X4.28 (PB14)
PB15: R14.2 (R2), X4.26 (PB15)
U5V: C6.1 (C1), D3.2 (A), R11.2 (R2), U7.1 (VIN), X4.8 (U5V)

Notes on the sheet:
F103/F303 USB speed
Schottky can be used instead ORing IC

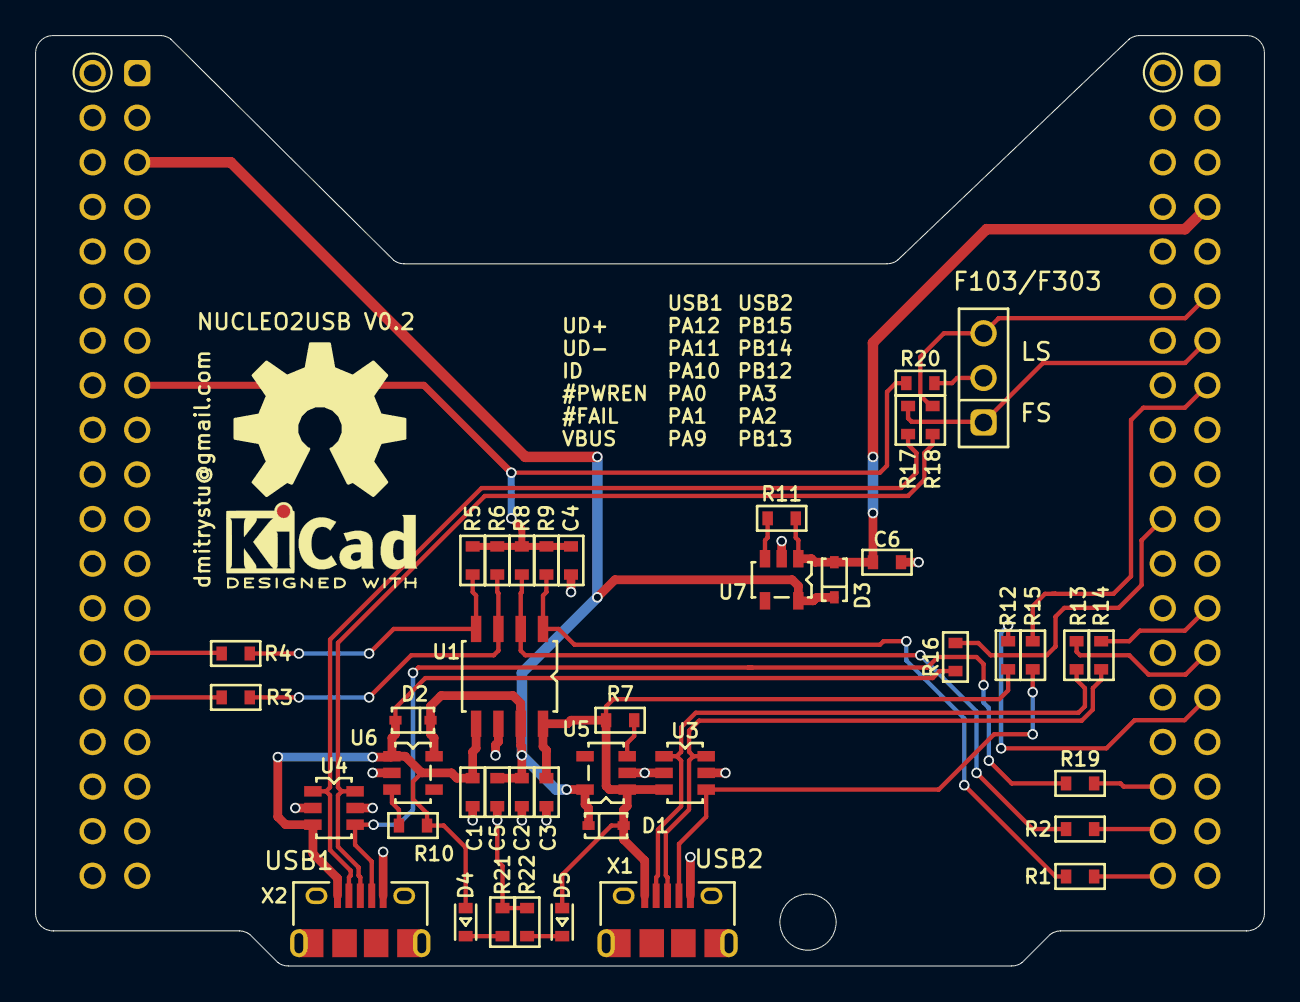
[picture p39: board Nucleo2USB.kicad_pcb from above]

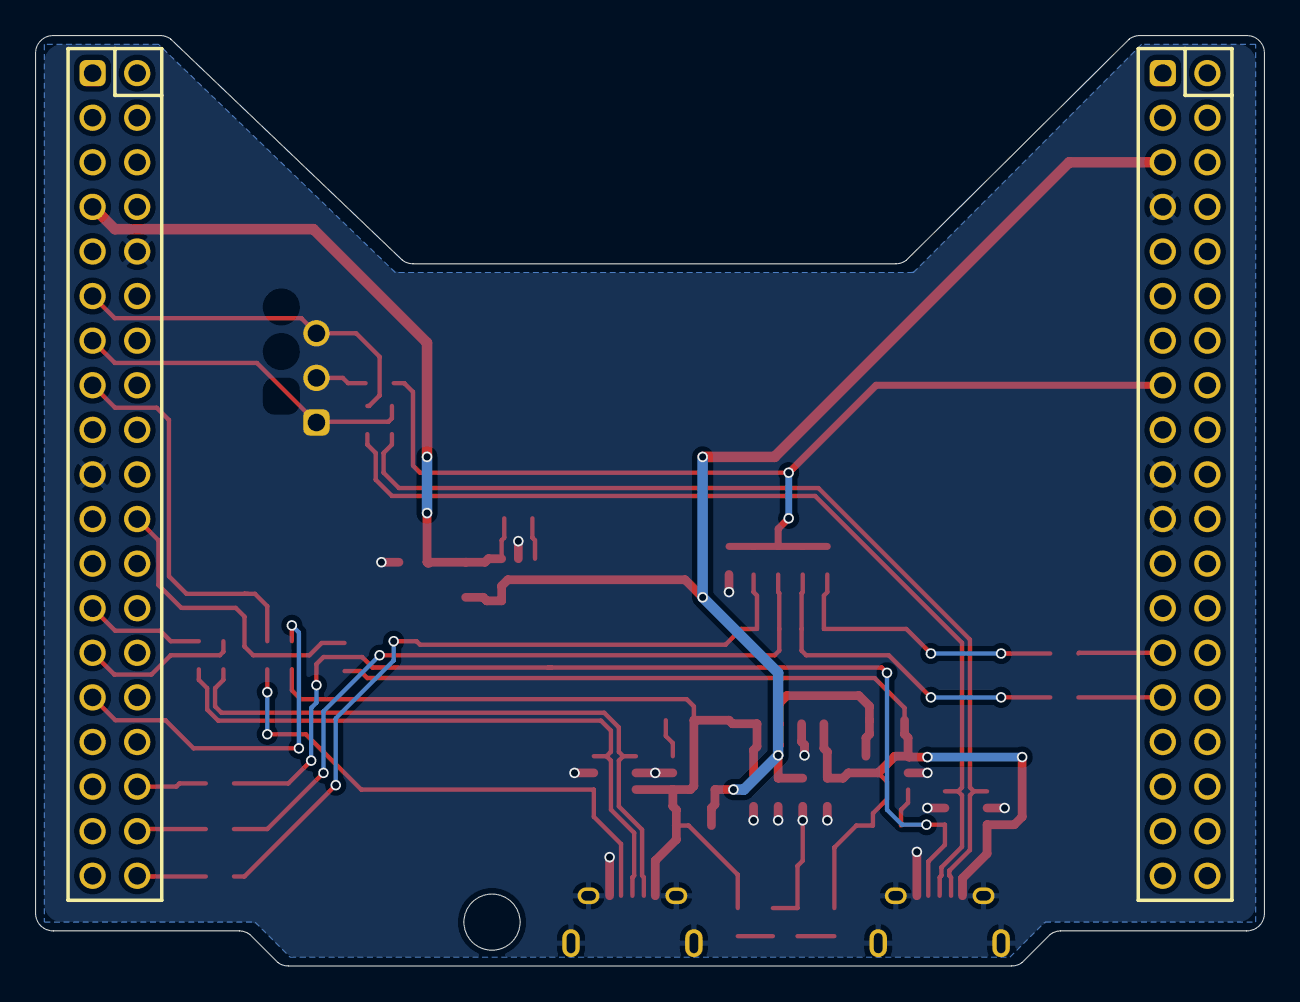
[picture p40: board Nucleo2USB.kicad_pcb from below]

Board: 2 copper layers, 70.0 x 53.0 mm, 45 parts (2 on the bottom side), 34 nets.

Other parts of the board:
OSHW_FS_10MM: VAL**; OSHW_FS_10MM

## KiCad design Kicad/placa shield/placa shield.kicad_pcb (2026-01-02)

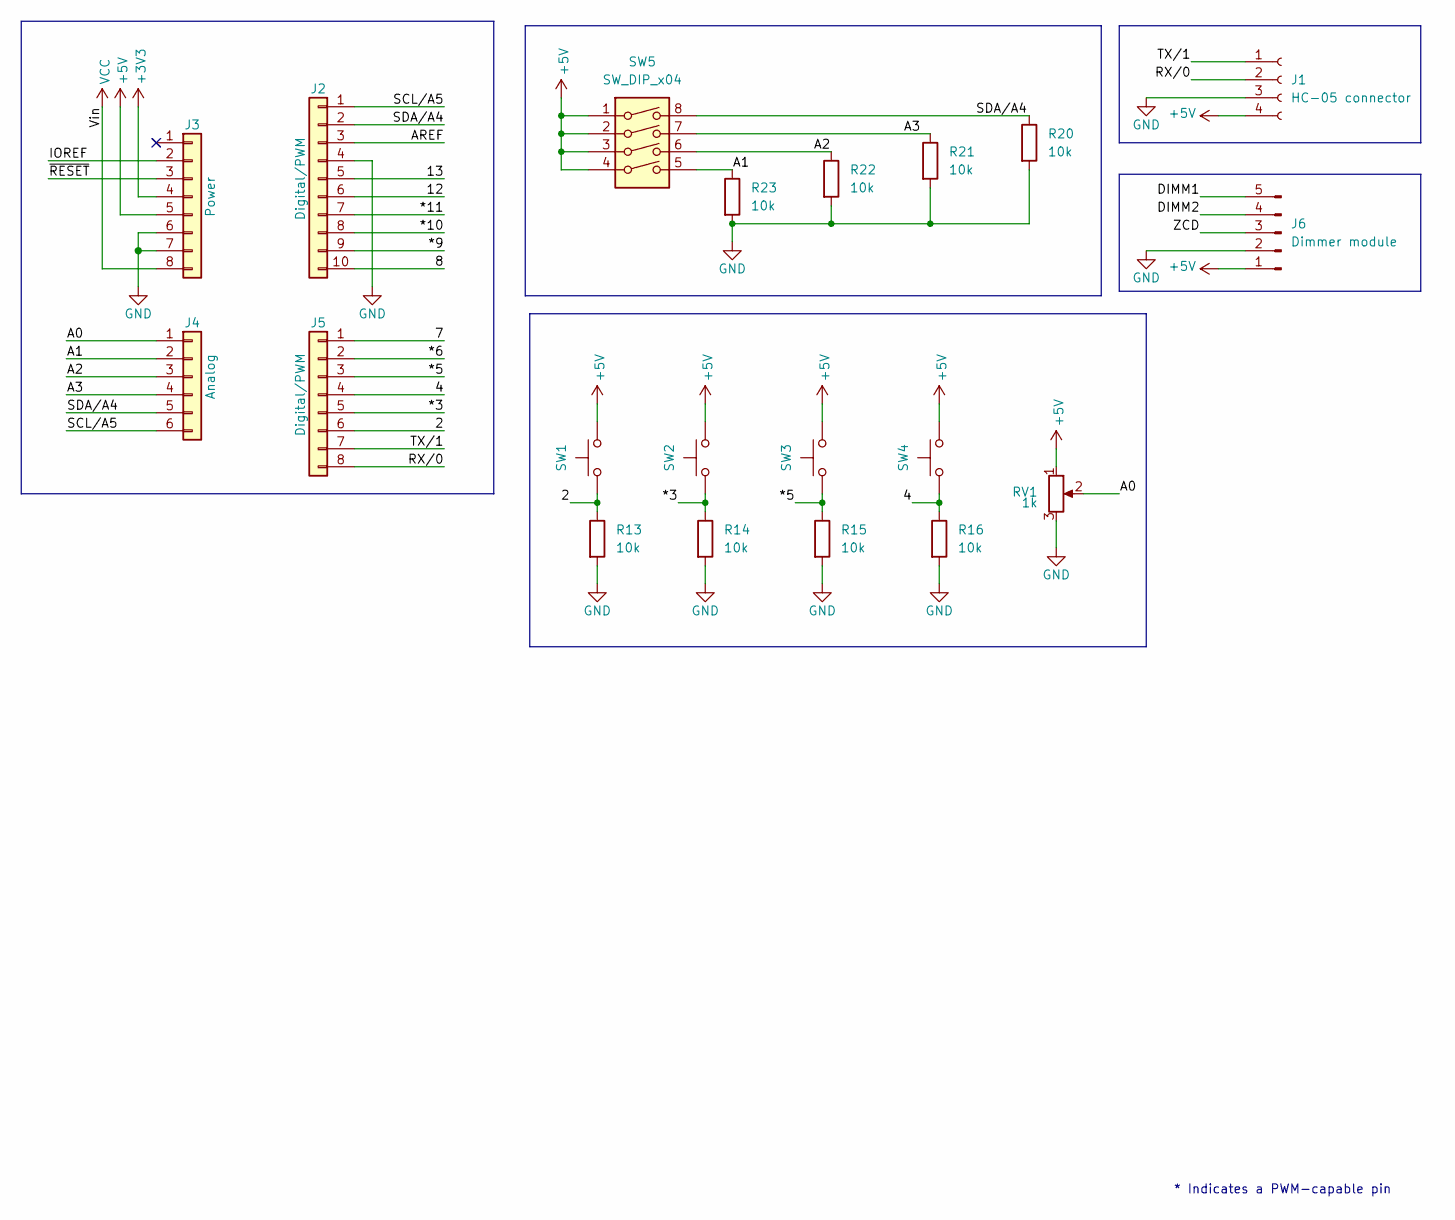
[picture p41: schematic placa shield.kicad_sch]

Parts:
J1: HC-05 connector; PinSocket_1x04_P2.54mm_Horizontal
J2: Digital/PWM; PinSocket_1x10_P2.54mm_Vertical
J3: Power; PinSocket_1x08_P2.54mm_Vertical
J4: Analog; PinSocket_1x06_P2.54mm_Vertical
J5: Digital/PWM; PinSocket_1x08_P2.54mm_Vertical
J6: Dimmer module; PinHeader_1x05_P2.54mm_Vertical
R13, R14, R15, R16, R20, R21, R22, R23: 10k; R_Axial_DIN0207_L6.3mm_D2.5mm_P7.62mm_Horizontal
RV1: 1k; Potentiometer_Alps_RK163_Single_Horizontal
SW1, SW2, SW3, SW4: SW_Push; SW_PUSH_6mm
SW5: SW_DIP_x04; SW_DIP_SPSTx04_Slide_9.78x12.34mm_W7.62mm_P2.54mm

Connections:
+3V3: J3.4
+5V: J1.4, J3.5, J6.1, RV1.1, SW1.2, SW2.2, SW3.2, SW4.2, SW5.1, SW5.2, SW5.3, SW5.4
/2: J5.6, R13.1, SW1.1
/4: J5.4, R16.1, SW4.1
/7: J5.1
/8: J2.10
/12: J2.6
/13: J2.5
/*3: J5.5, R14.1, SW2.1
/*5: J5.3, R15.1, SW3.1
/*6: J5.2
/*9: J2.9
/*10: J2.8
/*11: J2.7
/A0: J4.1, RV1.2
/A1: J4.2, R23.1, SW5.5
/A2: J4.3, R22.1, SW5.6
/A3: J4.4, R21.1, SW5.7
/AREF: J2.3
/DIMM1: J6.5
/DIMM2: J6.4
/IOREF: J3.2
/RX/0: J1.2, J5.8
/SCL/A5: J2.1, J4.6
/SDA/A4: J2.2, J4.5, R20.1, SW5.8
/TX/1: J1.1, J5.7
/ZCD: J6.3
/~RESET: J3.3
GND: J1.3, J2.4, J3.6, J3.7, J6.2, R13.2, R14.2, R15.2, R16.2, R20.2, R21.2, R22.2, R23.2, RV1.3
VCC: J3.8

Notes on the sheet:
* Indicates a PWM-capable pin

Board: 2 copper layers, 20 parts (4 on the bottom side), 14 nets, no tracks yet.

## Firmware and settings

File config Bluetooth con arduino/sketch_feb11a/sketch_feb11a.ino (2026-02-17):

#include <SoftwareSerial.h>

// RX, TX (Arduino)
SoftwareSerial bt(10, 11);

// Envia comando AT "pelado" y espera respuesta
void sendAT(const char *cmd, unsigned long wait_ms = 800) {
  Serial.print(">> ");
  Serial.println(cmd);

  // Enviar sin CR ni LF
  for (const char *p = cmd; *p; p++) {
    bt.write(*p);
  }

  delay(wait_ms);

  Serial.print("<< ");
  while (bt.available()) {
    Serial.write(bt.read());
  }
  Serial.println();
}

void setup() {
  Serial.begin(115200);
  while (!Serial) {}

  // Baud ACTUAL del HC-06 (config histórica)
  bt.begin(115200);

  Serial.println("=== Configuracion HC-06 ===");
  Serial.println("IMPORTANTE: el modulo NO debe estar conectado al celular");
  delay(500);

  // Test AT
  sendAT("AT");

  // Configuracion
  sendAT("AT+NAMEDimmer_BL");  // Nombre del dispositivo
  sendAT("AT+PIN1111");        // PIN
  

  // Si quisieras cambiar baud, por ejemplo a 115200:
  sendAT("AT+BAUD8");
  delay(1000);
  bt.end();
  bt.begin(115200);

  Serial.println("=== Configuracion finalizada ===");
  Serial.println("Apagar y prender el modulo para usarlo en modo DATA");
}

void loop() {
  // Puente libre para debug si queres
  if (Serial.available())
    bt.write(Serial.read());

  if (bt.available())
    Serial.write(bt.read());
}

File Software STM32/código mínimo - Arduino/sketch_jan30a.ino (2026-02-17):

// --------------------
// Pines
// --------------------
const uint8_t PIN_ZC     = 2;   // D2 = INT0
const uint8_t PIN_TRIAC  = 9;   // Gate triac
const uint8_t PIN_POT    = A0;  // Potenciómetro
const uint8_t PIN_DEBUG  = 8;   // Salida para trigger osciloscopio

// --------------------
// Timing
// --------------------
const unsigned long ZC_HOLDOFF_US   = 2000;
const unsigned long ZC_OFFSET_US    = 600;
const unsigned long DIMMING_MAX_US  = 7500;
const unsigned long TRIAC_PULSE_US  = 300;

// --------------------
// Variables ISR
// --------------------
volatile bool zc_flag = false;
volatile unsigned long last_zc_us = 0;
volatile bool debug_state = false;

// --------------------
// Control dimming
// --------------------
volatile unsigned long dimming_us = 0;
unsigned long last_adc_ms = 0;
const unsigned long ADC_PERIOD_MS = 50;  // leer pote cada 50 ms

// --------------------
// ISR Zero Crossing
// --------------------
void ISR_zeroCrossing() {
  unsigned long now = micros();

  if (now - last_zc_us > ZC_HOLDOFF_US) {
    last_zc_us = now;

    zc_flag = true;

    // ---- TOGGLE de referencia para el osciloscopio ----
    debug_state = !debug_state;
    digitalWrite(PIN_DEBUG, debug_state);
  }
}

// --------------------
// Setup
// --------------------
void setup() {
  pinMode(PIN_ZC, INPUT);
  pinMode(PIN_TRIAC, OUTPUT);
  pinMode(PIN_DEBUG, OUTPUT);

  digitalWrite(PIN_TRIAC, LOW);
  digitalWrite(PIN_DEBUG, LOW);

  attachInterrupt(
    digitalPinToInterrupt(PIN_ZC),
    ISR_zeroCrossing,
    RISING
  );
}

// --------------------
// Loop
// --------------------
void loop() {

  // ---- Leer ADC cada tanto ----
  if (millis() - last_adc_ms > ADC_PERIOD_MS) {
    last_adc_ms = millis();

    int adc = analogRead(PIN_POT);  // 0–1023
    dimming_us = map(adc, 0, 1023, 0, DIMMING_MAX_US);
  }

  // ---- Evento de zero crossing ----
  if (zc_flag) {
    noInterrupts();
    zc_flag = false;
    interrupts();

    // Offset fijo post ZC
    delayMicroseconds(ZC_OFFSET_US);

    // Delay variable (dimming)
    if (dimming_us > 0) {
      delayMicroseconds(dimming_us);
    }

    // Pulso al gate
    digitalWrite(PIN_TRIAC, HIGH);
    delayMicroseconds(TRIAC_PULSE_US);
    digitalWrite(PIN_TRIAC, LOW);
  }
}

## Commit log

2025-12-02 Revise use case details in README.md
    Updated use case descriptions and added details for manual control and Bluetooth handling.
2025-12-04 placa y notas de aplicación
    [placa.kicad_sch]
2025-12-04 remove hardware from sftware branch
    [placa.kicad_pcb, placa.kicad_sch]
2025-12-04 added prev work to hardware branch
    [placa.kicad_pcb, placa.kicad_sch]
2025-12-04 moved files
    arreglé tema de kicad
    [placa.kicad_pcb, placa.kicad_sch]
2025-12-05 shield arrancado
    Faltaría rutear y ver si podemos hacer algo para fabricarlo nosotros o si o si va a tener que ser doble faz. Sería interesante probar fabricar en china.
    [placa alta tension.kicad_pcb, placa alta tension.kicad_sch, placa shield.kicad_pcb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]
2025-12-05 placa 220
    [placa alta tension.kicad_pcb, placa alta tension.kicad_sch]
2025-12-09 shield acomodado
    [placa shield.kicad_sch]
2025-12-11 simuklaciones ltspice y ajustes antes de comprar comps
    [freerouting.dsn, placa alta tension.csv, placa alta tension.kicad_pcb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]
2025-12-13 consulta Fede
    [placa alta tension.kicad_pcb, placa alta tension.kicad_sch]
2025-12-14 placa v2
    [placa alta tension.kicad_pcb, placa alta tension.kicad_sch]
2025-12-14 placa v2 +
    [placa alta tension.kicad_pcb]
2025-12-17 placa terminada
    [freerouting.dsn, placa alta tension.csv, placa alta tension.kicad_pcb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]
2025-12-28 avances placa
    [U_Box_V104_Test_Cleaned.scad, back.0004.ipt, back.ipt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]
2025-12-28 ajustes finales
    verificación de simulación con LTSpice, cambio de planos.
    [dimmer.kicad_pcb, dimmer.kicad_sch, placa alta tension.csv]
2026-01-02 arreglos
    arreglos comentados en el pull request
    [dimmer.kicad_pcb, dimmer.kicad_sch]
2026-01-02 start of shield
    [placa shield.kicad_pcb]
2026-01-21 previo a fabricación
    [Shield.kicad_sch, dimmer.kicad_pcb]
2026-01-25 Informe de avances terminado
2026-01-25 Cambios de nombre
2026-01-25 correción de typos
2026-01-26 fotos de ZCD y fab para memoria técnica
    Se hicieron las pruebas con 24 VAC (y modificaciones para que funcione con 24 VAC). Funciona, se pasa a soldar y probar triacs.
2026-02-03 Create listado de cosas hechas con IA.txt
2026-02-03 Video de funcionamiento del hardware - prueba con arduino mínimo
2026-02-03 deprecated 3D files - gabinete
    [U_Box_V104_Test_Cleaned.scad, back.0004.ipt, back.ipt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]
2026-02-04 Update listado de cosas hechas con IA.txt
2026-02-05 inicio de software a partir de plantilla de cursada y pinout
    [main.cfg]
2026-02-07 inicio de etapa final
    preparando repo para agentes
2026-02-07 cambios en .ioc
    [tdse-tp2_01-model_integration (OpenOCD).cfg, tdse-tp2_01-model_integration.cfg]
2026-02-08 esquema shield actualizado con ínout final
    [Shield.kicad_sch]
2026-02-11 cambios para bluetooth, falta baudrate
2026-02-11 sketch arduino
2026-02-11 volumen buzzer y fault mode
    [task_system.c]
2026-02-11 Create guia de uso del firmware.txt
2026-02-14 agregado de timers para arreglar timings
    [app.c, app.h, task_adc.c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]
2026-02-15 adc simplificado y arreglo buzzer
    [app.h, task_adc.c, task_system.c]
2026-02-15 regreso a adc simple, BT cambiado
2026-02-17 ajustes hardware
    renombrar carpeta kicad -> hardware y anotaciones planos
    [Nucleo2USB.kicad_pcb, Nucleo2USB.sch, Shield.kicad_pcb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]
2026-02-17 cambio bluetooth
    ahora el bluetooth envia 3 bytes en vez de un json entero. esto es más facil de decodificar en la app
2026-02-17 app celular terminada
    se sube apk y proyecto de mit app inventor
2026-02-17 Actualización de la memoria técnica
2026-02-17 código prueba stm32
    [main.cfg]
2026-02-17 wcet listo, falta consumo
    [main.cfg]
2026-02-18 Clarify voltage description for Schmitt triggers
    Updated text to clarify that the voltage reached the threshold for triggering Schmitt triggers.
2026-02-19 creacion de documento de latex e inicio de correcciones
    hasta acá no son las imágenes
2026-02-19 captions y hilado de imágenes en texto
2026-02-19 Fix formatting and add line breaks in documentation
    agregué <br><br> a mano despues de todas las imagens
2026-02-19 arreglo de italica para captions
2026-02-19 Standardize formatting in consumption measurement section
    sería los cambios de 3.3 a 3,3 y dejando un espacio entre el número y la unidad.
2026-02-19 Actualización de las imágenes del Diagrama de Harel
2026-02-20 cambios de carátula, mover logo arriba
2026-02-20 que el link se vea más claro
2026-02-20 agrego entrada en tabla de revisión
